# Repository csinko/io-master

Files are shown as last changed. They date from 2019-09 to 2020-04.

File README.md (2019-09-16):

# io-master
Dominate the I/O!

## Subsystems Overviews

### [GUI](https://github.com/csinko/io-master/wiki/GUI-Subsystem)
The purpose of the GUI interface is to create a user friendly yet customizable program to help users tell the micro-controller to use whatever protocols that the user wishes to use from the provided list. The interface will include drop down menus to adjust the protocol that the board will use.  This interface will also allow the user to select what information they want to send through the device as well as start and stop the flow of information through the device. The GUI will also define the hardware pins and clock speeds needed to run whichever protocol is selected. This includes setting the voltage levels that the board will expect to see. This will define what is seen as a 1 or a 0. The gui will most likely be done using python. Possible challenges include figuring out which GUI base to use in python. Possible options are appJar, TkInter, PyQT, or Kivy. More research will be done on each to figure out which one is best suited for this project. 

### [MCU Firmware](https://github.com/csinko/io-master/wiki/MCU-Firmware-Subsystem)
The MCU is responsible for reading and writing the logic. Firmware will need to be designed to load in data from the computer, connect it to the corresponding DMA register that routes to the correct output, and stream data as it comes in. Likewise, the firmware will also need to read in data over the DMA, and transfer it to send to the computer when appropriate. Strict scheduling and context switching will need to be designed in order to ensure smooth operation at high frequencies. Other contexts will need to be considered, such as reading from one set of I/O and writing to another set, or recording logic data read in to an SD card.

### [MCU Power and Interface](https://github.com/csinko/io-master/wiki/MCU-Power-and-Interface-Subsystem)
MCU Power and Interface is responsible for receiving configuration and executing commands. These commands will come through the serial bus and need to be parsed/decoded. Execution will include adjusting the clock speed, target voltage levels, and re-configuring pins as specified by the commands received.

These capabilities will be crucial for switching between protocols on the multi-use pins. The challenges will be primarily with creating a good control scheme for managing all the necessary multiplexers to route signals to all the proper pins, at the correct speed and voltages.

### [I/O Level Shifting and Logic](https://github.com/csinko/io-master/wiki/IO-Level-Shifting-and-Logic-Subsystem)
The Level Shifting and Logic Subsystem is responsible for providing electrical conversion between the microcontroller interface and the device under test. This includes acting as an output and input to the microcontroller, providing logic-high, logic-low, and floating output states, bidirectional logic-level conversion, and capability to drive/receive differential or single-ended lines. This block should be fully configurable via control signals from the microcontroller. This includes setting the high and low voltages, optional pull-up/pull-down resistors, and multiplexing the line between single-ended and differential hardware. Design challenges include implementing a bidirectional differential transceiver and ensuring that multiplexing does not affect high speed operation.

### [Circuit Protection](https://github.com/csinko/io-master/wiki/Circuit-Protection-Subsystem)
Circuit protection is a crucial part of any device to help safeguard against unexpected and unplanned power issues. This is important to prevent injury to users, damage to the device and potentially fire. This will include having fuses, diodes, conformal coating, reverse polarity protection, over voltage protection and will protect against accidental grounding.
Some challenges that may occur is due to the learning curve of designing the circuit protection circuit. Designing a circuit that can account for over voltage protection, short circuit protection, reverse polarity protection, etc and maintain a small footprint on a circuit board could prove to be difficult. Accounting for different/higher voltage levels used by the different protocols may become a challenge.

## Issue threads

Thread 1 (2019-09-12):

Preliminary Circuit Protection Design

codeThatThinks, 2019-09-12:
- Research what kinds of things I/O pins need to be protected against
- Research possible protection circuits
- Begin preliminary schematic of protection subsystem

nuntch, 2019-09-16:
This is what I have so far:
Over voltage protection
Over current protection
Accidental grounding
Reverse polarity protection

nuntch, 2019-09-30:
Weekly update:
I have a circuit sketched to protect against reverse polarity and over current issues.
I won't be back in town until about noon today.

This week i will be taking my schematic and begin creating the design in kiCad.

Closed 2020-01-16.

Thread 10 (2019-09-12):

Make a short writeup about the GUI

csinko, 2019-09-12:
This will be put into the readme and be used for preliminary design presentations and discussions.

Cover what this component is responsible for, what it adds to the design of the project, and some challenges that will arise.  Also cover any preliminary design ideas that exist.

Metalison, 2019-09-15:
The purpose of the GUI interface is to create a user friendly yet customizable program to help users tell the micro-controller to use whatever protocols that the user wishes to use from the provided list. The interface will include drop down menus to adjust the protocol that the board will use.  This interface will also allow the user to select what information they want to send through the device as well as start and stop the flow of information through the device. The GUI will also define the hardware pins and clock speeds needed to run whichever protocol is selected. This includes setting the voltage levels that the board will expect to see. This will define what is seen as a 1 or a 0. The gui will most likely be done using python. Possible challenges include figuring out which GUI base to use in python. Possible options are appJar, TkInter, PyQT, or Kivy. More research will be done on each to figure out which one is best suited for this project.

csinko, 2019-09-16:
Looks good

Closed 2019-09-16.

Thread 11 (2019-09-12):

Make a short writeup about the Circuit Protection

csinko, 2019-09-12:
This will be put into the readme and be used for preliminary design presentations and discussions.

Cover what this component is responsible for, what it adds to the design of the project, and some challenges that will arise.  Also cover any preliminary design ideas that exist.

nuntch, 2019-09-16:
Short write up about circuit board protection
Circuit protection is a crucial part of any device to help safeguard against unexpected and unplanned power issues. This is important to prevent injury to users, damage to the device and potentially fire. This will include having fuses, diodes, conformal coating, reverse polarity protection, over voltage protection and will protect against accidental grounding.
Some challenges that may occur is due to the learning curve of designing the circuit protection circuit. Designing a circuit that can account for over voltage protection, short circuit protection, reverse polarity protection, etc and maintain a small footprint on a circuit board could prove to be difficult. Accounting for different/higher voltage levels used by the different protocols may become a challenge.

Closed 2019-09-16.

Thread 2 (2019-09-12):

Preliminary Level-Shifter Design

codeThatThinks, 2019-09-12:
Subsystem preliminary functions/requirements:
* Bi-directional level shifting from mcu logic levels (3.3v) to output logic levels (anywhere from 3.3-24v)
* Implement high, low, and tri-state (floating)
* Implement pull-up and pull-down resistors
* Selectable single-ended or differential signalling mode

codeThatThinks, 2019-09-26:
I'm going to focus first on the differential signalling portion of the design since I believe it is the part that requires the most research. I need to determine the requirements for configurable differential logic levels as well as a way to integrate it as a selectable option with the single-ended level shifter.

Here is a comparison of various common differential interfaces:

__RS-422/RS-485__
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
* Binary 1: -6V < A - B < -200mV
* Binary 0: +200mV < A - B < +6V
* Common Mode: -10 to +10V (RS-422), -7 to +12V (RS-485)
* Termination, pull-up, pull-down resistors required
* Up to 10 Mbit/s

__CAN (ISO 11898)__
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
* Binary 1 (Recessive): -1V < CANH - CANL < +0.5V
* Binary 0 (Dominant): +0.9V < CANH - CANL < +5V
* Common Mode: -2 to +7V
* Termination, pull-up, pull-down resistors required
* Up to 2Mbit/s

__LVDS (TIA-644)__
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
* 350mV voltage swing, 1.2V common mode offset typical
* Current direction determines logic state
* Terminator resistor required
* 655 Mbit/s (up to 3Gbit/s possible)

_References_
* [RS-422 and RS-485 Standards Overview and System Configurations](https://www.ti.com/lit/an/slla070d/slla070d.pdf)
* [A CAN Physical Layer Discussion](http://ww1.microchip.com/downloads/en/AppNotes/00228a.pdf)
* [Basic Principles of LVDS](https://www.thine.co.jp/en/contents/articles_detail/serdes-lvds.html)

codeThatThinks, 2019-09-26:
Clearly a differential driver/receiver must be able to handle interfaces where pairs are simply inverted (e.g. RS-485) and interfaces where pairs are mirrored (e.g. CAN) and hover around a common voltage. The specific logic levels vary significantly between interfaces, so differential hardware likely needs to include level shifting of its own and not rely on the single-ended level shifting hardware.

A revised block diagram might look like the following:

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

I will have to determine if an off the shelf transceiver chip can be used. The challenge here will be finding something where differential logic levels can be selected. Maybe a circuit could be placed on the front end of the transceiver to shift voltages? Depending on the differential spec, up to 4 separate voltage rails might be needed, each programmable, and 4 for each I/O channel/pair.

If it came down to implementing a custom transceiver, there are multiple approaches. A naive solution might be to provide 4 configurable voltage rails: 1 for each voltage state of each differential line. This would allow for maximum configurability for any differential scheme, at the expense of requiring many voltage rails when scaling up the number of I/O channels. A better solution might be to take advantage of the symmetry of the differential pair. Use 2 voltage rails to define the two voltage states for one differential line, then invert the signal to use as the opposite line.

Closed 2020-01-16.

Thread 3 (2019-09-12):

Preliminary Microcontroller Schematic

codeThatThinks, 2019-09-12:
Draw up a schematic for the STM32F7 chip including power supply for mcu.

- Find/create KiCAD symbol for mcu
- Voltage regulator for mcu
- Decouping

Closed 2020-01-16.

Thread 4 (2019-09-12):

Research GUI options for Python

csinko, 2019-09-12:
We will want a UI for users to define, edit, and select protocols for our tool.  Users will need to be able to

- Define clock signal speeds
- Set expected voltage levels
- Define ranges for a logic 0 and a logic 1
- Give names and descriptions for protocols
- Select protocols being used, assign pins
- Select data to send
- Start and stop the device, along with other operations

There are a few options I am aware of that can be used for GUIs in Python
PyQT
Tkinter
Kivy

Do research and testing on these frameworks, and get a feel for making GUI elements with Python.  Decide the pros and cons of all the frameworks you test, and we will decide which one to use officially for the project.

codeThatThinks, 2019-09-26:
Check out ```guizero```, it's a Python library that makes it much easier to use TkInter. https://lawsie.github.io/guizero/

Metalison, 2019-09-30:
Weekly Update:
Started practicing using tkinter. A window appears and it has words and buttons that work.

nuntch, 2019-10-10:
See google drive for the requirements needed for GUI sketch.
Due by our next meeting with French. 10/17/19

Closed 2020-01-16.

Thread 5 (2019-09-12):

Research and Test Clock Inputs with MCU

csinko, 2019-09-12:
We will need to be able to patch in and switch between different frequencies for the project.   The MCU has the ability to use an external clock, but we need the flexibility to set these clocks and assign them to various I/O lines (potentially multiple lines simultaneously.

Learn how to read in and use external clock signals, make a test application to utilize external clock signals, and determine how we can control where a clock signal connects to, whether its through software routing or hardware routing (mux, demux, etc.)

WhoDaWhatNow, 2019-09-26:
STM32H743 Datasheet link: https://www.st.com/resource/en/datasheet/stm32h743bi.pdf
page 126 talks about clock inputs

STM Timers: https://www.st.com/content/ccc/resource/technical/document/application_note/group0/91/01/84/3f/7c/67/41/3f/DM00236305/files/DM00236305.pdf/jcr:content/translations/e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

Closed 2020-01-16.

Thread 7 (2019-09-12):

Make a short writeup about the I/O Level Shifting And Logic

csinko, 2019-09-12:
This will be put into the readme and be used for preliminary design presentations and discussions.

Cover what this component is responsible for, what it adds to the design of the project, and some challenges that will arise.  Also cover any preliminary design ideas that exist.

codeThatThinks, 2019-09-16:
The Level Shifting and Logic Subsystem is responsible for providing electrical conversion between the microcontroller interface and the device under test. This includes acting as an output and input to the microcontroller, providing logic-high, logic-low, and floating output states, bidirectional logic-level conversion, and capability to drive/receive differential or single-ended lines. This block should be fully configurable via control signals from the microcontroller. This includes setting the high and low voltages, optional pull-up/pull-down resistors, and multiplexing the line between single-ended and differential hardware. Design challenges include implementing a bidirectional differential transceiver and ensuring that multiplexing does not affect high speed operation.

Closed 2019-09-16.

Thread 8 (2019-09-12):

Make a short writeup about the MCU power and interface

csinko, 2019-09-12:
This will be put into the readme and be used for preliminary design presentations and discussions.

Cover what this component is responsible for, what it adds to the design of the project, and some challenges that will arise.  Also cover any preliminary design ideas that exist.

WhoDaWhatNow, 2019-09-16:
MCU Power and Interface is responsible for receiving configuration and executing commands. These commands will come through the serial bus and need to be parsed/decoded. Execution will include adjusting the clock speed, target voltage levels, and re-configuring pins as specified by the commands received.

These capabilities will be crucial for switching between protocols on the multi-use pins. The challenges will be primarily with creating a good control scheme for managing all the necessary multiplexers to route signals to all the proper pins, at the correct speed and voltages.

WhoDaWhatNow, 2019-09-16:
@csinko Is this good?

csinko, 2019-09-16:
looks good

Closed 2019-09-16.

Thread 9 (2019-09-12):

Make a short writeup about the MCU Firmware

csinko, 2019-09-12:
This will be put into the readme and be used for preliminary design presentations and discussions.

Cover what this component is responsible for, what it adds to the design of the project, and some challenges that will arise.  Also cover any preliminary design ideas that exist.

csinko, 2019-09-16:
The MCU is responsible for reading and writing the logic.  Firmware will need to be designed to load in data from the computer, connect it to the corresponding DMA register that routes to the correct output, and stream data as it comes in.  Likewise, the firmware will also need to read in data over the DMA, and transfer it to send to the computer when appropriate.  Strict scheduling and context switching will need to be designed in order to ensure smooth operation at high frequencies.  Other contexts will need to be considered, such as reading from one set of I/O and writing to another set, or recording logic data read in to an SD card.

Closed 2019-09-16.

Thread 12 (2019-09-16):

Create DMA Routing program

csinko, 2019-09-16:
To better learn how to operate DMA and to get an idea of the flexibility possible, create a program that reads data from one interface into DMA, then outputs the data out another interface.

Attempt any forms of optimizations that seem possible to limit the amount of interrupts.  Also do tests to limit the amount of memory used in the buffer when streaming data, as this will open up opportunities to increase the throughput of the device

Closed 2020-01-16.

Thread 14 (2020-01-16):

Determine USB Protocol Implementation for High Speed I/O

csinko, 2020-01-16:

csinko, 2020-01-26:
Currently investigating using this: https://github.com/IntergatedCircuits/IPoverUSB

This library will let us use an NCM based USB device to transmit data like an IP-based device.

It supports the STM32F4 but not the H7.  I am in the process of porting over the code to run on the H7, but it is bare metal so there are a lot of things to change

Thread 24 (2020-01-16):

Design Command Structure for Board Configuration

csinko, 2020-01-16:
Come up with a list of commands that we need to implement, and figure out how many bits are needed for them.

Then create a document that lists what each command is, how to use it, etc.

Also determine any sort of machine states are necessary for the device to accept the command.  i.e. It wouldn't make sense to change the frequency while sending data!

WhoDaWhatNow, 2020-01-30:
https://docs.google.com/spreadsheets/d/1bnIgJ0D3f-U6nXkwTM4AM9xzIl1RVUJrsCMVExMmpjs/edit#gid=0

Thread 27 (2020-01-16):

Determine what pins we need for I/O

csinko, 2020-01-16:
Finalize what pins we are going to use

codeThatThinks, 2020-01-31:
The pin allocation spreadsheet lists all the pins we are going to use.

TLDR:
- ULPI interface used to communicate with USB PHY, these pins cannot be reassigned
- PORTD is used only for high speed digital outputs to the level shifter (low byte is IO_x_OUT, high byte is IO_x_TRIS)
- PORTE is used only for high speed digital inputs from the level shifter (low byte is NC, high byte is IO_x_IN)
- There is a dedicated hardware timer that is tied to each high speed digital output used for clock generation. Simply enable tristate for the PORTD pin and disable tristate for the timer output pin.
- I2C1 is used for communication to all level shifter DACs.
- USART1 will be broken out with test points in case it needs to be used for debugging/DFU mode
- DAC_OUT1 is used to control the adjustable regualtor for powering the target device

codeThatThinks, 2020-02-13:
@WhoDaWhatNow I've changed some of the pin assignments in order to make the board layout easier. Please review the spreadsheet on drive.

Closed 2020-01-31.

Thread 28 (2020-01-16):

Microcontroller subsystem schematic

codeThatThinks, 2020-01-16:
Draw up a schematic of the STM32H7 with:

- Power supply and decoupling
    --Pick a 3.3v linear regulator (maybe a 250mA)
- Crystal oscillator and clock source
    --Do we need two, one for the CPU, one for the USB
    --Capacitors needed as well
- Reset circuit
    --Hardware reset button
    --How did the development board do it?
- Programming/debug header
- USB interface
    --See USB issue

Closed 2020-01-28.

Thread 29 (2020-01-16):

USB PHY circuit design

codeThatThinks, 2020-01-16:
Choose a USB PHY from Digikey so that we can used USB 2.0 High Speed on the microcontroller. Draw up a schematic with USB connector, USB protection, PHY chip, and microcontroller interface.

csinko, 2020-01-26:
I would like to review which design is selected before we order it.  There's many options for the USB interface that I am using and I want to make sure what we both use are compatible with eachother.

I would expect it to be regular USB HS, but I am seeing a lot of stuff relating to OTG, which seems odd.  Its possible that portion of the library is used for other functions, the pins are shared, or something of that sort.

nuntch, 2020-01-28:
Schematic is done. Waiting for review on 1/30.

codeThatThinks, 2020-01-30:
ST refers to the built-in USB peripheral on the MCU as "USB OTG" even though it supports a variety of USB modes, including host, device, and OTG (switchable between host/device).

I/O Master will likely use the HS Device mode with an external PHY. The Microchip USB3300 PHY uses a ULPI interface to communicate with the MCU. This interface uses different pins and does not include the MCU's USB D+ and D-. We will include test points for the MCU D+ and D- pins in case we ever want to use the built-in USB PHY for full speed.

The pin allocation spreadsheet lists the pins used for the ULPI interface.

Closed 2020-01-30.

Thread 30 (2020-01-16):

Redesign level shifter

codeThatThinks, 2020-01-16:
Redesign the level shifter to include a proper gate driver so that 10MHz can be achieved.

- discrete output stage with gate driver
- discrete input stage with proper voltage range
- draw up pull-up/pull-down/termination resistors

codeThatThinks, 2020-01-21:
The output driver has been completely redesigned for switching speed. Given the original engineering specs regarding voltage levels, 20MHz is not possible without a significantly more complex system.

The voltage rails have been reduced to +/-15V and the bidirectional FETs have been replaced with a simpler PMOS/NMOS pair to make the driver requirements easier. The transistors were selected based on threshold voltage, gate charge, and input capacitance with the lowest allowable voltage rating so fast switching speeds can be achieved. Package size was reduced and both transistors are combined into a single package to minimize parasitic capacitances and inductances. A discrete isolated gate driver is likely too complex to realistically implement, so the Si8275 dual gate driver was selected. Since at 20Mbps the pulse width is 50ns, the Si8275 with a 12ns rise/fall time will be pushed to its limit on switching speed. The practical output frequency is likely just under 20MHz.

Since the gate drive voltages are fixed at +/-15V to ensure that the transistors are fully on/off at all possible logic levels, this driver will likely have a lot of EMI due to a high dv/dt. The control software should limit output voltage/switching speed, e.g. no more than 5V @ 20MHz (1e9 V/s), to limit the EMI on the transistor drains. Resistors have been included on the transistor gates so that the rise and fall times can be fine tuned on the bench.

For rev 2, the level shifter system design should be reconsidered. A direct digital synthesis approach might be better suited to achieve less EMI and better rise times. A high speed DAC could be used to generate a 0-3.3V waveform and then scale it up to +/-15V with a high speed amplifier. The lack of discrete transistors would allow for a much greater switching speed and the highest switching voltage anywhere in the level shifter would never exceed the maximum waveform voltage, allowing dv/dt to be tightly controlled by software.

codeThatThinks, 2020-01-28:
The output driver has been changed again to a high-speed op-amp and high-speed analog switch. The power rails of the op-amp are set to the desired logic level voltages and the analog switch can be used to disconnect the op-amp from the output for tri-state mode.

This configuration is simpler than the gate driver setup, with the benefit of less EMI since we're no longer switching +/-15V for the gate drive. Testing needs to be done to determine if the performance is good enough considering the op-amp's recommended voltage range, bandwidth, and slew rate, as well as whether the analog switch can be enabled quickly to achieve 400KHz I2C operation.

codeThatThinks, 2020-01-28:
The receiver has been redesigned so that the comparator is actually operating within its recommended input voltage range. My research suggests that op-amps operating in an open-loop configuration as comparators should be avoided. However, high voltage comparators are not readily available with the speed requirements we need.

The new receiver design uses the LM7171 high-speed op-amp to scale down the input voltage from +/-15V to 0~3.3V in a way very similar to the scaling of the DAC outputs. This resulting 3.3V signal can then be used with a lower voltage high-speed comparator. The receiver threshold voltages must also be scaled down, but since they are generated by scaling the DAC outputs, the comparator can use the DAC output directly to avoid scaling up followed by scaling down. A third LM7171 is used to take the difference between the I/O pins when in differential mode. An additional single channel DAC has been added to generate the differential receiver threshold voltage. This simplifies the hardware design for generating this voltage, as it depends on whether either I/O pin is inverted in software. Two SPDT analog switches are used to multiplex the input signal and threshold voltage for one of the comparators. In single-ended mode, the comparator uses the I/O pin input signal directly and the average of the logic level voltages, (VH + VL) / 2, as a threshold. In differential mode, the comparator uses the difference signal as input and the DAC-generated threshold voltage.

Closed 2020-01-28.

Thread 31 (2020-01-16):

Design adjustable regulator

codeThatThinks, 2020-01-16:
Design an adjustable regulator for powering the target device. Must be 3-24V output, 100mA.

Closed 2020-02-02.

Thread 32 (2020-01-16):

Review level shifter DAC design

codeThatThinks, 2020-01-16:
- Check DAC reference voltage
- Check op-amp gain and resistor tolerances
- Maybe add calibration using mcu adc pins?

codeThatThinks, 2020-01-27:
It seems that all Microchip DACs default to the interval reference on power up. This is not an issue, just another step that software needs to take when initializing everything.

codeThatThinks, 2020-01-27:
The op-amp gain equation for the demo board is:

```Vout = 1000/68 * (1.65 - Vdac)```

With +/-24V rails, the target gain was 48/3.3 = 14.545, so using standard resistor values the gain is a little off, 1000/68 = 14.705.

The resistors are 1% tolerance. If the resistors are at the opposite ends of their tolerance, and the DAC output is at its maximum, then the output is actually:

```(1000 * 1.01)/(68 * 0.99) * (1.65 - 3.3) = -24.755```

That is an error of 0.755V, which is significant. Note, this is an approximation since the actual gain equation is more complicated when the resistance is not the same for each pair of resistors, so in reality the output would be off by even more.

For rev 1, the power rails are now +/-15V, so the new gain equation is:

```Vout = 1000/110 * (1.65 - Vdac)```

This ratio of nominal resistor values actually matches the target gain, where 1000/110 = 30/3.3 = 9.09. If 1% resistors are used, then the maximum error is approximately 0.303V. This is still probably too much, as it should really be somewhere around +/-0.1V. Therefore, 0.1% resistors should be used.

codeThatThinks, 2020-01-27:
The differential receiver threshold voltage will be replaced with a 1 channel DAC for rev 1. This simplifies the board layout a lot and cuts down on the BOM cost. This way, the software will have to calculate the required receiver threshold voltage and set it when switching to differential mode. If this were to be done in hardware, a 4 channel 4:1 demux (a 24 pin chip) + dual opamp circuit would be required to handle all of the threshold voltage combinations depending on whether or not the microcontroller output is inverted. That is for each I/O channel pair. (We need to be able to invert an I/O channel output in software in order to handle some differential protocols).

I've chosen the 1 channel version of the MCP4728, which is the MCP4725. An op-amp circuit similar to the 4 ch DAC will be used to scale the output to +/-15V.

codeThatThinks, 2020-01-27:
I think we will have enough pins free on the MCU to run each DAC output to an ADC channel. For 4 I/O channels, that will be (4 + 1) * 2 = 10 DAC outputs. We can choose whether or not we want to use this for calibration, and whether or not we need it, but for rev 1 I will include it on the board.

We might run into issues noise coupling onto the ADC lines, which might make calibration difficult/impossible, but we need to build it to find out.

Closed 2020-01-27.

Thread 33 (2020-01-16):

Investigate VCO

codeThatThinks, 2020-01-16:
- See if a VCO with digital interface can be used to prevent clock jitter
- Look at generating required clocks internally

codeThatThinks, 2020-01-30:
After some research, it doesn't seem feasible to use a VCO. Most VCOs are analog input, which might not be able to generate a stable clock due to noise on the analog input.

Closed 2020-01-30.

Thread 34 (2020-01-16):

Circuit Protection Schematic

codeThatThinks, 2020-01-16:
Draw up the circuit protection circuit in Kicad that was used during the end of semester demo.

nuntch, 2020-01-30:
Design created in KiCad, ready for PCB design

Closed 2020-01-30.

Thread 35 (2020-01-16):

Rev 1 Schematic and BOM

codeThatThinks, 2020-01-16:
Combine all subsystem schematics into one complete KiCAD project. Generate a BOM.

codeThatThinks, 2020-01-30:
TODO before design review:
- [ ] Microcontroller pin assignments
- [ ] Finish adjustable regulator design
- [ ] LEDs on microcontroller I/O to level shifter
- [ ] Choose a connector for I/O pin connection to target device
- [ ] Choose indicator LEDs for power rails, calculate resistor values
- [ ] Add fuse or current shunt on main power input?
- [ ] Add fuse on target device power output
- [ ] Add test points for UART and built-in USB on microcontroller

codeThatThinks, 2020-02-02:
For rev 1, we can just go with a 0.1" female header. We can explore other connector possibilities for rev 2.

codeThatThinks, 2020-02-05:
Minor schematic issues have been fixed. A FET was added on the power input circuit so that the DC jack is always used instead of USB whenever it is plugged in (before it was whichever was higher voltage).

The SPDT switch on the level shifter input circuit was replaced with a part that actually has a +/-15V operating voltage range.

Component values were updated and schematic text was revised.

codeThatThinks, 2020-02-05:
The BOM is complete and the schematic is ready for a design review.

Closed 2020-02-05.

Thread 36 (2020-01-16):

Rev 1 PCB Layout

codeThatThinks, 2020-01-16:
Draw up a complete PCB design with all subsystems.

codeThatThinks, 2020-02-05:
All custom footprints that we need have been created.

codeThatThinks, 2020-02-13:
PCB layout is complete and it has been ordered from OSH Park.

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

Closed 2020-02-13.

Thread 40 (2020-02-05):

Rev 1 Design Review

codeThatThinks, 2020-02-05:
A thorough design review is needed of the Rev 1 schematic, BOM, and PCB layout.

This is a placeholder for any issues that come up.

- [ ] lorem ipsum

Closed 2020-02-13.

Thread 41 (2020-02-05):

Optimize Pull-up/Pull-down Circuit

codeThatThinks, 2020-02-05:
Redesign the pull-up/pull-down circuit so that the control pins are multiplexed. Idea: use a tri-state output to control them (LOW: pull-down enabled, HIGH: pull-up enabled, High-Z: both disabled)

This would save 8 MCU pins, allowing us to use the LQFP100 package: 8 PU, 8 PD pins -> 8 PU/PD pins

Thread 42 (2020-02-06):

Optimize +/-15V Regulator

codeThatThinks, 2020-02-06:
- Calculate actual required current rating and adjust circuit design
- Recalculate inductor sizing
- Investigate cheaper alternatives to ADP5070 chip

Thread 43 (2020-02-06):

Optimize Level Shifter

codeThatThinks, 2020-02-06:
- Investigate more cost effective designs

- Output Driver ideas
  - MCU -> DAC -> Linear Amplifier
  - MCU -> Shift Register -> High Speed Mux -> Parallel DAC -> Linear Amplifier

- Receiver ideas
  - ???

codeThatThinks, 2020-02-20:
The high speed op-amps have a much higher quiescent current than expected. For 10 op-amps, the quiescent current is ~43mA per power rail, for a total of 1.27W.

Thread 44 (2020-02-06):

Determine Mid-Term Demo

codeThatThinks, 2020-02-06:
Choose a specific SPI device for the mid-term demo. Make a write up with the following:

- Specific device and communication specs
- Info from datasheet that the end user would need to know
- What capabilities of the I/O Master are actually being demonstrated

codeThatThinks, 2020-02-06:
We will use a Sparkfun SerLCD module. This is an OLED module with UART, I2C, and SPI interfaces. It's a character display, so we will only need to send it ASCII text and it will display it. This module supports 4-wire SPI communication, so we can demonstrate sending and receiving data.

In Stock @ Digikey
https://www.digikey.com/short/z3mmwr
P/N: 1568-1904-ND

codeThatThinks, 2020-02-06:
Demo will consist of:
- Send text string to module, display on screen
- Send read version command to module, read version number

codeThatThinks, 2020-02-20:
SPI Data for Demo:

* __Clear the display, move cursor to home position__
  * Begin communication (CS low)
  * 0x7C "|" (enter settings mode)
  * 0x2D "-" (clear display, move cursor to home)
  * End communication (CS high)
* __Send "I/O MASTER" to display__
  * Begin communication (CS low)
  * 0x49 "I"
  * 0x2F "/"
  * 0x4F "O"
  * 0x20 " "
  * 0x4D "M"
  * 0x41 "A"
  * 0x53 "S"
  * 0x54 "T"
  * 0x45 "E"
  * 0x52 "R"
  * End communication (CS high)

The SerLCD doesn't actually send any data back for any commands. We will need to modify the Arduino firmware to reply to the firmware version command. An FTDI adapter can be used to update the firmware.

codeThatThinks, 2020-02-20:
SPI communication is Mode 0:
- CPOL = 0
- CPHA = 0

codeThatThinks, 2020-02-20:
SerLCD firmware has been modified to send firmware version over SPI: https://github.com/codeThatThinks/OpenLCD.

* __Read firmware version from display__
  * Begin communication (CS low)
  * 0x49 "|"
  * 0x2C "," (read firmware version)
  * 0x00 (read byte on MISO)
  * 0x00 (read byte on MISO)
  * 0x00 (read byte on MISO)
  * 0x00 (read byte on MISO)
  * End communication (CS high)

Closed 2020-02-20.

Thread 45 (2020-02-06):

Determine Final Demo

codeThatThinks, 2020-02-06:
Choose specific devices that demonstrate SPI, I2C, RS-232, RS-485, and SWD communication, as well as all of the key features of the I/O Master.

codeThatThinks, 2020-02-06:
SPI
- Sparkfun SerLCD, up to 4Mbps
- 1568-1904-ND

I2C
- MPL115A2 Temperature/Barometric Pressure Sensor, up to 400KHz
- 1528-1172-ND

RS-232
- FTDI RS-232 to USB adapter, send to computer, up to 2Mbps

RS-485
- AMT213A-V Rotary Encoder, 2Mbps
- 102-4526-ND

SWD
- Verify the program on an STM32 Blue Pill

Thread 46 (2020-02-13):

Optimize Overcurrent Protection Circuit

codeThatThinks, 2020-02-13:
See if we can redesign this circuit to use discrete transistors instead of op-amps. We need to reduce the part count and BOM cost.

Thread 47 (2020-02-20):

Setup Boot Sequence and initialization steps for MCU

csinko, 2020-02-20:
The following must be initialized for the MCU upon startup:

- All pins should be configured as inputs on first boot

When a configuration is set, the following must be changed to outputs for each IO Pin:
- Output pin -> Output, Timer Pin -> Input, Input Pin -> Input
- Output pin -> Input, Timer Pin -> Output, Input Pin -> Input
- Output pin -> Input, Timer Pin -> Input, Input Pin -> Input

^^ These are the only states that should be allowed

When switching between output pin and timer pin, MUST switch BOTH output pin and timer pins to inputs before setting the other pin as an output.  This ensures we do not short anything on the board.

**All Unused pins should be set to output and driven low.**

The Termination and Pulldown resistor control pins along with the tristate pins are active low, so they should be set high when made into outputs

The differential pins are active high, set to low when made an output (default to single ended)

The DAC needs to be set to whatever value correlates to ~1.4 volts (needs calculated)

@codeThatThinks, we also need to measure the amount of time it takes for the DAC to be set from first turning on with a scope.

csinko, 2020-02-22:
All of the initial pin configuration has been done with 5f4e88aaa68fd4bc49f22c1297d72b6442a4038c

The gpio.c file contains all of the initialization code for the pins: https://github.com/csinko/io-master/blob/5f4e88aaa68fd4bc49f22c1297d72b6442a4038c/mcu/io_master/mcu/stm32h743/src/gpio.c

Still need to add code to handle controlling the I/O Pin states for the above modes, handle the DAC, and need to test that all of the added code is working

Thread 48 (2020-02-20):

Rev 2 Schematic and BOM

codeThatThinks, 2020-02-20:
Revise the schematic and BOM for the I/O Master v2 hardware.

codeThatThinks, 2020-02-20:
TODO before design review:

- [ ] Adjustable regulator enable pin should be wired to the mcu with a pull down

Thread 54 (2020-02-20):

Optimize 3.3V Regulator

codeThatThinks, 2020-02-20:
The current linear regulator dissipates 1.555W of heat when using the 12V DC input. Total 3.3V rail load is estimated at about 178mA, so the regulator should be replaced with one spec'd for 200mA. We might want to change it to a switching regulator in order to improve efficiency.

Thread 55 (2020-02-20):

Optimize Power Input Circuit

codeThatThinks, 2020-02-20:
The power input OR'ing diodes dissipate a significant amount of power when operating near maximum power input. The USB FET switch dissipates a lot less power (0.018W vs. 0.160W).

We might want to investigate using ideal diodes or somehow eliminating the OR'ing diodes.

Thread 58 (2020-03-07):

MCU Voltage Levels Not Close to 0V/3.3V

codeThatThinks, 2020-03-07:
The MCU logic levels on the IO_OUT, IO_TRIS, IO_CLK pins do not appear to be close to the expected HIGH/LOW voltages: 3.3V and 0V. The issue is mainly with the LOW voltage.

codeThatThinks, 2020-03-07:
All MCU pins have 100K pull-up/pull-down resistors to set a defined state when the MCU pin is not being driven (i.e. MCU is starting up, pin configured as an input, etc.).

Upon inspection of the circuit connected to the MCU pin, it appears that the pin voltage can rise above 0V in a specific situation.

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

When the IO_TRIS pin is set HIGH (3.3V), the combination of the LED current limiting resistor and pull down resistor form a voltage divider, causing the voltage on the MCU pin to go to ~0.7V. When IO_TRIS is LOW (0V), this issue does not exist. This issue also does not exist when the MCU is actively driving the pin HIGH and LOW.

For Rev 2, the output LED should be changed so that it is no longer between two MCU pins. The IO_TRIS pin should get its own indicator LED.

codeThatThinks, 2020-03-07:
More bench testing with the LM7171 on a breakout board:

The LM7171 inputs appear to float to ~5V when not connected to anything. With the inverting input tied to 1.65V and the non-inverting input pulled down to ground through a 100K resistor, the voltage on the non-inverting input is around 0.228V. This indicates an input current of around 2uA. It might be a good idea to make the pull down resistors smaller, possibly 10K.

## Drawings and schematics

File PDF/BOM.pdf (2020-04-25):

I/O Master v1.0 - Populated Parts | Qty 1 | Qty 100

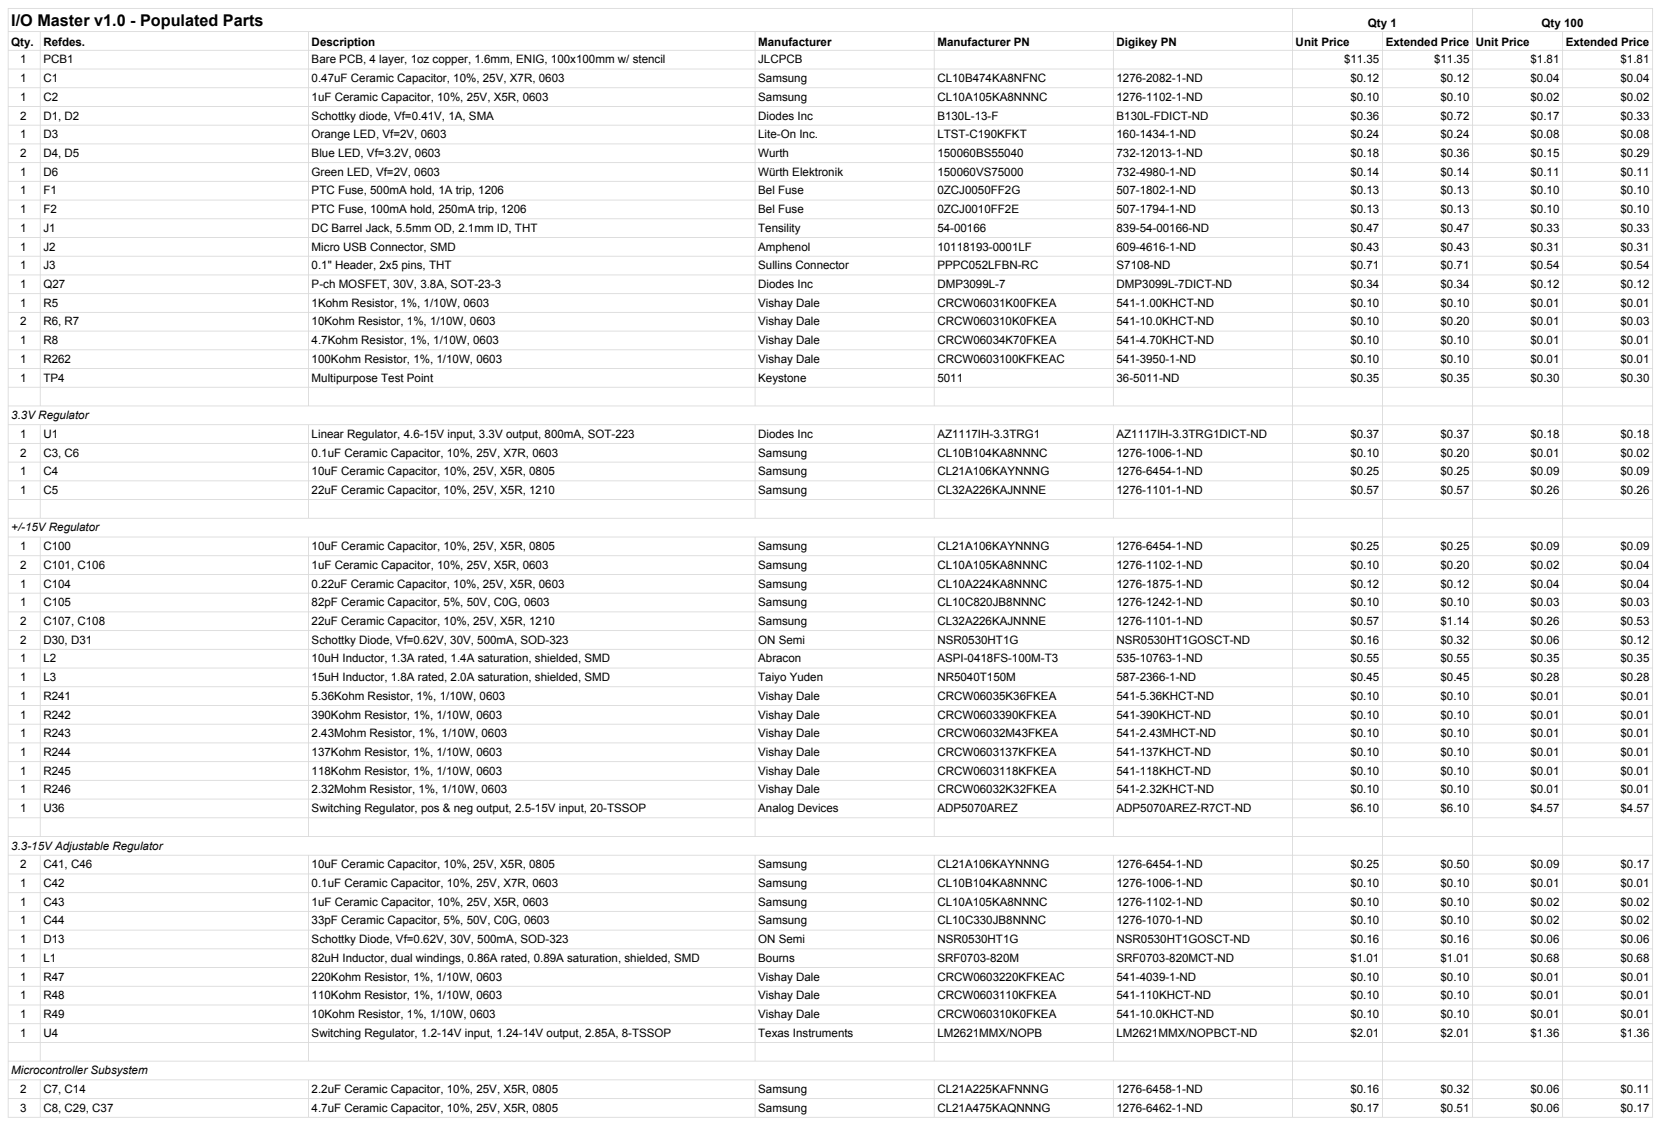
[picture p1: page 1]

I/O Master v1.0 - Populated Parts | Qty 1 | Qty 100

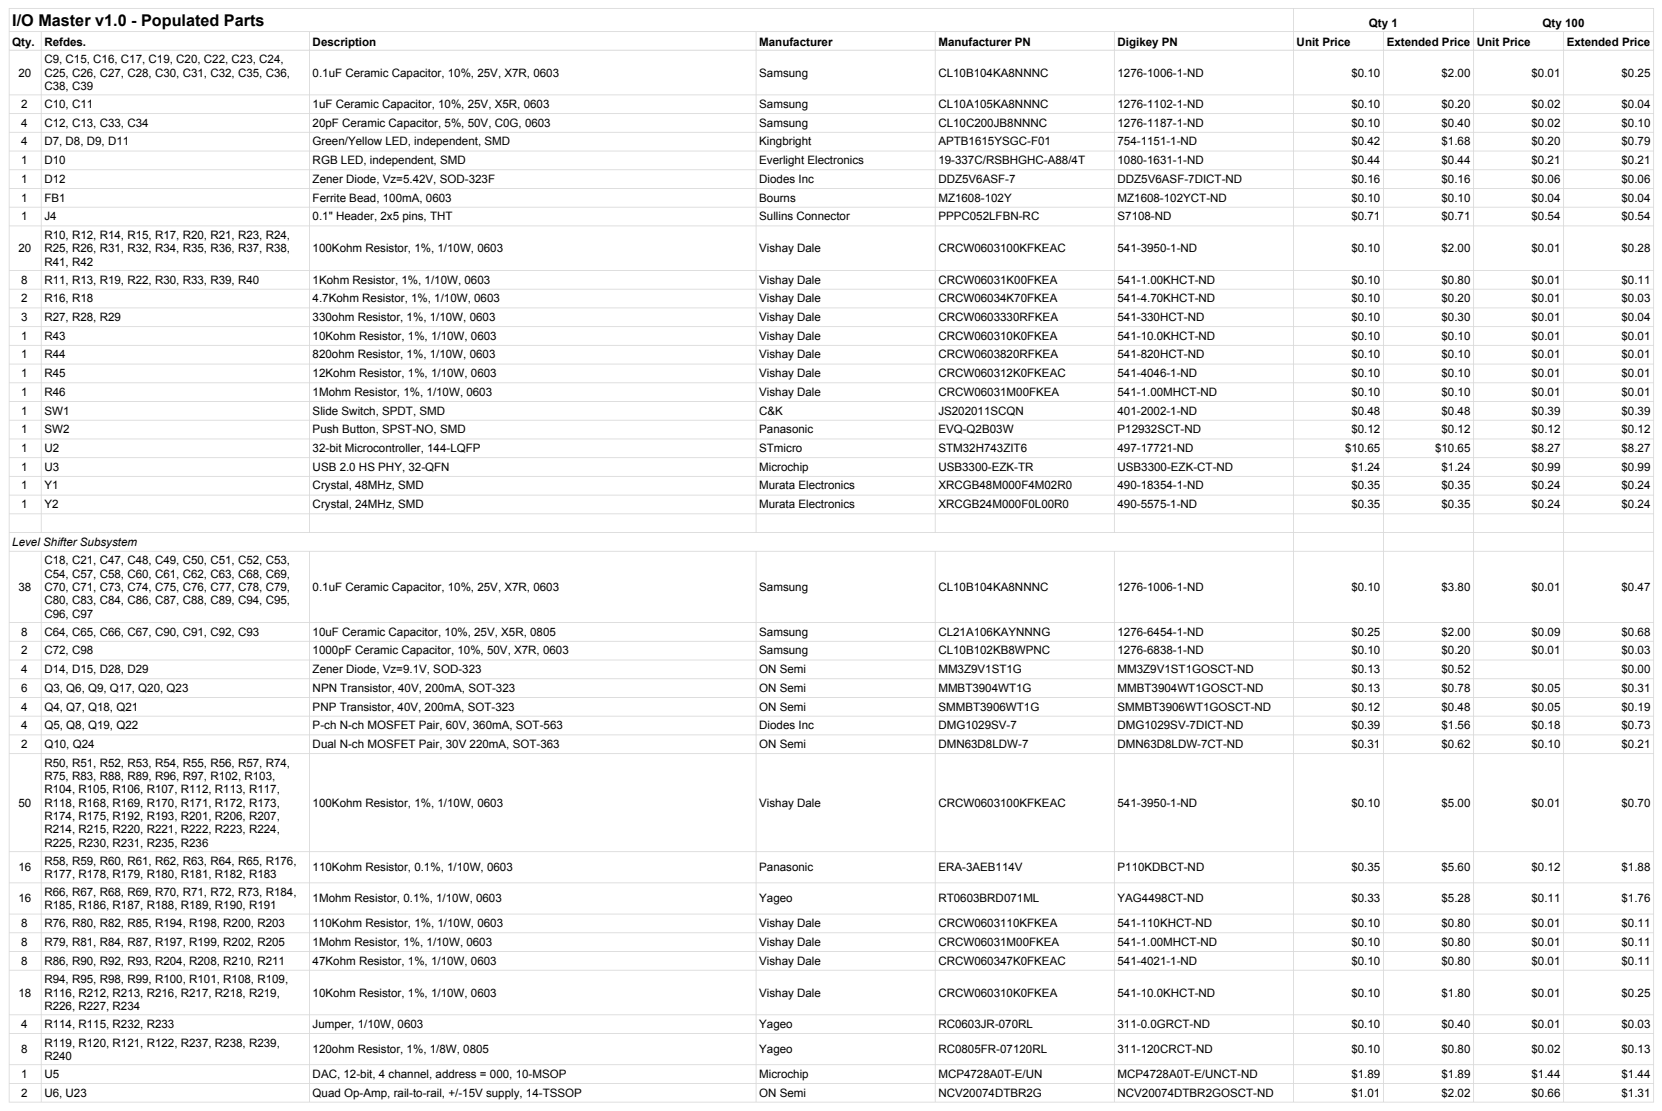
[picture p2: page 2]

Qty. | Refdes. | Description | Manufacturer | Manufacturer PN | Digikey PN | Unit Price | Extended Price | Unit Price | Extended Price

I/O Master v1.0 - Populated Parts | Qty 1 | Qty 100

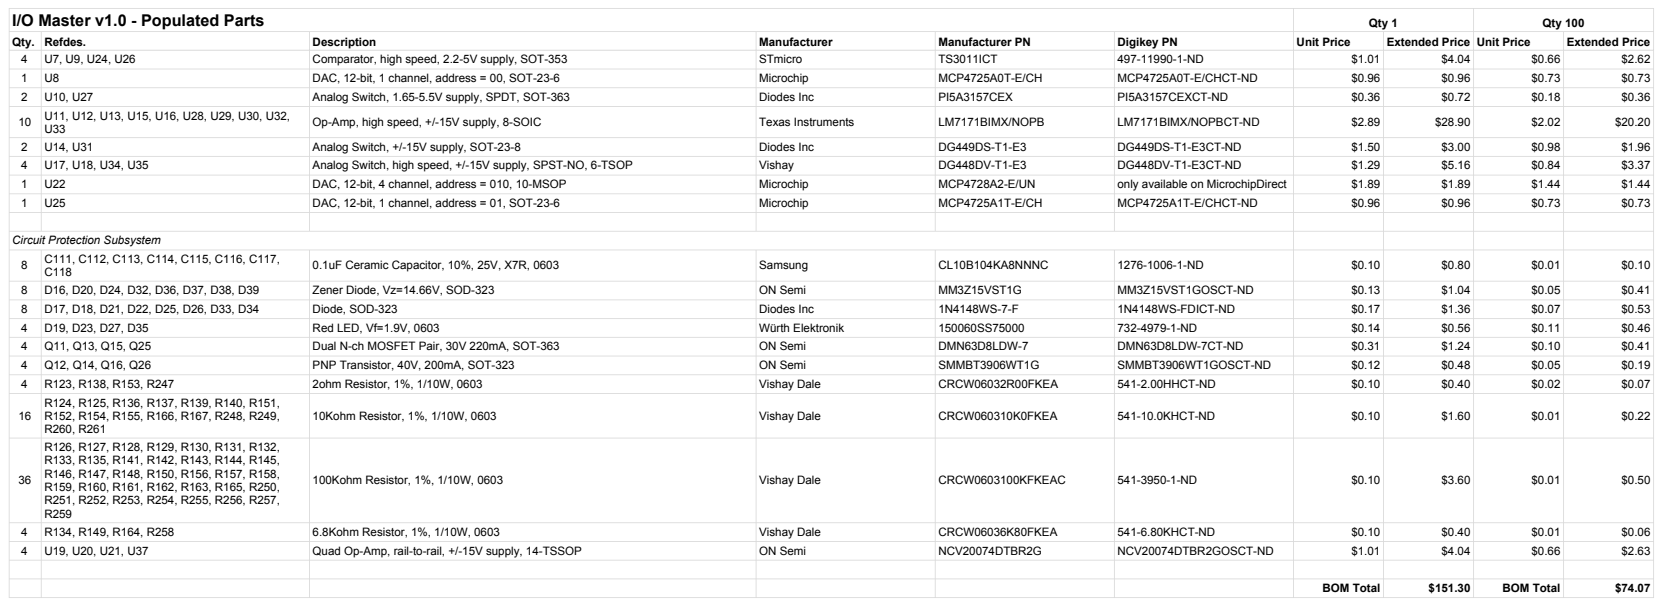
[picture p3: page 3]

Qty. | Refdes. | Description | Manufacturer | Manufacturer PN | Digikey PN | Unit Price | Extended Price | Unit Price | Extended Price

## I/O Master v1.0 - Depopulated Parts

Qty. | Refdes. | Description
2 | | Transistor, SOT-323
4 | R1, R2, R3, R4 | Resistor, 0603

+/-15V Regulator
3 | C99, C109, C110 | Ceramic Capacitor, 1210
2 | C102, C103 | Ceramic Capacitor, 0603

3.3-15V Adjustable Regulator
2 | C40, C45 | Ceramic Capacitor, 1210

Microcontroller Subsystem
1 | R9 | Resistor, 0603

Level Shifter Subsystem
6 | C55, C56, C59, C81, C82, C85 | Ceramic Capacitor, 0603
6 | R77, R78, R91, R195, R196, R209 | Resistor, 0603
4 | R110, R111, R228, R229 | Jumper, 0603

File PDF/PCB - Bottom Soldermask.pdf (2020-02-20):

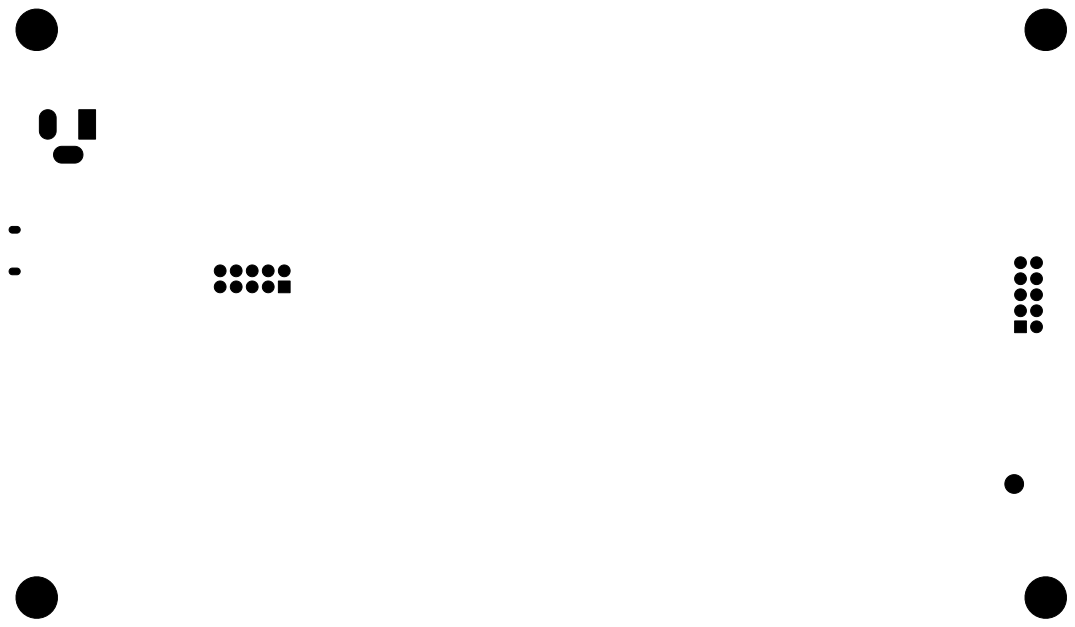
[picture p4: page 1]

DT18 - I/O MASTER
File: io-master.kicad_pcb Sheet: THE UNIVERSITY OF AKRON

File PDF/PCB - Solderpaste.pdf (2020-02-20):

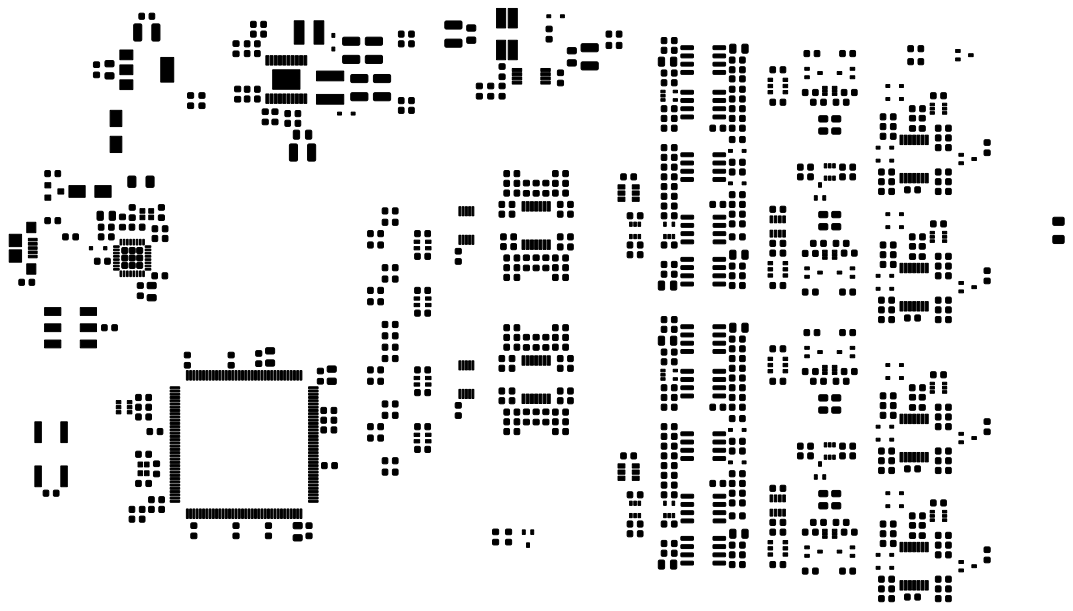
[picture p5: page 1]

DT18 - I/O MASTER
File: io-master.kicad_pcb Sheet: THE UNIVERSITY OF AKRON

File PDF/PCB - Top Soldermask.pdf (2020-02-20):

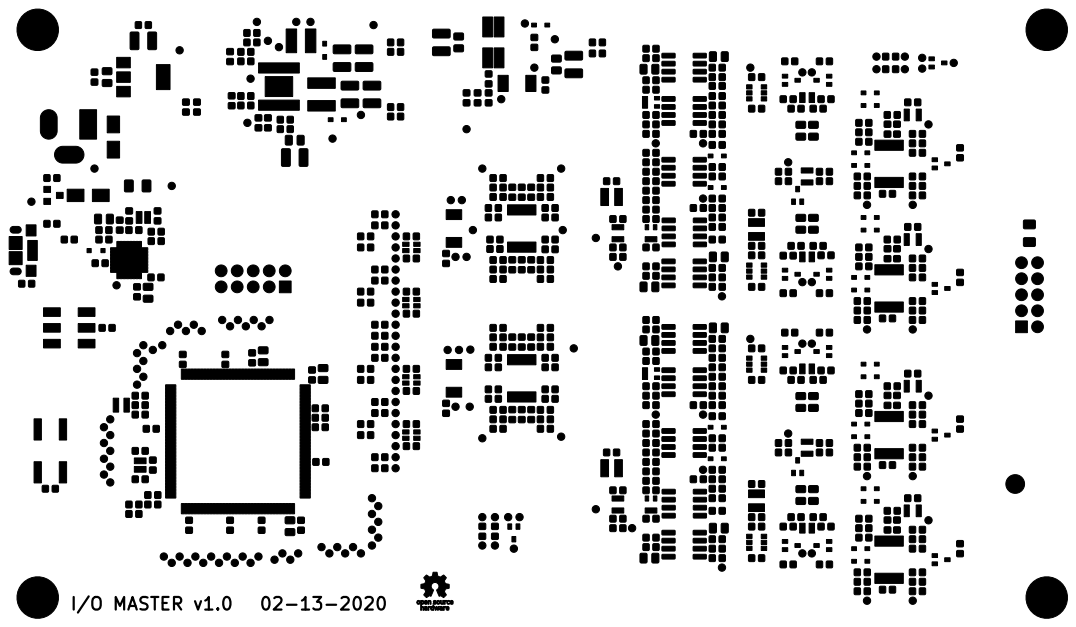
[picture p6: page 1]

DT18 - I/O MASTER
File: io-master.kicad_pcb Sheet: THE UNIVERSITY OF AKRON

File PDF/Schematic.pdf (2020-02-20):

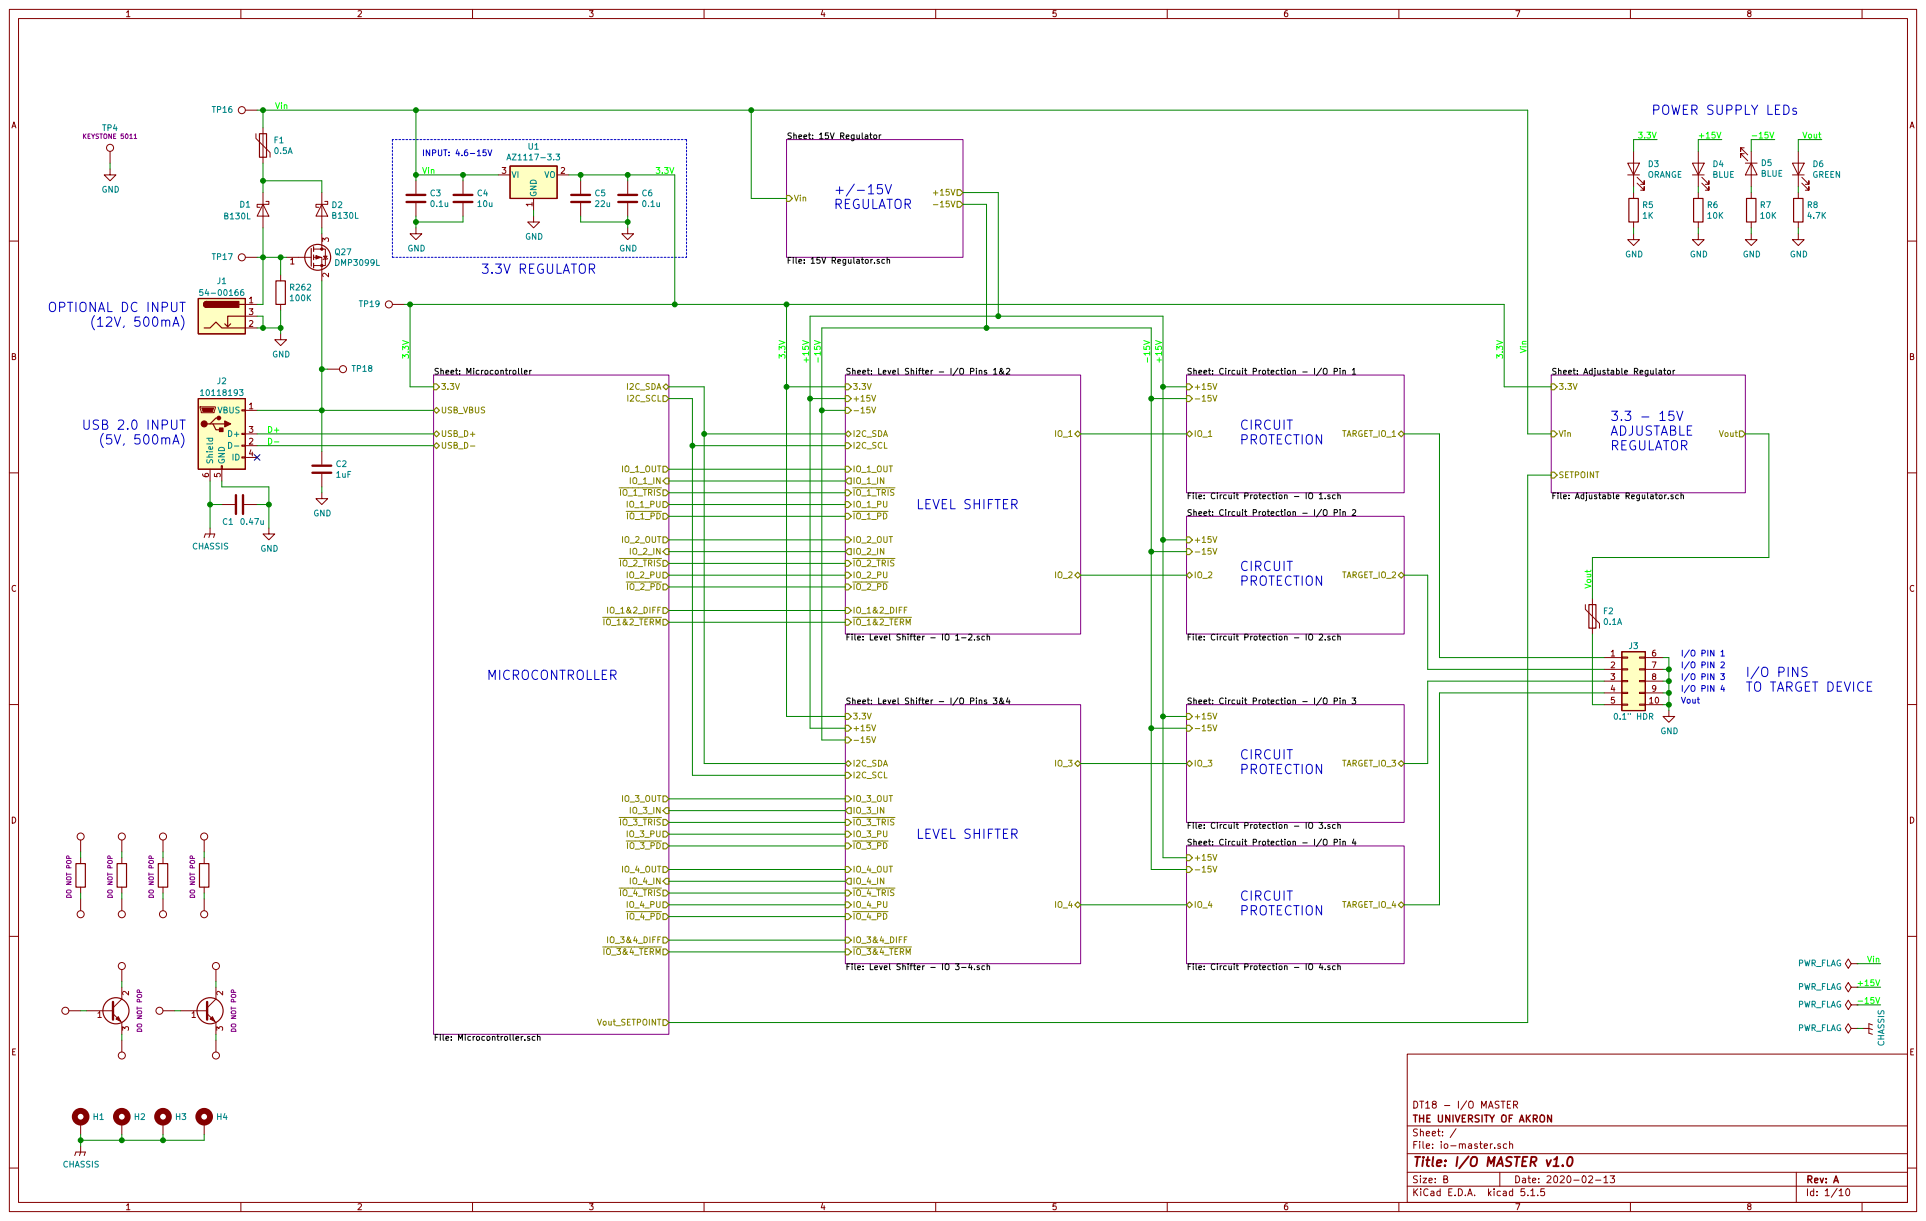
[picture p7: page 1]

Sheet: Level Shifter - I/O Pins 1&2 File: Level Shifter - IO 1-2.sch

2 3DO NOT POP DO NOT POP R262

Sheet: Circuit Protection - I/O Pin 2 File: Circuit Protection - IO 2.sch +15V

5 | | 10

Sheet: Circuit Protection - I/O Pin 4 File: Circuit Protection - IO 4.sch +15V

DT18 - I/O MASTER
File: io-master.sch Sheet: / THE UNIVERSITY OF AKRON

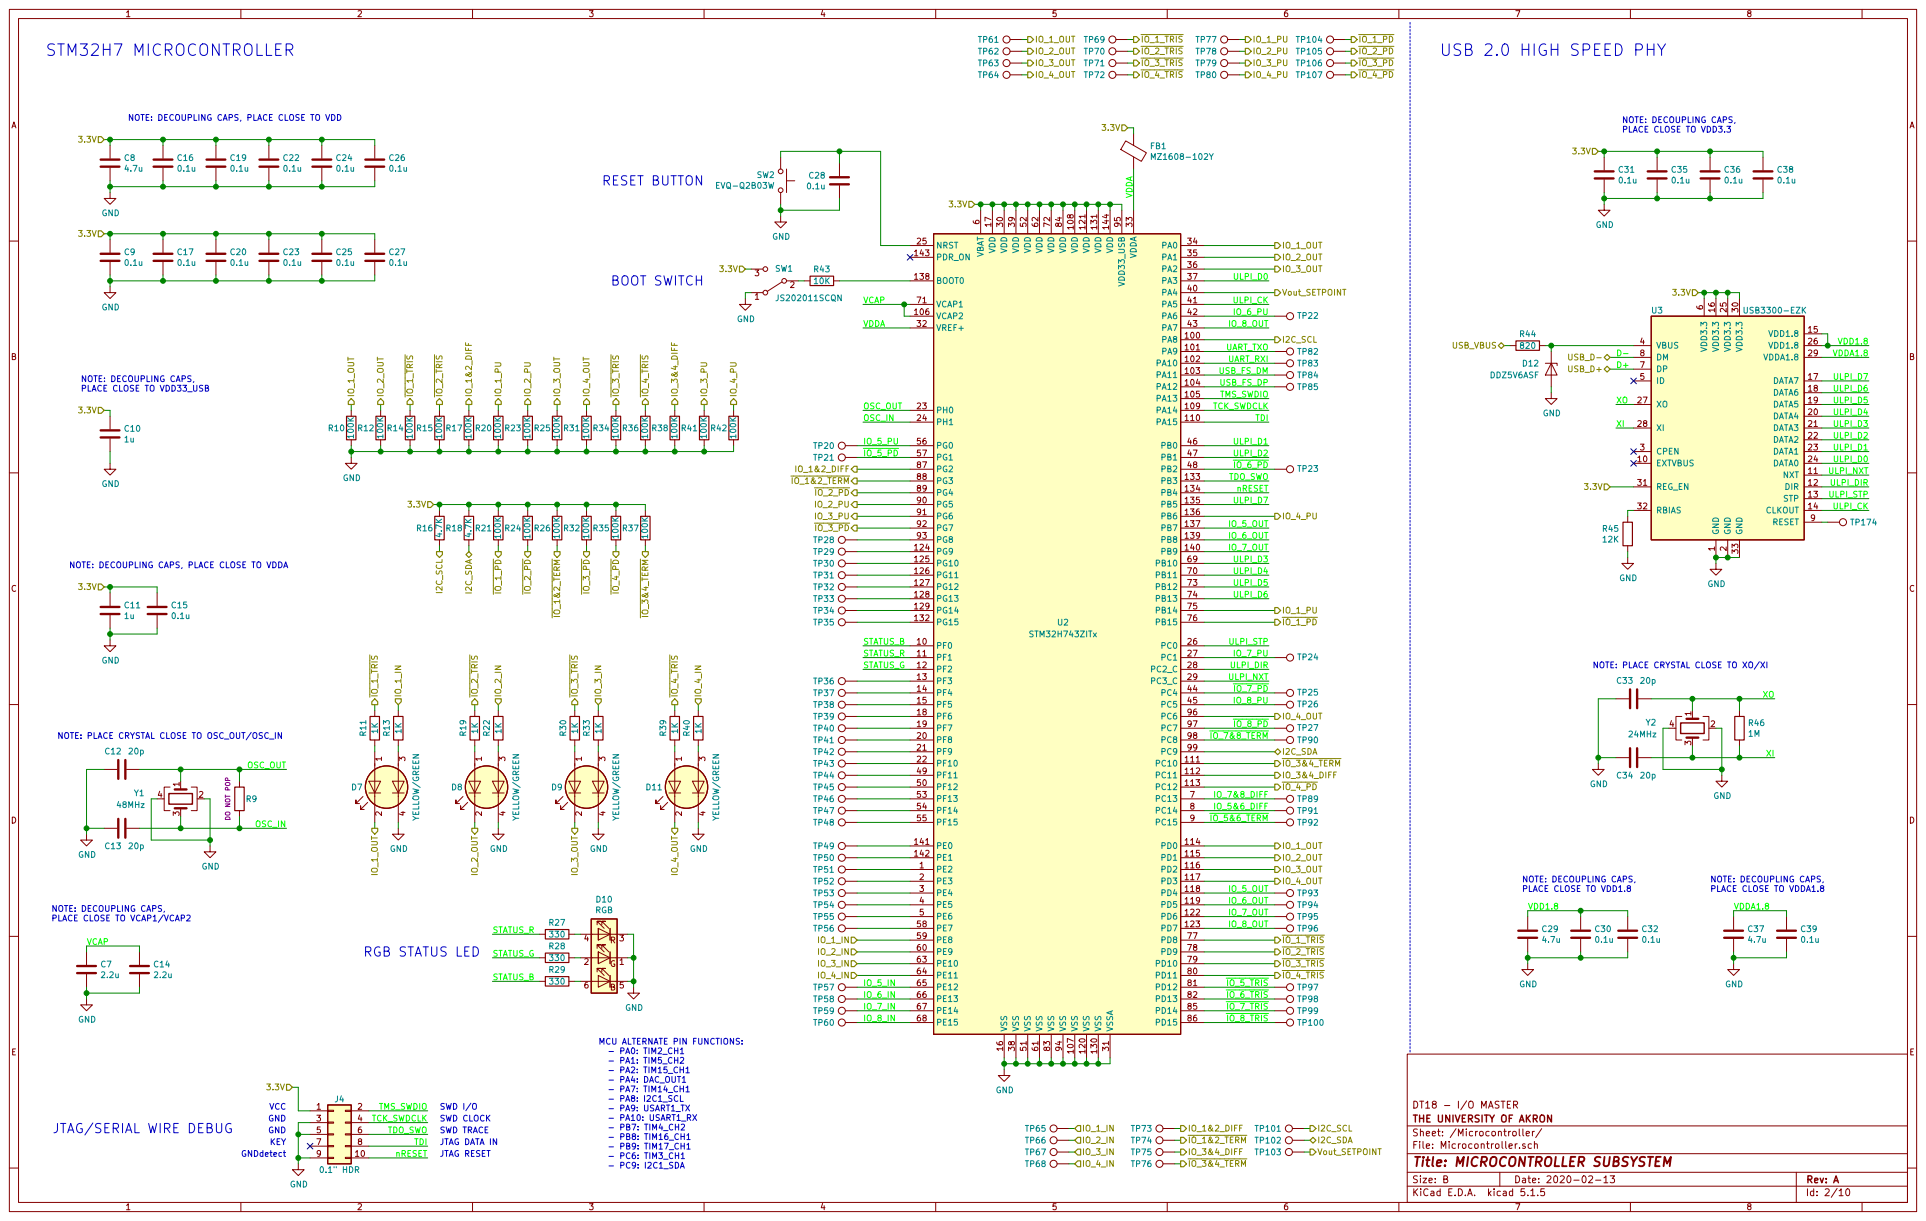
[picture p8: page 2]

USB 2.0 HIGH SPEED PHY

NOTE: DECOUPLING CAPS, PLACE CLOSE TO VDD

NOTE: DECOUPLING CAPS, PLACE CLOSE TO VDD3.3

6 VCAP1 71 VCAP2 106 VDD 108 VDD 121 VDD 131 VDD 144 VDD 17 VDD 30 VDD 39 VDD 52 VDD 62 VDD 72 VDD 84 VDD33_USB 95 VDDA 33 VREF+ 32 VSS 107 VSS 120 VSS 130 VSS 16 VSS 38 VSS 51 VSS 61 VSS 83 VSS 94 VSSA 31 U2 STM32H743ZITx GND

NOTE: DECOUPLING CAPS, PLACE CLOSE TO VDDA NOTE: DECOUPLING CAPS, PLACE CLOSE TO VCAP1/VCAP2

NOTE: PLACE CRYSTAL CLOSE TO XO/XI NOTE: DECOUPLING CAPS, PLACE CLOSE TO VDDA1.8
C33 20p GND

NOTE: DECOUPLING CAPS, PLACE CLOSE TO VDD1.8

SWD I/O JTAG/SERIAL WIRE DEBUG

JTAG RESET VCC GNDdetect GND GND

DT18 - I/O MASTER
File: Microcontroller.sch Sheet: /Microcontroller/ THE UNIVERSITY OF AKRON

Id: 2/10 Title: MICROCONTROLLER SUBSYSTEM

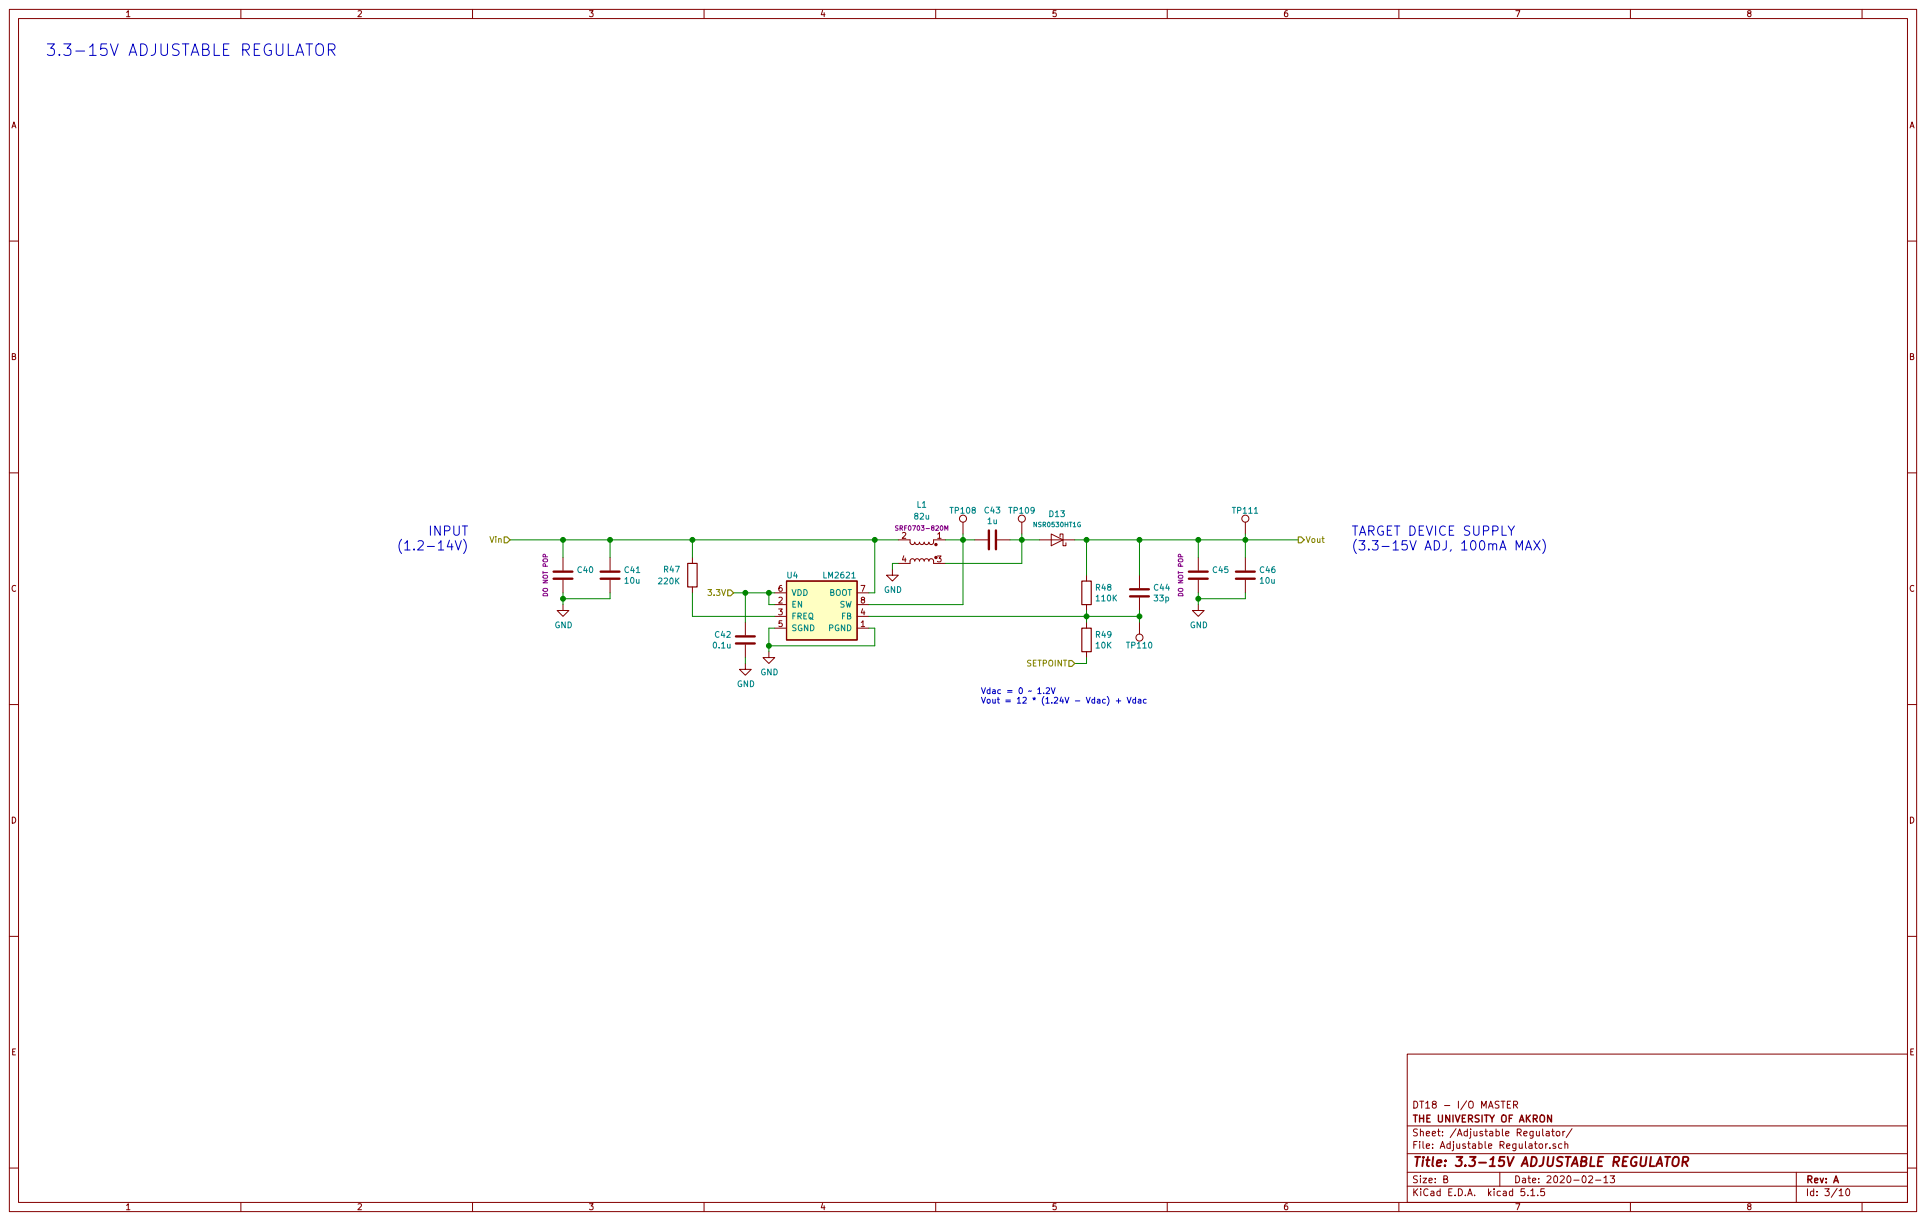
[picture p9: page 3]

DT18 - I/O MASTER
Sheet: /Adjustable Regulator/ THE UNIVERSITY OF AKRON

File: Adjustable Regulator.sch
Id: 3/10 Title: 3.3-15V ADJUSTABLE REGULATOR

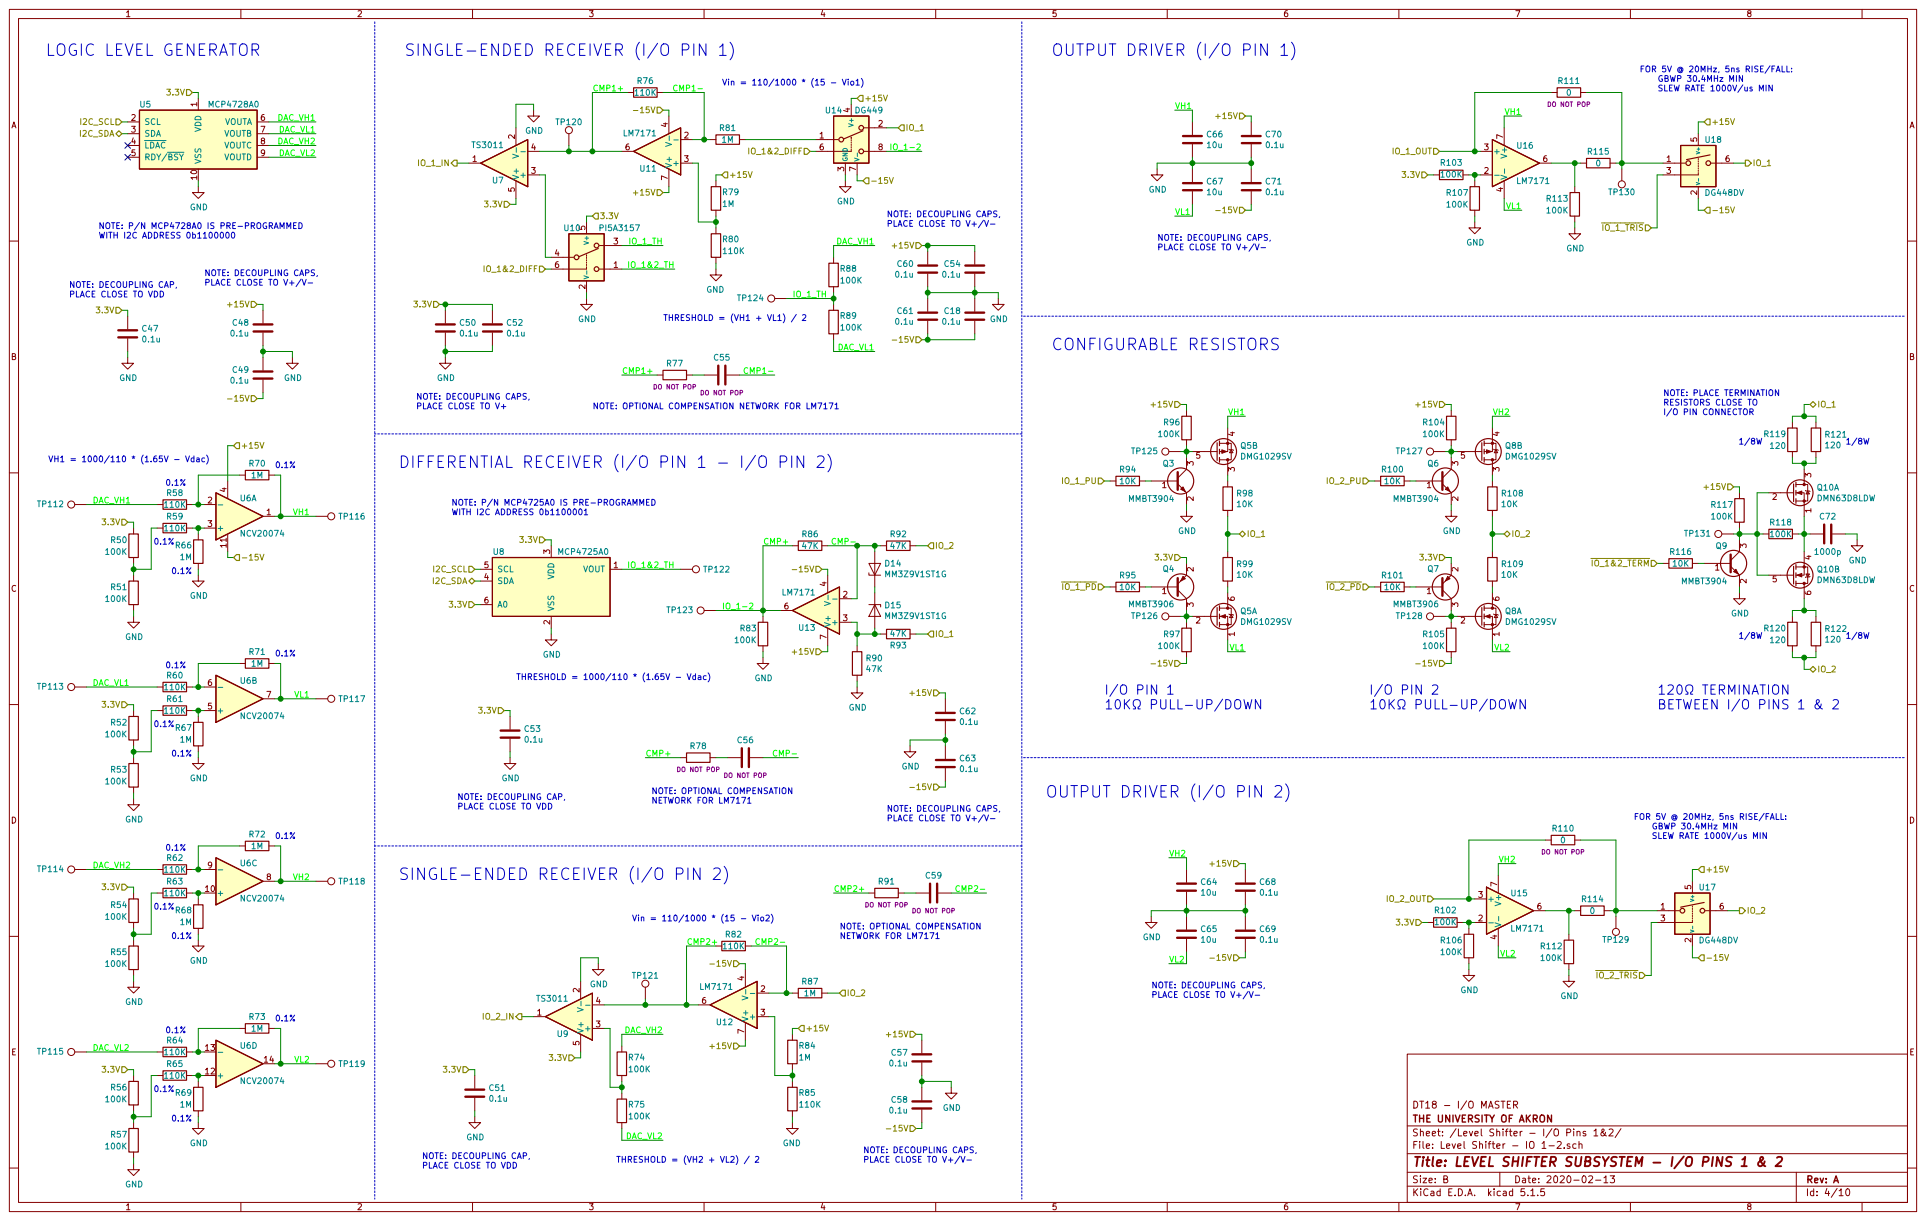
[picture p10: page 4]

SINGLE-ENDED RECEIVER (I/O PIN 1)

FOR 5V @ 20MHz, 5ns RISE/FALL:
GBWP 30.4MHz MIN
SLEW RATE 1000V/us MIN

NOTE: DECOUPLING CAPS, PLACE CLOSE TO V+/V- NOTE: DECOUPLING CAPS, PLACE CLOSE TO V+

NOTE: DECOUPLING CAPS, PLACE CLOSE TO V+/V- DIFFERENTIAL RECEIVER (I/O PIN 1 - I/O PIN 2)

NOTE: OPTIONAL COMPENSATION NETWORK FOR LM7171 NOTE: OPTIONAL COMPENSATION

NOTE: P/N MCP4725A0 IS PRE-PROGRAMMED WITH I2C ADDRESS 0b1100001 NOTE: DECOUPLING CAP, PLACE CLOSE TO VDD

NOTE: DECOUPLING CAPS, PLACE CLOSE TO V+/V-

SINGLE-ENDED RECEIVER (I/O PIN 2)

DT18 - I/O MASTER
File: Level Shifter - IO 1-2.sch Sheet: /Level Shifter - I/O Pins 1&2/ THE UNIVERSITY OF AKRON

NOTE: DECOUPLING CAP, PLACE CLOSE TO VDD

Id: 4/10 Title: LEVEL SHIFTER SUBSYSTEM - I/O PINS 1 & 2

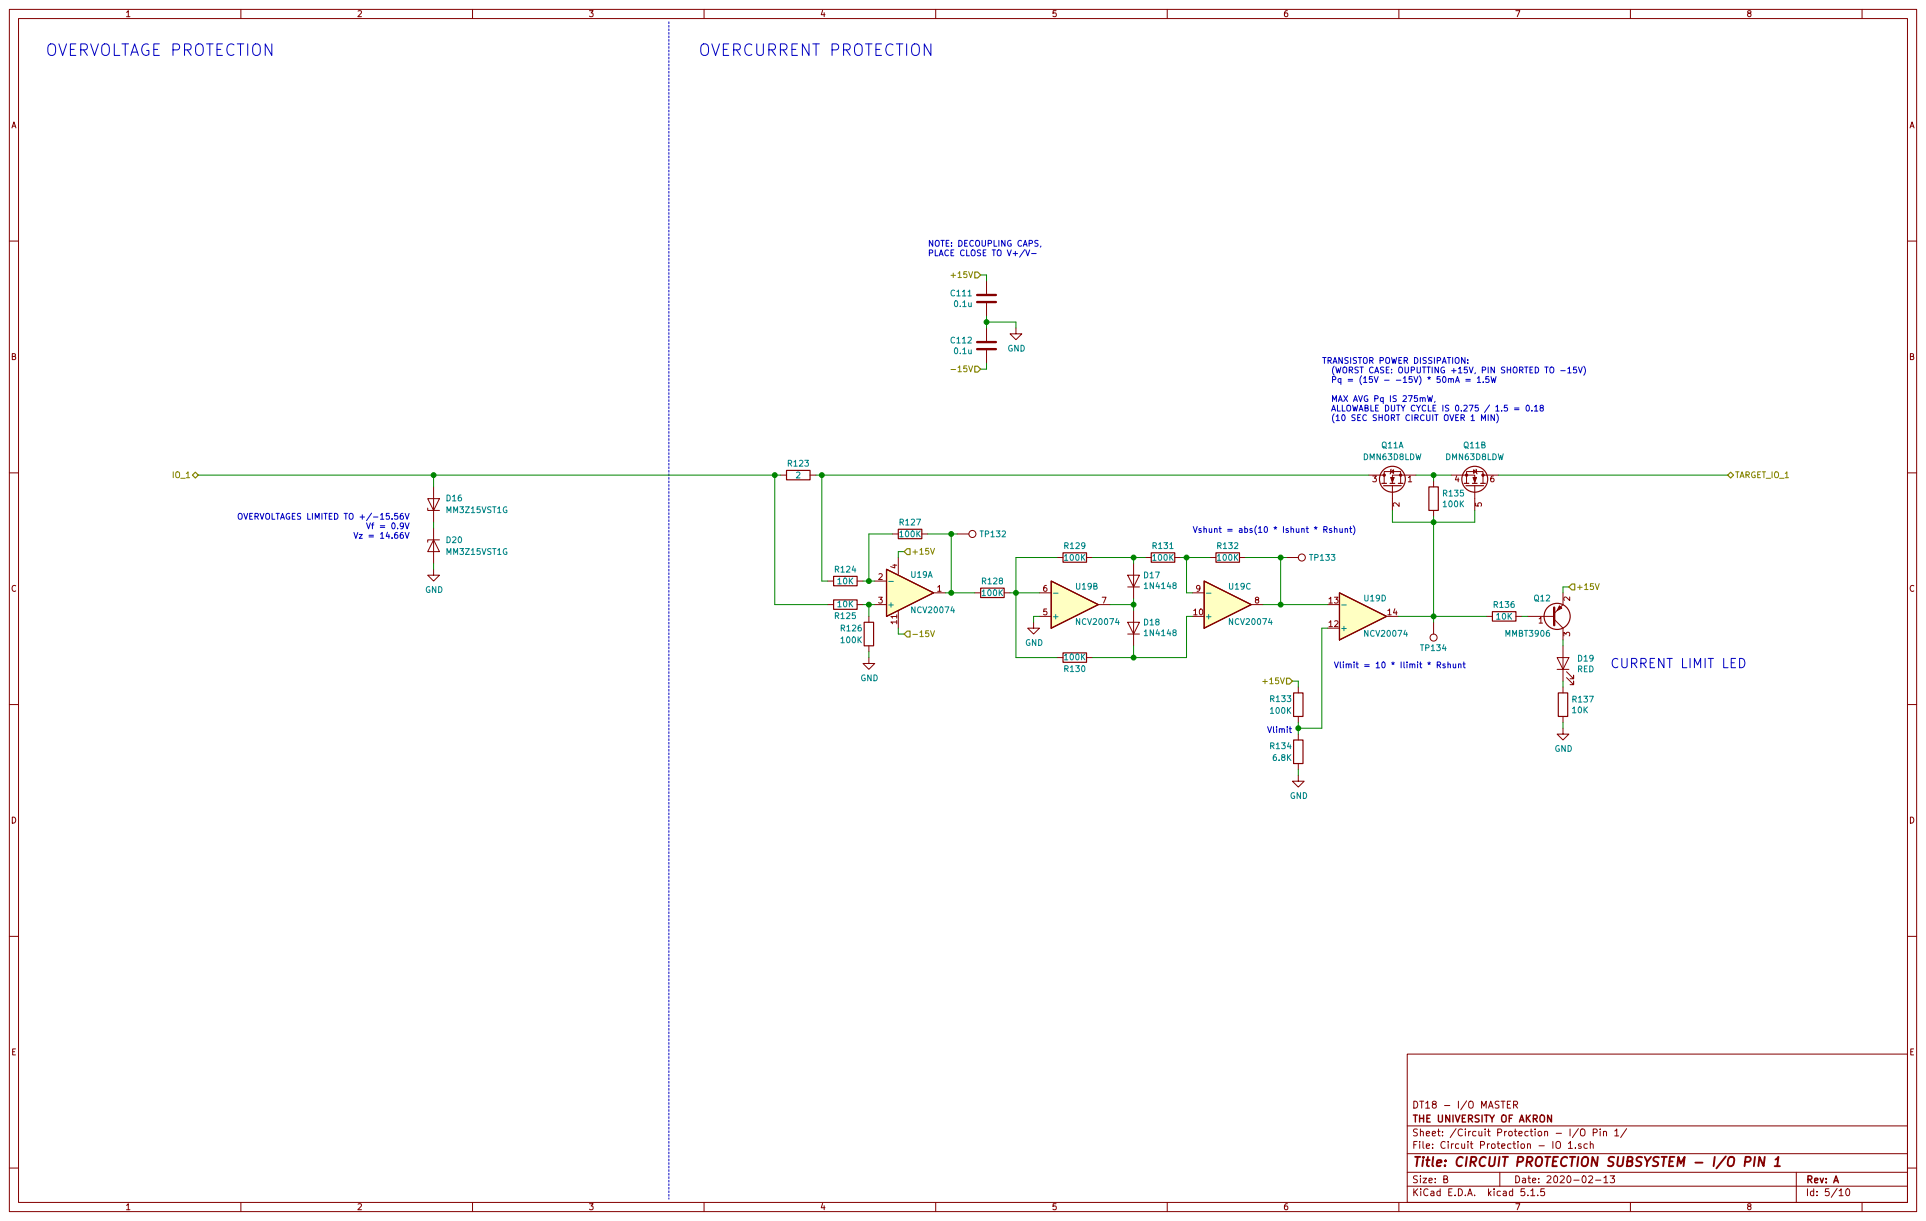
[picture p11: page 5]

NOTE: DECOUPLING CAPS, PLACE CLOSE TO V+/V- OVERVOLTAGE PROTECTION

TRANSISTOR POWER DISSIPATION:
(WORST CASE: OUPUTTING +15V, PIN SHORTED TO -15V)

MAX AVG Pq IS 275mW,
ALLOWABLE DUTY CYCLE IS 0.275 / 1.5 = 0.18

DT18 - I/O MASTER
File: Circuit Protection - IO 1.sch Sheet: /Circuit Protection - I/O Pin 1/ THE UNIVERSITY OF AKRON

Id: 5/10 Title: CIRCUIT PROTECTION SUBSYSTEM - I/O PIN 1

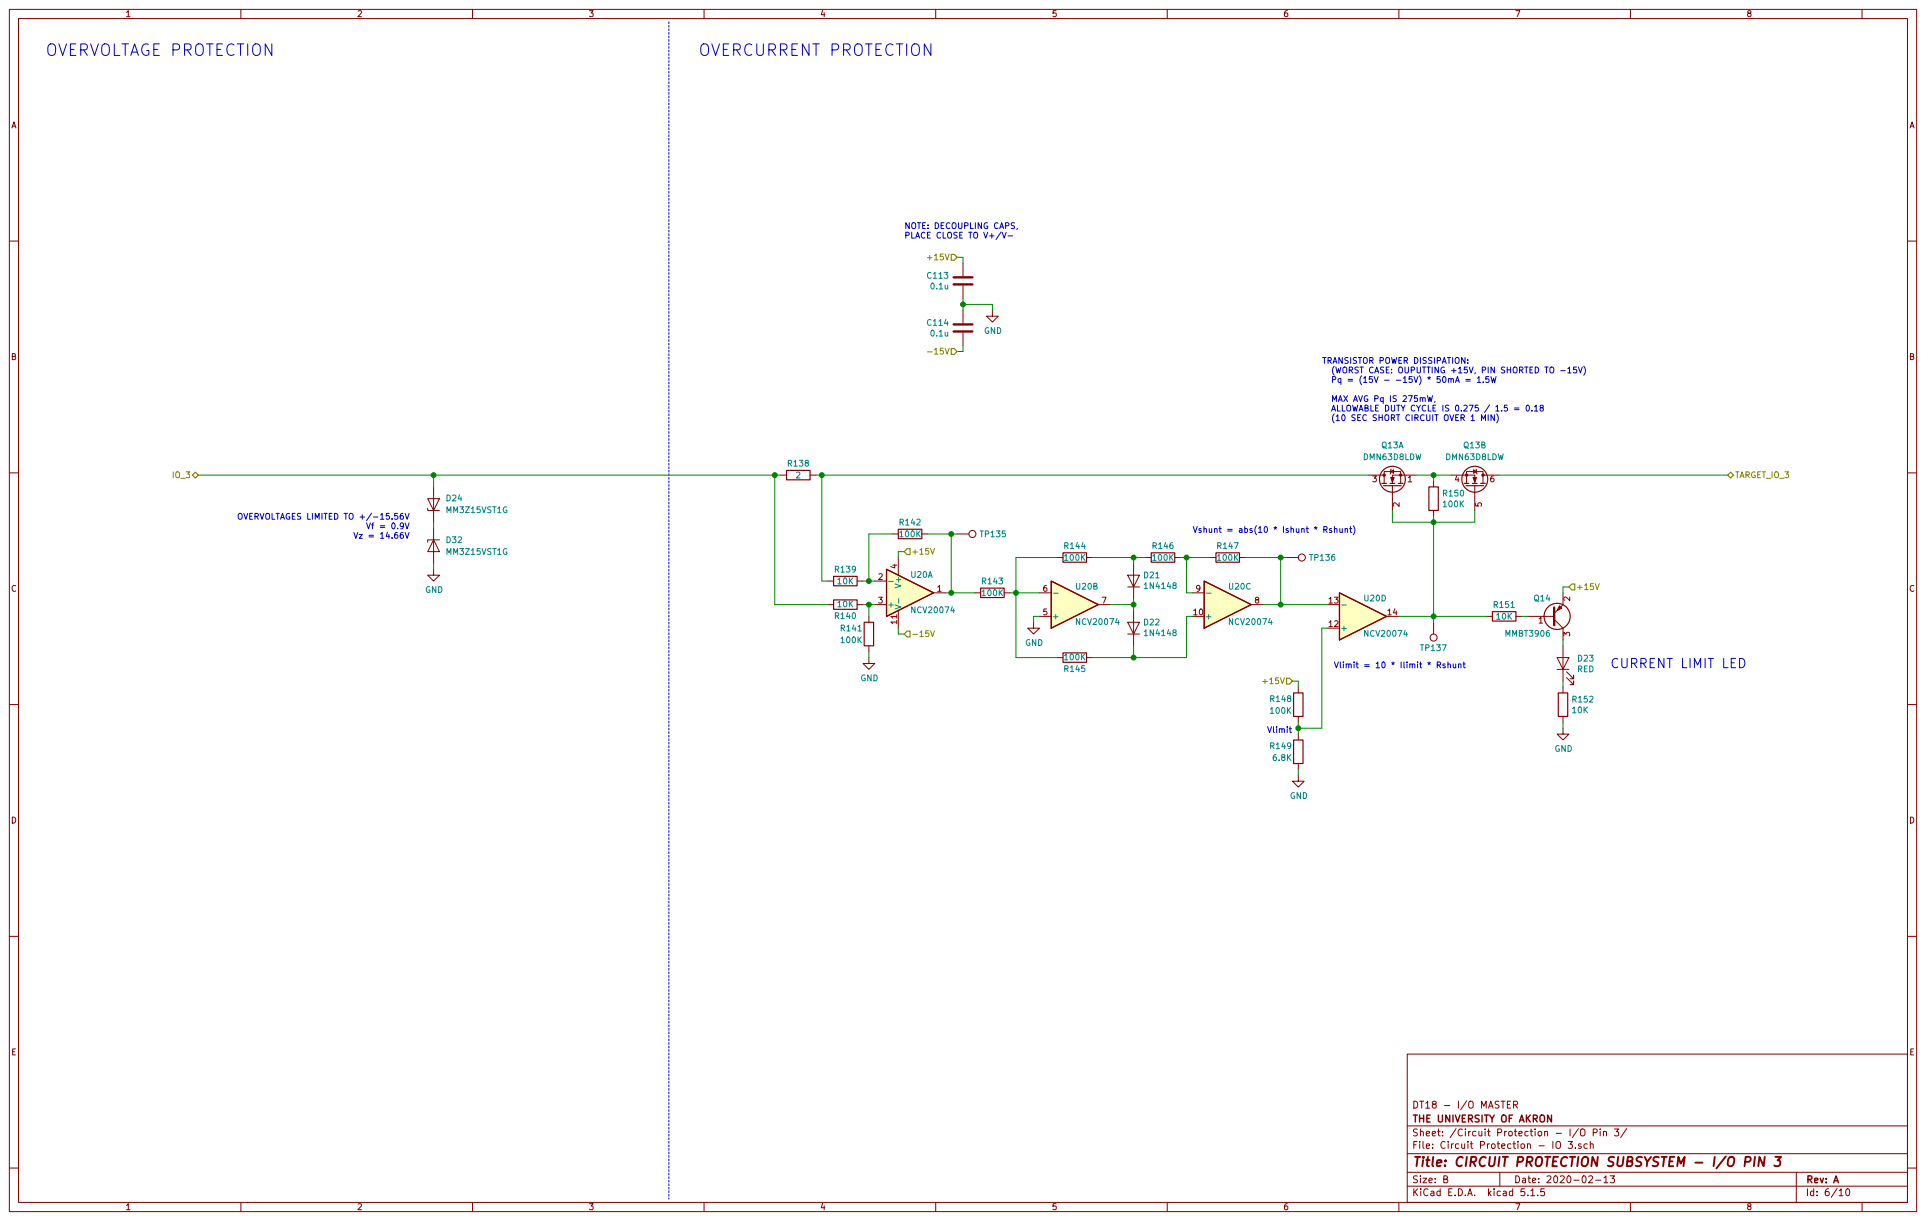
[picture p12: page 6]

TRANSISTOR POWER DISSIPATION:
(WORST CASE: OUPUTTING +15V, PIN SHORTED TO -15V)

MAX AVG Pq IS 275mW,
ALLOWABLE DUTY CYCLE IS 0.275 / 1.5 = 0.18
(10 SEC SHORT CIRCUIT OVER 1 MIN)

DT18 - I/O MASTER
File: Circuit Protection - IO 3.sch Sheet: /Circuit Protection - I/O Pin 3/ THE UNIVERSITY OF AKRON

Id: 6/10 Title: CIRCUIT PROTECTION SUBSYSTEM - I/O PIN 3


TRANSISTOR POWER DISSIPATION:
(WORST CASE: OUPUTTING +15V, PIN SHORTED TO -15V)

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

DT18 - I/O MASTER
File: Circuit Protection - IO 4.sch Sheet: /Circuit Protection - I/O Pin 4/ THE UNIVERSITY OF AKRON

Id: 7/10 Title: CIRCUIT PROTECTION SUBSYSTEM - I/O PIN 4


NOTE: OPTIONAL COMPENSATION NETWORK FOR LM7171 LOGIC LEVEL GENERATOR

SINGLE-ENDED RECEIVER (I/O PIN 3)

OUTPUT DRIVER (I/O PIN 3) NOTE: DECOUPLING CAPS, PLACE CLOSE TO V+/V-

Vin = 110/1000 * (15 - Vio3) NOTE: DECOUPLING CAP, PLACE CLOSE TO VDD

SLEW RATE 1000V/us MIN OUTPUT DRIVER (I/O PIN 4)

DIFFERENTIAL RECEIVER (I/O PIN 3 - I/O PIN 4)

C82 DO NOT POP R196 DO NOT POP GND

FOR 5V @ 20MHz, 5ns RISE/FALL:
GBWP 30.4MHz MIN
SLEW RATE 1000V/us MIN

NOTE: DECOUPLING CAPS, PLACE CLOSE TO V+/V-

DT18 - I/O MASTER
File: Level Shifter - IO 3-4.sch Sheet: /Level Shifter - I/O Pins 3&4/ THE UNIVERSITY OF AKRON

NOTE: DECOUPLING CAP, PLACE CLOSE TO VDD

Id: 8/10 Title: LEVEL SHIFTER SUBSYSTEM - I/O PINS 3 & 4


1 SS 10 EN2 11 COMP2 12 FB2 13 VREF 14 AGND 15 VREG 16 PVIN1 17 PVINSYS 18 PVIN2 19 SW1 2 SW2 20 AGND 21

DT18 - I/O MASTER
Sheet: /15V Regulator/ THE UNIVERSITY OF AKRON


TRANSISTOR POWER DISSIPATION:
(WORST CASE: OUPUTTING +15V, PIN SHORTED TO -15V)

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

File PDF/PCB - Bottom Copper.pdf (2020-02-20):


DT18 - I/O MASTER
File: io-master.kicad_pcb Sheet: THE UNIVERSITY OF AKRON

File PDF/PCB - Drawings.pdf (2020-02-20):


DT18 - I/O MASTER
File: io-master.kicad_pcb Sheet: THE UNIVERSITY OF AKRON

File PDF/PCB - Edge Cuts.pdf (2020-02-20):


DT18 - I/O MASTER
File: io-master.kicad_pcb Sheet: THE UNIVERSITY OF AKRON

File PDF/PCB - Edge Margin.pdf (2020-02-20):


DT18 - I/O MASTER
File: io-master.kicad_pcb Sheet: THE UNIVERSITY OF AKRON

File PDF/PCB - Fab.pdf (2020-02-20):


DT18 - I/O MASTER
File: io-master.kicad_pcb Sheet: THE UNIVERSITY OF AKRON

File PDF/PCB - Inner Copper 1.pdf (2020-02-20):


DT18 - I/O MASTER
File: io-master.kicad_pcb Sheet: THE UNIVERSITY OF AKRON

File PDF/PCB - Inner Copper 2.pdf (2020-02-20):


DT18 - I/O MASTER
File: io-master.kicad_pcb Sheet: THE UNIVERSITY OF AKRON

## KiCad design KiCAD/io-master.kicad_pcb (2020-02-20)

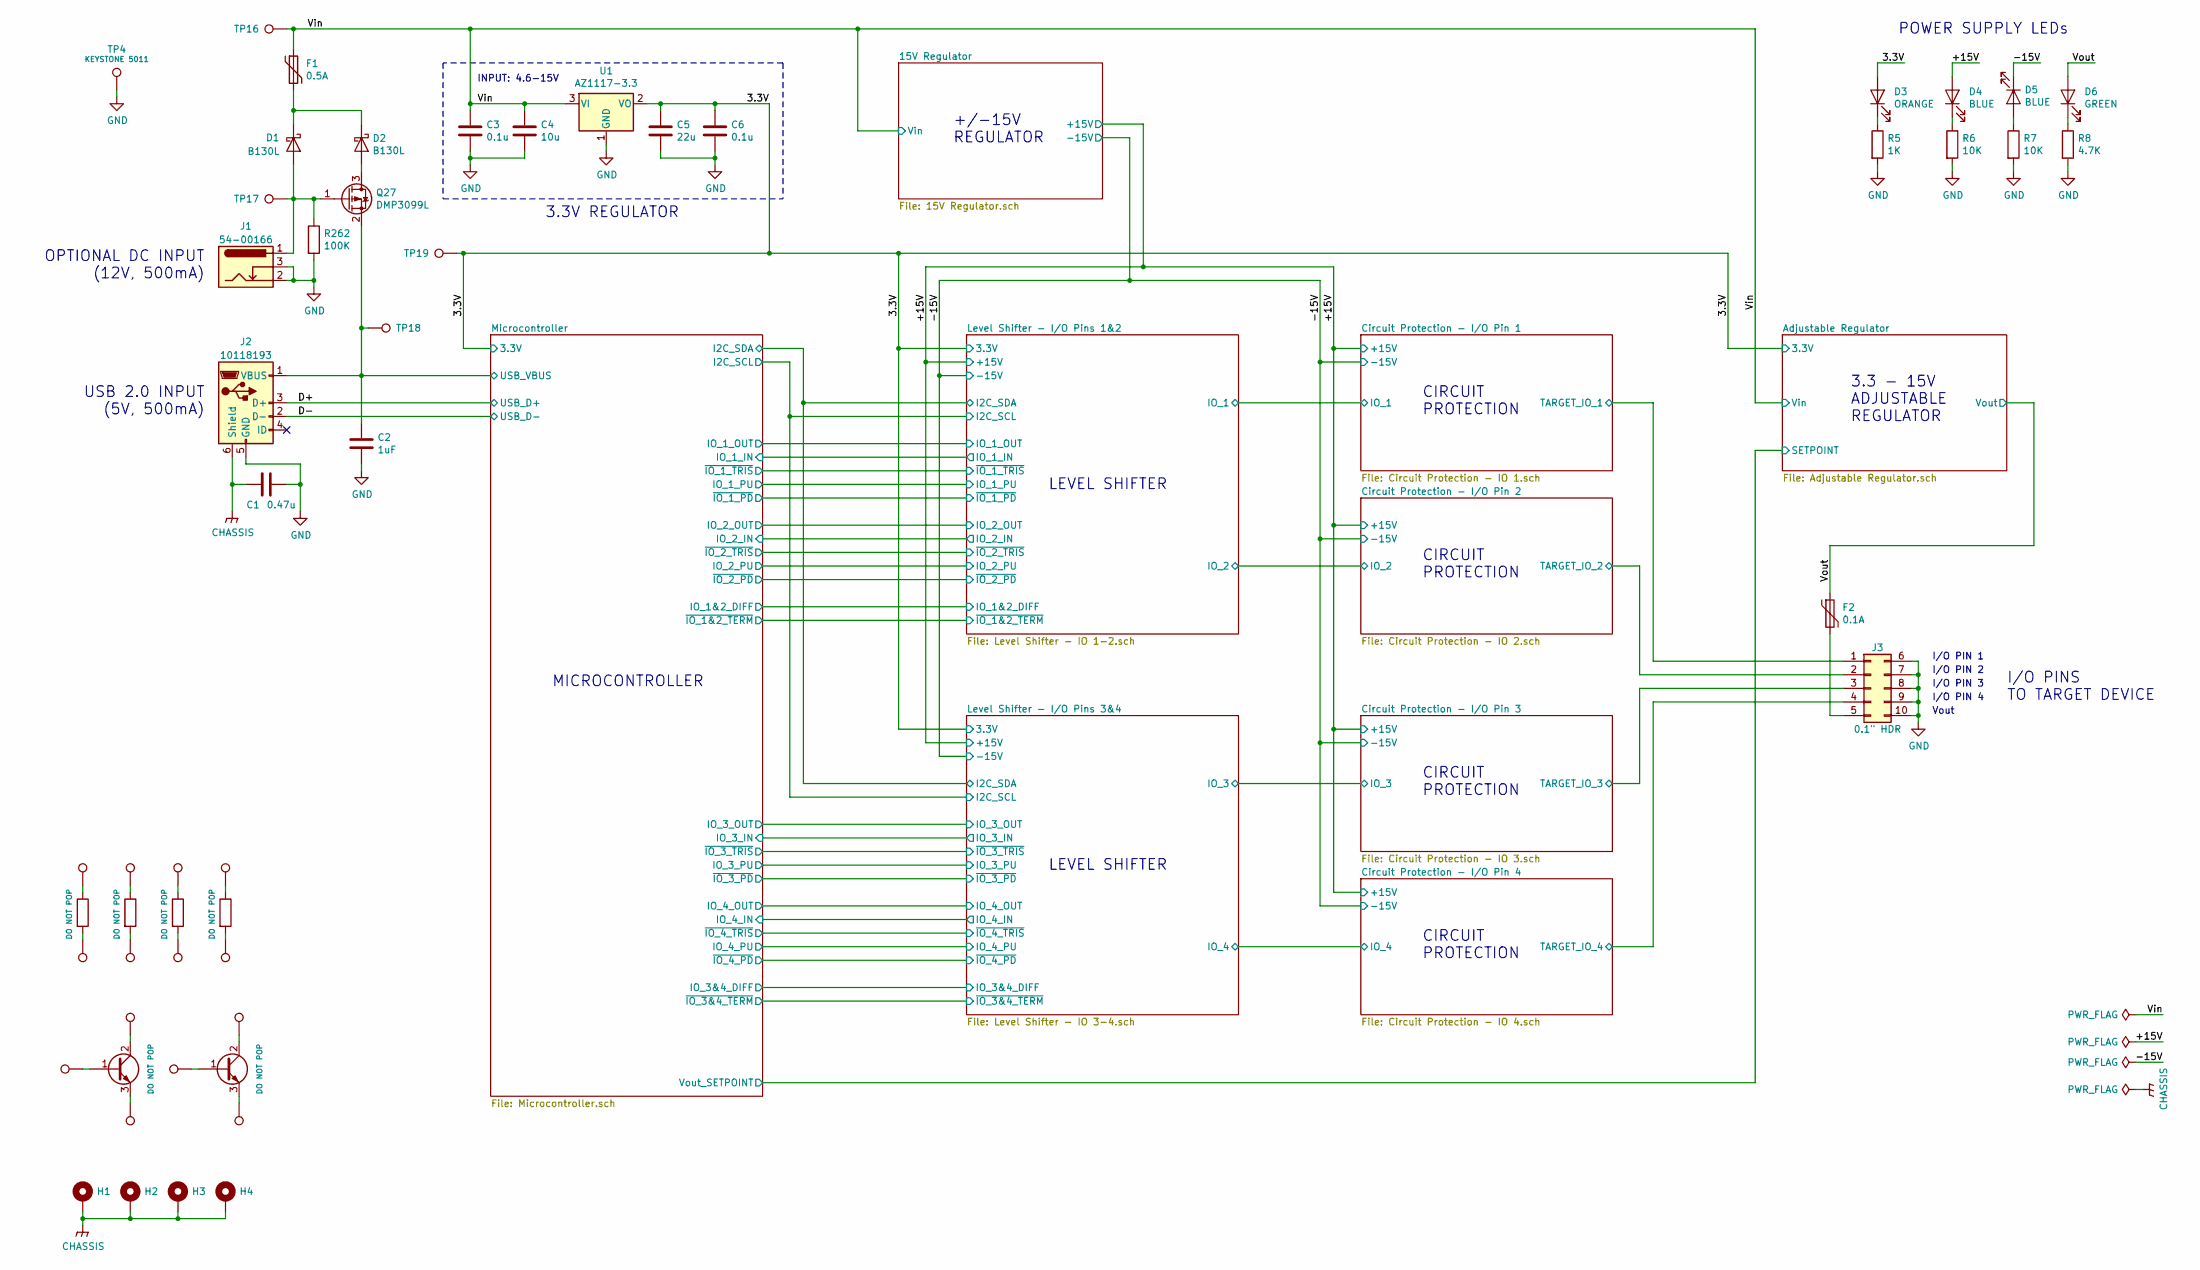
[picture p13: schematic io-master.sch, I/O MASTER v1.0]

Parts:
C1: 0.47u; C_0603_1608Metric
C2: 1uF; C_0603_1608Metric
C3, C6: 0.1u; C_0603_1608Metric
C4: 10u; C_0805_2012Metric
C5: 22u; C_1210_3225Metric
D1, D2: B130L; D_SMA
D3: ORANGE; LED_0603_1608Metric
D4, D5: BLUE; LED_0603_1608Metric
D6: GREEN; LED_0603_1608Metric
F1: 0.5A; Fuse_1206_3216Metric
F2: 0.1A; Fuse_1206_3216Metric
H1, H2, H3, H4: M3; MountingHole_3.2mm_M3_Pad
J1: 54-00166; BarrelJack_Tensility_54-00166_Horizontal
J2: 10118193; USB_Micro-B_Amphenol_10118193-0001LF_Horizontal
J3: 0.1\" HDR; PinSocket_2x05_P2.54mm_Vertical_AltNumbering
Q1, Q2: Q_NPN_BCE; SOT-323_SC-70
Q27: DMP3099L; SOT-23
R1, R2, R3, R4: R; R_0603_1608Metric
R5: 1K; R_0603_1608Metric
R6, R7: 10K; R_0603_1608Metric
R8: 4.7K; R_0603_1608Metric
R262: 100K; R_0603_1608Metric
TP1, TP2, TP3, TP5, TP6, TP7, TP8, TP9, TP10, TP11, TP12, TP13, TP14, TP15: TestPoint; TestPoint_Pad_D1.0mm
TP4: GND; TestPoint_Keystone_5010-5014_Multipurpose
TP16: VIN; TestPoint_Pad_D1.0mm
TP17: DCIN; TestPoint_Pad_D1.0mm
TP18: VBUS; TestPoint_Pad_D1.0mm
TP19: 3.3V; TestPoint_Pad_D1.0mm
U1: AZ1117-3.3; SOT-223-3_TabPin2

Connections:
/3.3V: C5.1, C6.1, D3.2 (A), TP19.1, U1.2 (VO); also elsewhere on the board
/+15V: D4.2 (A); also elsewhere on the board
/-15V: D5.1 (K); also elsewhere on the board
/Circuit Protection - I/O Pin 1/TARGET_IO_1: J3.1; also elsewhere on the board
/Circuit Protection - I/O Pin 2/TARGET_IO_2: J3.2; also elsewhere on the board
/Circuit Protection - I/O Pin 3/TARGET_IO_3: J3.3; also elsewhere on the board
/Circuit Protection - I/O Pin 4/TARGET_IO_4: J3.4; also elsewhere on the board
/D+: J2.3 (D+); also elsewhere on the board
/D-: J2.2 (D-); also elsewhere on the board
/Microcontroller/USB_VBUS: C2.1, J2.1 (VBUS), Q27.2 (S), TP18.1; also elsewhere on the board
/Vin: C3.1, C4.1, F1.1, TP16.1, U1.3 (VI); also elsewhere on the board
/Vout: D6.2 (A), F2.1; also elsewhere on the board
CHASSIS: C1.2, H1.1, H2.1, H3.1, H4.1, J2.6 (Shield)
GND: C1.1, C2.2, C3.2, C4.2, C5.2, C6.2, J1.2, J1.3, J2.5 (GND), J3.6, J3.7, J3.8, J3.9, J3.10, R5.2, R6.2, R7.2, R8.2, R262.2, TP4.1, U1.1 (GND); also elsewhere on the board
unnamed: D1.1 (K), D2.1 (K), F1.2
unnamed: D1.2 (A), J1.1, Q27.1 (G), R262.1, TP17.1
unnamed: D2.2 (A), Q27.3 (D)
unnamed: D3.1 (K), R5.1
unnamed: D4.1 (K), R6.1
unnamed: D5.2 (A), R7.1
unnamed: D6.1 (K), R8.1
unnamed: F2.2, J3.5
unnamed: Q1.1 (B), TP3.1
unnamed: Q1.2 (C), TP7.1
unnamed: Q1.3 (E), TP8.1
unnamed: Q2.1 (B), TP11.1
unnamed: Q2.2 (C), TP14.1
unnamed: Q2.3 (E), TP15.1
unnamed: R1.1, TP1.1
unnamed: R1.2, TP2.1
unnamed: R2.1, TP5.1
unnamed: R2.2, TP6.1
unnamed: R3.1, TP9.1
unnamed: R3.2, TP10.1
unnamed: R4.1, TP12.1
unnamed: R4.2, TP13.1

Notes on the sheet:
MICROCONTROLLER
CIRCUIT PROTECTION
+/-15V REGULATOR
3.3V REGULATOR
3.3 - 15V ADJUSTABLE REGULATOR
USB 2.0 INPUT (5V, 500mA)
OPTIONAL DC INPUT (12V, 500mA)
Vout
I/O PIN 1
I/O PIN 2
I/O PIN 3
I/O PIN 4
I/O PINS TO TARGET DEVICE
LEVEL SHIFTER
POWER SUPPLY LEDs
INPUT: 4.6-15V

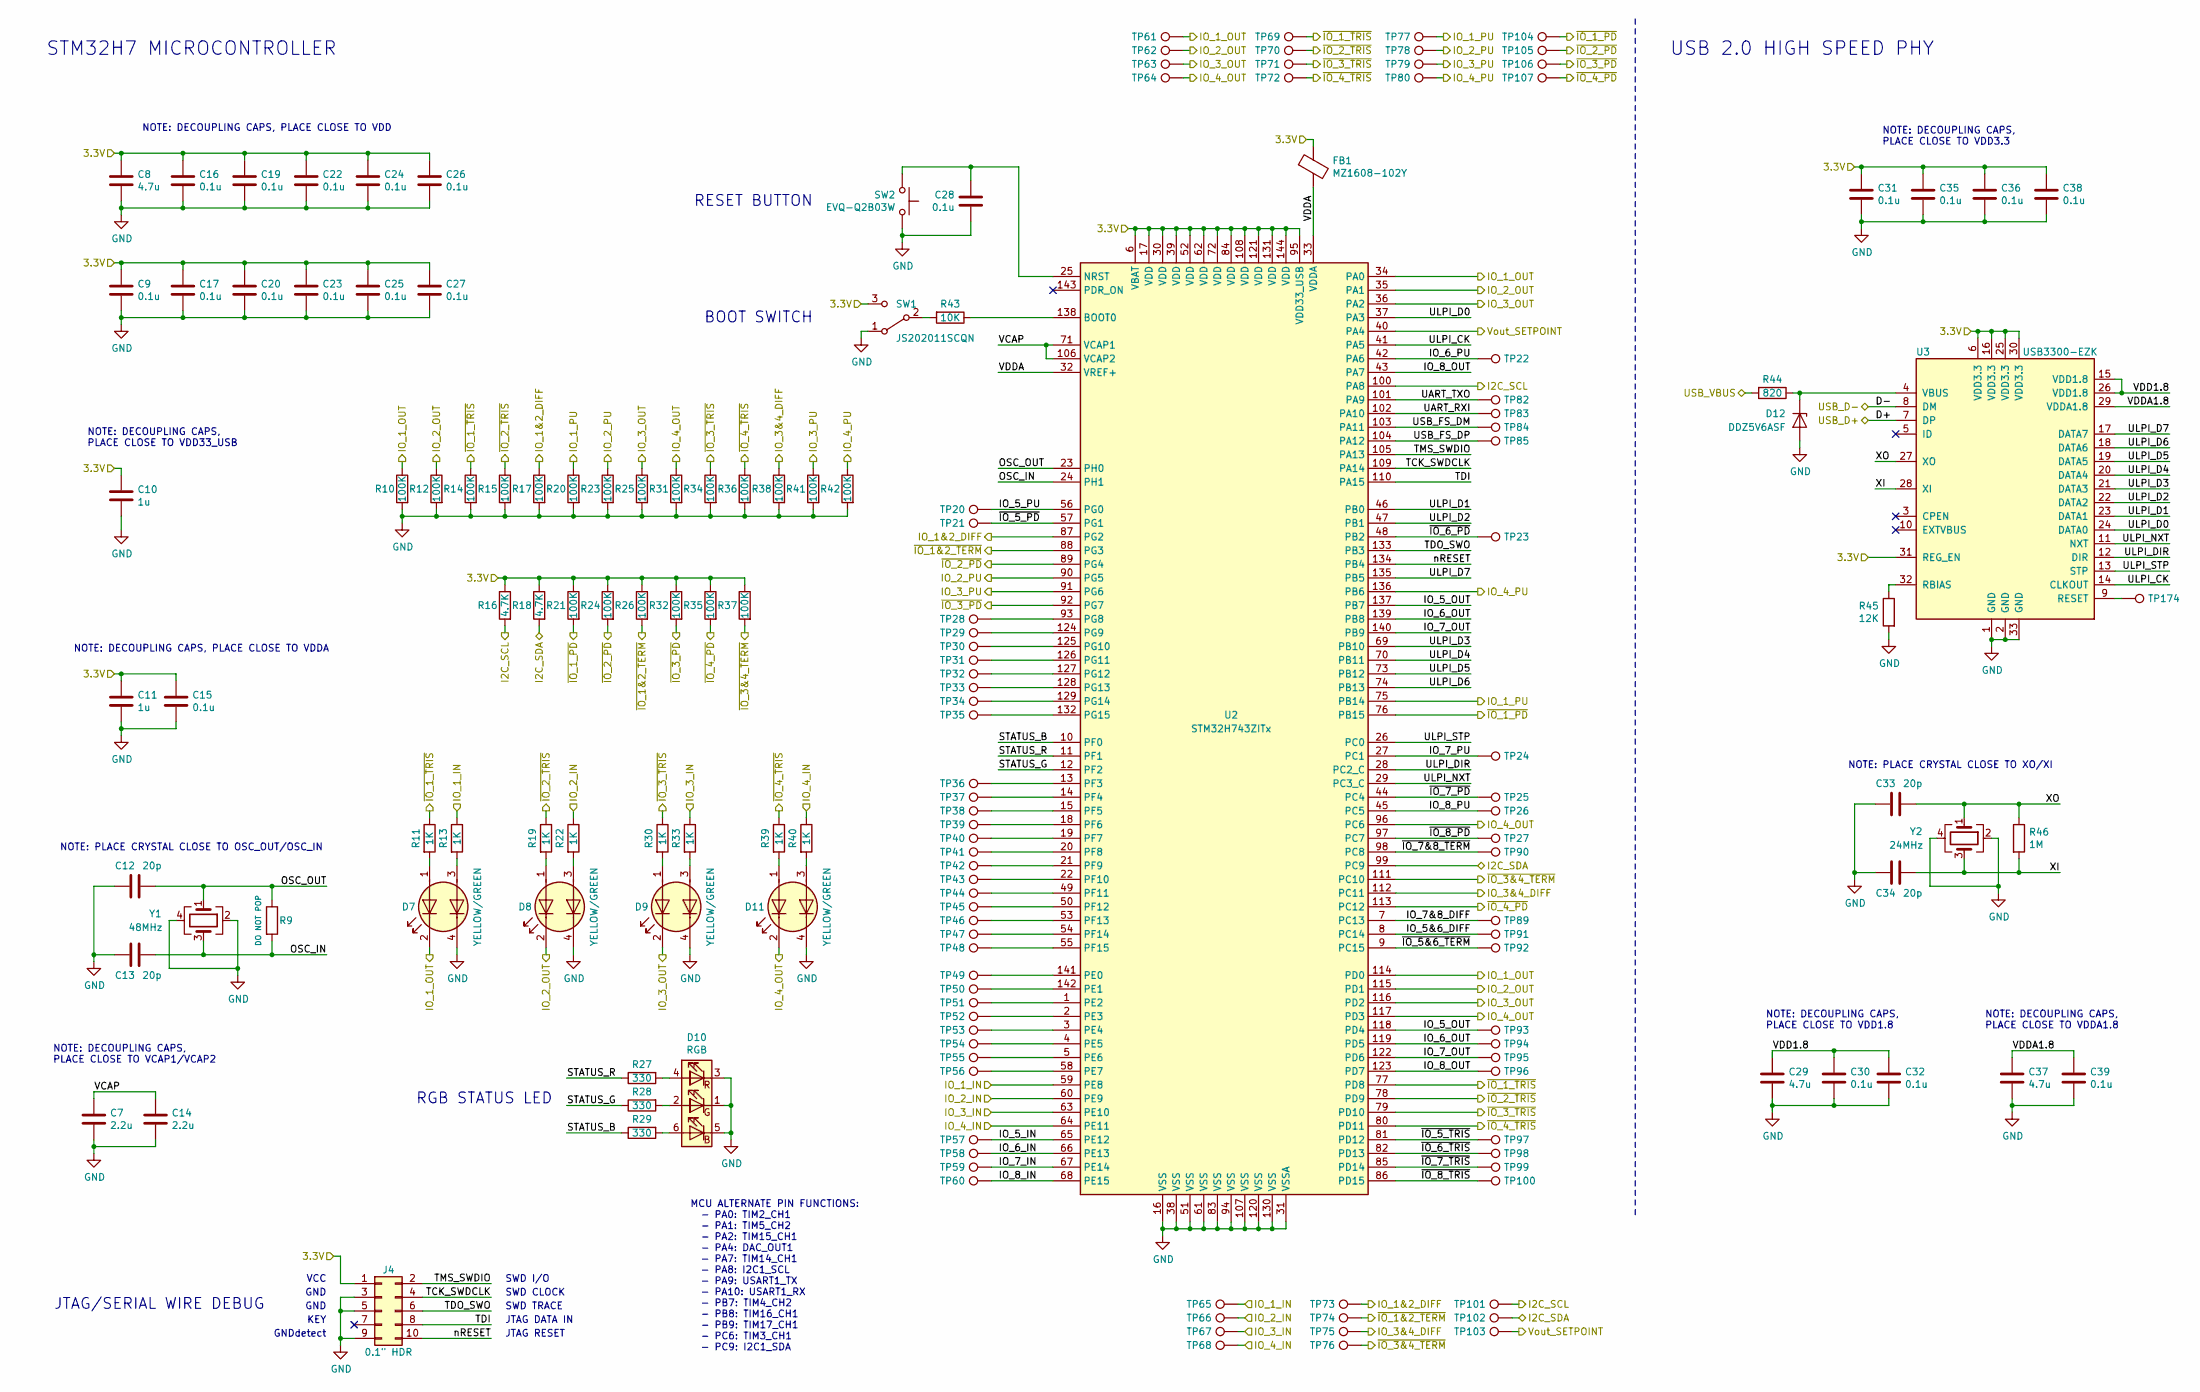
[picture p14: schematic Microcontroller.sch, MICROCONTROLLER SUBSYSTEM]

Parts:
C7, C14: 2.2u; C_0805_2012Metric
C8, C29, C37: 4.7u; C_0805_2012Metric
C9, C15, C16, C17, C19, C20, C22, C23, C24, C25, C26, C27, C28, C30, C31, C32, C35, C36, C38, C39: 0.1u; C_0603_1608Metric
C10, C11: 1u; C_0603_1608Metric
C12, C13, C33, C34: 20p; C_0603_1608Metric
D7, D8, D9, D11: YELLOW/GREEN; LED_Kingbright_APTB1615YSGC
D10: RGB; LED_Everlight_19-337C
D12: DDZ5V6ASF; D_SOD-323F
FB1: MZ1608-102Y; R_0603_1608Metric
J4: 0.1\" HDR; PinSocket_2x05_P2.54mm_Vertical
R9: R; R_0603_1608Metric
R10, R12, R14, R15, R17, R20, R21, R23, R24, R25, R26, R31, R32, R34, R35, R36, R37, R38, R41, R42: 100K; R_0603_1608Metric
R11, R13, R19, R22, R30, R33, R39, R40: 1K; R_0603_1608Metric
R16, R18: 4.7K; R_0603_1608Metric
R27, R28, R29: 330; R_0603_1608Metric
R43: 10K; R_0603_1608Metric
R44: 820; R_0603_1608Metric
R45: 12K; R_0603_1608Metric
R46: 1M; R_0603_1608Metric
SW1: JS202011SCQN; SW_DPDT_CK_JS202011SCQN
SW2: EVQ-Q2B03W; SW_SPST_EVQQ2
TP20: PU5; TestPoint_Pad_D1.0mm
TP21: PD5; TestPoint_Pad_D1.0mm
TP22: PU6; TestPoint_Pad_D1.0mm
TP23: PD6; TestPoint_Pad_D1.0mm
TP24: PU7; TestPoint_Pad_D1.0mm
TP25: PD7; TestPoint_Pad_D1.0mm
TP26: PU8; TestPoint_Pad_D1.0mm
TP27: PD8; TestPoint_Pad_D1.0mm
TP28: PG8; TestPoint_Pad_D1.0mm
TP29: PG9; TestPoint_Pad_D1.0mm
TP30: PG10; TestPoint_Pad_D1.0mm
TP31: PG11; TestPoint_Pad_D1.0mm
TP32: PG12; TestPoint_Pad_D1.0mm
TP33: PG13; TestPoint_Pad_D1.0mm
TP34: PG14; TestPoint_Pad_D1.0mm
TP35: PG15; TestPoint_Pad_D1.0mm
TP36: PF3; TestPoint_Pad_D1.0mm
TP37: PF4; TestPoint_Pad_D1.0mm
TP38: PF5; TestPoint_Pad_D1.0mm
TP39: PF6; TestPoint_Pad_D1.0mm
TP40: PF7; TestPoint_Pad_D1.0mm
TP41: PF8; TestPoint_Pad_D1.0mm
TP42: PF9; TestPoint_Pad_D1.0mm
TP43: PF10; TestPoint_Pad_D1.0mm
TP44: PF11; TestPoint_Pad_D1.0mm
TP45: PF12; TestPoint_Pad_D1.0mm
TP46: PF13; TestPoint_Pad_D1.0mm
TP47: PF14; TestPoint_Pad_D1.0mm
TP48: PF15; TestPoint_Pad_D1.0mm
TP49: PE0; TestPoint_Pad_D1.0mm
TP50: PE1; TestPoint_Pad_D1.0mm
TP51: PE2; TestPoint_Pad_D1.0mm
TP52: PE3; TestPoint_Pad_D1.0mm
TP53: PE4; TestPoint_Pad_D1.0mm
TP54: PE5; TestPoint_Pad_D1.0mm
TP55: PE6; TestPoint_Pad_D1.0mm
TP56: PE7; TestPoint_Pad_D1.0mm
TP57: PE12; TestPoint_Pad_D1.0mm
TP58: PE13; TestPoint_Pad_D1.0mm
TP59: PE14; TestPoint_Pad_D1.0mm
TP60: PE15; TestPoint_Pad_D1.0mm
TP61: OUT1; TestPoint_Pad_D1.0mm
TP62: OUT2; TestPoint_Pad_D1.0mm
TP63: OUT3; TestPoint_Pad_D1.0mm
TP64: OUT4; TestPoint_Pad_D1.0mm
TP65: IN1; TestPoint_Pad_D1.0mm
TP66: IN2; TestPoint_Pad_D1.0mm
TP67: IN3; TestPoint_Pad_D1.0mm
TP68: IN4; TestPoint_Pad_D1.0mm
TP69: TRIS1; TestPoint_Pad_D1.0mm
TP70: TRIS2; TestPoint_Pad_D1.0mm
TP71: TRIS3; TestPoint_Pad_D1.0mm
TP72: TRIS4; TestPoint_Pad_D1.0mm
TP73: DIFF12; TestPoint_Pad_D1.0mm
TP74: TERM12; TestPoint_Pad_D1.0mm
TP75: DIFF34; TestPoint_Pad_D1.0mm
TP76: TERM34; TestPoint_Pad_D1.0mm
TP77: PU1; TestPoint_Pad_D1.0mm
TP78: PU2; TestPoint_Pad_D1.0mm
TP79: PU3; TestPoint_Pad_D1.0mm
TP80: PU4; TestPoint_Pad_D1.0mm
TP82: TXO; TestPoint_Pad_D1.0mm
TP83: RXI; TestPoint_Pad_D1.0mm
TP84: DM; TestPoint_Pad_D1.0mm
TP85: DP; TestPoint_Pad_D1.0mm
TP89: DIFF78; TestPoint_Pad_D1.0mm
TP90: TERM78; TestPoint_Pad_D1.0mm
TP91: DIFF56; TestPoint_Pad_D1.0mm
TP92: TERM56; TestPoint_Pad_D1.0mm
TP93: OUT5; TestPoint_Pad_D1.0mm
TP94: OUT6; TestPoint_Pad_D1.0mm
TP95: OUT7; TestPoint_Pad_D1.0mm
TP96: OUT8; TestPoint_Pad_D1.0mm
TP97: TRIS5; TestPoint_Pad_D1.0mm
TP98: TRIS6; TestPoint_Pad_D1.0mm
TP99: TRIS7; TestPoint_Pad_D1.0mm
TP100: TRIS8; TestPoint_Pad_D1.0mm
TP101: SCL; TestPoint_Pad_D1.0mm
TP102: SDA; TestPoint_Pad_D1.0mm
TP103: VSET; TestPoint_Pad_D1.0mm
TP104: PD1; TestPoint_Pad_D1.0mm
TP105: PD2; TestPoint_Pad_D1.0mm
TP106: PD3; TestPoint_Pad_D1.0mm
TP107: PD4; TestPoint_Pad_D1.0mm
TP174: PRST; TestPoint_Pad_D1.0mm
U2: STM32H743ZITx; LQFP-144_20x20mm_P0.5mm
U3: USB3300-EZK; QFN-32-1EP_5x5mm_P0.5mm_EP3.45x3.45mm
Y1: 48MHz; Crystal_SMD_Murata_XRCGB
Y2: 24MHz; Crystal_SMD_Murata_XRCGB

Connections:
/3.3V: C8.1, C9.1, C10.1, C11.1, C15.1, C16.1, C17.1, C19.1, C20.1, C22.1, C23.1, C24.1, C25.1, C26.1, C27.1, C31.1, C35.1, C36.1, C38.1, FB1.1, J4.1, R16.1, R18.1, R21.1, R24.1, R26.1, R32.1, R35.1, R37.1, SW1.3 (C), U2.6 (VBAT), U2.17 (VDD), U2.30 (VDD), U2.39 (VDD), U2.52 (VDD), U2.62 (VDD), U2.72 (VDD), U2.84 (VDD), U2.95 (VDD33_USB), U2.108 (VDD), U2.121 (VDD), U2.131 (VDD), U2.144 (VDD), U3.6 (VDD3.3), U3.16 (VDD3.3), U3.25 (VDD3.3), U3.30 (VDD3.3), U3.31 (REG_EN); also elsewhere on the board
/Adjustable Regulator/SETPOINT: TP103.1, U2.40 (PA4); also elsewhere on the board
/D+: U3.7 (DP); also elsewhere on the board
/D-: U3.8 (DM); also elsewhere on the board
/Level Shifter - I/O Pins 1&2/I2C_SCL: R16.2, TP101.1, U2.100 (PA8); also elsewhere on the board
/Level Shifter - I/O Pins 1&2/I2C_SDA: R18.2, TP102.1, U2.99 (PC9); also elsewhere on the board
/Level Shifter - I/O Pins 1&2/IO_1&2_DIFF: R17.1, TP73.1, U2.87 (PG2); also elsewhere on the board
/Level Shifter - I/O Pins 1&2/IO_1_IN: R13.1, TP65.1, U2.59 (PE8); also elsewhere on the board
/Level Shifter - I/O Pins 1&2/IO_1_OUT: D7.2 (K1), R10.1, TP61.1, U2.34 (PA0), U2.114 (PD0); also elsewhere on the board
/Level Shifter - I/O Pins 1&2/IO_1_PU: R20.1, TP77.1, U2.75 (PB14); also elsewhere on the board
/Level Shifter - I/O Pins 1&2/IO_2_IN: R22.1, TP66.1, U2.60 (PE9); also elsewhere on the board
/Level Shifter - I/O Pins 1&2/IO_2_OUT: D8.2 (K1), R12.1, TP62.1, U2.35 (PA1), U2.115 (PD1); also elsewhere on the board
/Level Shifter - I/O Pins 1&2/IO_2_PU: R23.1, TP78.1, U2.90 (PG5); also elsewhere on the board
/Level Shifter - I/O Pins 1&2/~IO_1&2_TERM: R26.2, TP74.1, U2.88 (PG3); also elsewhere on the board
/Level Shifter - I/O Pins 1&2/~IO_1_PD: R21.2, TP104.1, U2.76 (PB15); also elsewhere on the board
/Level Shifter - I/O Pins 1&2/~IO_1_TRIS: R11.1, R14.1, TP69.1, U2.77 (PD8); also elsewhere on the board
/Level Shifter - I/O Pins 1&2/~IO_2_PD: R24.2, TP105.1, U2.89 (PG4); also elsewhere on the board
/Level Shifter - I/O Pins 1&2/~IO_2_TRIS: R15.1, R19.1, TP70.1, U2.78 (PD9); also elsewhere on the board
/Level Shifter - I/O Pins 3&4/IO_3&4_DIFF: R38.1, TP75.1, U2.112 (PC11); also elsewhere on the board
/Level Shifter - I/O Pins 3&4/IO_3_IN: R33.1, TP67.1, U2.63 (PE10); also elsewhere on the board
/Level Shifter - I/O Pins 3&4/IO_3_OUT: D9.2 (K1), R25.1, TP63.1, U2.36 (PA2), U2.116 (PD2); also elsewhere on the board
/Level Shifter - I/O Pins 3&4/IO_3_PU: R41.1, TP79.1, U2.91 (PG6); also elsewhere on the board
/Level Shifter - I/O Pins 3&4/IO_4_IN: R40.1, TP68.1, U2.64 (PE11); also elsewhere on the board
/Level Shifter - I/O Pins 3&4/IO_4_OUT: D11.2 (K1), R31.1, TP64.1, U2.96 (PC6), U2.117 (PD3); also elsewhere on the board
/Level Shifter - I/O Pins 3&4/IO_4_PU: R42.1, TP80.1, U2.136 (PB6); also elsewhere on the board
/Level Shifter - I/O Pins 3&4/~IO_3&4_TERM: R37.2, TP76.1, U2.111 (PC10); also elsewhere on the board
/Level Shifter - I/O Pins 3&4/~IO_3_PD: R32.2, TP106.1, U2.92 (PG7); also elsewhere on the board
/Level Shifter - I/O Pins 3&4/~IO_3_TRIS: R30.1, R34.1, TP71.1, U2.79 (PD10); also elsewhere on the board
/Level Shifter - I/O Pins 3&4/~IO_4_PD: R35.2, TP107.1, U2.113 (PC12); also elsewhere on the board
/Level Shifter - I/O Pins 3&4/~IO_4_TRIS: R36.1, R39.1, TP72.1, U2.80 (PD11); also elsewhere on the board
/Microcontroller/IO_5&6_DIFF: TP91.1, U2.8 (PC14)
/Microcontroller/IO_5_IN: TP57.1, U2.65 (PE12)
/Microcontroller/IO_5_OUT: TP93.1, U2.118 (PD4), U2.137 (PB7)
/Microcontroller/IO_5_PU: TP20.1, U2.56 (PG0)
/Microcontroller/IO_6_IN: TP58.1, U2.66 (PE13)
/Microcontroller/IO_6_OUT: TP94.1, U2.119 (PD5), U2.139 (PB8)
/Microcontroller/IO_6_PU: TP22.1, U2.42 (PA6)
/Microcontroller/IO_7&8_DIFF: TP89.1, U2.7 (PC13)
/Microcontroller/IO_7_IN: TP59.1, U2.67 (PE14)
/Microcontroller/IO_7_OUT: TP95.1, U2.122 (PD6), U2.140 (PB9)
/Microcontroller/IO_7_PU: TP24.1, U2.27 (PC1)
/Microcontroller/IO_8_IN: TP60.1, U2.68 (PE15)
/Microcontroller/IO_8_OUT: TP96.1, U2.43 (PA7), U2.123 (PD7)
/Microcontroller/IO_8_PU: TP26.1, U2.45 (PC5)
/Microcontroller/OSC_IN: C13.1, R9.2, U2.24 (PH1), Y1.3
/Microcontroller/OSC_OUT: C12.1, R9.1, U2.23 (PH0), Y1.1
/Microcontroller/STATUS_B: R29.1, U2.10 (PF0)
/Microcontroller/STATUS_G: R28.1, U2.12 (PF2)
/Microcontroller/STATUS_R: R27.1, U2.11 (PF1)
/Microcontroller/TCK_SWDCLK: J4.4, U2.109 (PA14)
/Microcontroller/TDI: J4.8, U2.110 (PA15)
/Microcontroller/TDO_SWO: J4.6, U2.133 (PB3)
/Microcontroller/TMS_SWDIO: J4.2, U2.105 (PA13)
/Microcontroller/UART_RXI: TP83.1, U2.102 (PA10)
/Microcontroller/UART_TXO: TP82.1, U2.101 (PA9)
/Microcontroller/ULPI_CK: U2.41 (PA5), U3.14 (CLKOUT)
/Microcontroller/ULPI_D0: U2.37 (PA3), U3.24 (DATA0)
/Microcontroller/ULPI_D1: U2.46 (PB0), U3.23 (DATA1)
/Microcontroller/ULPI_D2: U2.47 (PB1), U3.22 (DATA2)
/Microcontroller/ULPI_D3: U2.69 (PB10), U3.21 (DATA3)
/Microcontroller/ULPI_D4: U2.70 (PB11), U3.20 (DATA4)
/Microcontroller/ULPI_D5: U2.73 (PB12), U3.19 (DATA5)
/Microcontroller/ULPI_D6: U2.74 (PB13), U3.18 (DATA6)
/Microcontroller/ULPI_D7: U2.135 (PB5), U3.17 (DATA7)
/Microcontroller/ULPI_DIR: U2.28 (PC2_C), U3.12 (DIR)
/Microcontroller/ULPI_NXT: U2.29 (PC3_C), U3.11 (NXT)
/Microcontroller/ULPI_STP: U2.26 (PC0), U3.13 (STP)
/Microcontroller/USB_FS_DM: TP84.1, U2.103 (PA11)
/Microcontroller/USB_FS_DP: TP85.1, U2.104 (PA12)
/Microcontroller/USB_VBUS: R44.2; also elsewhere on the board
/Microcontroller/VCAP: C7.1, C14.1, U2.71 (VCAP1), U2.106 (VCAP2)
/Microcontroller/VDD1.8: C29.1, C30.1, C32.1, U3.15 (VDD1.8), U3.26 (VDD1.8)
/Microcontroller/VDDA: FB1.2, U2.32 (VREF+), U2.33 (VDDA)
/Microcontroller/VDDA1.8: C37.1, C39.1, U3.29 (VDDA1.8)
/Microcontroller/XI: C34.1, R46.2, U3.28 (XI), Y2.3
/Microcontroller/XO: C33.1, R46.1, U3.27 (XO), Y2.1
/Microcontroller/nRESET: J4.10, U2.134 (PB4)
/Microcontroller/~IO_5&6_TERM: TP92.1, U2.9 (PC15)
/Microcontroller/~IO_5_PD: TP21.1, U2.57 (PG1)
/Microcontroller/~IO_5_TRIS: TP97.1, U2.81 (PD12)
/Microcontroller/~IO_6_PD: TP23.1, U2.48 (PB2)
/Microcontroller/~IO_6_TRIS: TP98.1, U2.82 (PD13)
/Microcontroller/~IO_7&8_TERM: TP90.1, U2.98 (PC8)
/Microcontroller/~IO_7_PD: TP25.1, U2.44 (PC4)
/Microcontroller/~IO_7_TRIS: TP99.1, U2.85 (PD14)
/Microcontroller/~IO_8_PD: TP27.1, U2.97 (PC7)
/Microcontroller/~IO_8_TRIS: TP100.1, U2.86 (PD15)
GND: C7.2, C8.2, C9.2, C10.2, C11.2, C12.2, C13.2, C14.2, C15.2, C16.2, C17.2, C19.2, C20.2, C22.2, C23.2, C24.2, C25.2, C26.2, C27.2, C28.2, C29.2, C30.2, C31.2, C32.2, C33.2, C34.2, C35.2, C36.2, C37.2, C38.2, C39.2, D7.4 (K2), D8.4 (K2), D9.4 (K2), D10.1 (GK), D10.3 (RK), D10.5 (BK), D11.4 (K2), D12.2 (A), J4.3, J4.5, J4.9, R10.2, R12.2, R14.2, R15.2, R17.2, R20.2, R23.2, R25.2, R31.2, R34.2, R36.2, R38.2, R41.2, R42.2, R45.2, SW1.1 (A), SW2.1, U2.16 (VSS), U2.31 (VSSA), U2.38 (VSS), U2.51 (VSS), U2.61 (VSS), U2.83 (VSS), U2.94 (VSS), U2.107 (VSS), U2.120 (VSS), U2.130 (VSS), U3.1 (GND), U3.2 (GND), U3.33 (GND), Y1.2, Y1.4, Y2.2, Y2.4; also elsewhere on the board
unnamed: C28.1, SW2.2, U2.25 (NRST)
unnamed: D7.1 (A1), R11.2
unnamed: D7.3 (A2), R13.2
unnamed: D8.1 (A1), R19.2
unnamed: D8.3 (A2), R22.2
unnamed: D9.1 (A1), R30.2
unnamed: D9.3 (A2), R33.2
unnamed: D10.2 (GA), R28.2
unnamed: D10.4 (RA), R27.2
unnamed: D10.6 (BA), R29.2
unnamed: D11.1 (A1), R39.2
unnamed: D11.3 (A2), R40.2
unnamed: D12.1 (K), R44.1, U3.4 (VBUS)
unnamed: R43.1, U2.138 (BOOT0)
unnamed: R43.2, SW1.2 (B)
unnamed: R45.1, U3.32 (RBIAS)
unnamed: TP28.1, U2.93 (PG8)
unnamed: TP29.1, U2.124 (PG9)
unnamed: TP30.1, U2.125 (PG10)
unnamed: TP31.1, U2.126 (PG11)
unnamed: TP32.1, U2.127 (PG12)
unnamed: TP33.1, U2.128 (PG13)
unnamed: TP34.1, U2.129 (PG14)
unnamed: TP35.1, U2.132 (PG15)
unnamed: TP36.1, U2.13 (PF3)
unnamed: TP37.1, U2.14 (PF4)
unnamed: TP38.1, U2.15 (PF5)
unnamed: TP39.1, U2.18 (PF6)
unnamed: TP40.1, U2.19 (PF7)
unnamed: TP41.1, U2.20 (PF8)
unnamed: TP42.1, U2.21 (PF9)
unnamed: TP43.1, U2.22 (PF10)
unnamed: TP44.1, U2.49 (PF11)
unnamed: TP45.1, U2.50 (PF12)
unnamed: TP46.1, U2.53 (PF13)
unnamed: TP47.1, U2.54 (PF14)
unnamed: TP48.1, U2.55 (PF15)
unnamed: TP49.1, U2.141 (PE0)
unnamed: TP50.1, U2.142 (PE1)
unnamed: TP51.1, U2.1 (PE2)
unnamed: TP52.1, U2.2 (PE3)
unnamed: TP53.1, U2.3 (PE4)
unnamed: TP54.1, U2.4 (PE5)
unnamed: TP55.1, U2.5 (PE6)
unnamed: TP56.1, U2.58 (PE7)
unnamed: TP174.1, U3.9 (RESET)

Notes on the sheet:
STM32H7 MICROCONTROLLER
USB 2.0 HIGH SPEED PHY
NOTE: DECOUPLING CAPS, PLACE CLOSE TO VDD1.8
NOTE: DECOUPLING CAPS, PLACE CLOSE TO VDD3.3
NOTE: DECOUPLING CAPS, PLACE CLOSE TO VDDA1.8
NOTE: PLACE CRYSTAL CLOSE TO XO/XI
JTAG/SERIAL WIRE DEBUG
SWD I/O
SWD CLOCK
SWD TRACE
JTAG DATA IN
JTAG RESET
VCC
GND
KEY
GNDdetect
NOTE: DECOUPLING CAPS, PLACE CLOSE TO VDDA
NOTE: DECOUPLING CAPS, PLACE CLOSE TO VDD
NOTE: DECOUPLING CAPS, PLACE CLOSE TO VDD33_USB
BOOT SWITCH
NOTE: PLACE CRYSTAL CLOSE TO OSC_OUT/OSC_IN
RGB STATUS LED
RESET BUTTON
NOTE: DECOUPLING CAPS, PLACE CLOSE TO VCAP1/VCAP2
MCU ALTERNATE PIN FUNCTIONS: - PA0: TIM2_CH1 - PA1: TIM5_CH2 - PA2: TIM15_CH1 - PA4: DAC_OUT1 - PA7: TIM14_CH1 - PA8: I2C1_SCL - PA9: USART1_TX - PA10: USART1_RX - PB7: TIM4_CH2 - PB8: TIM16_CH1 - PB9: TIM17_CH1 - PC6: TIM3_CH1 - PC9: I2C1_SDA

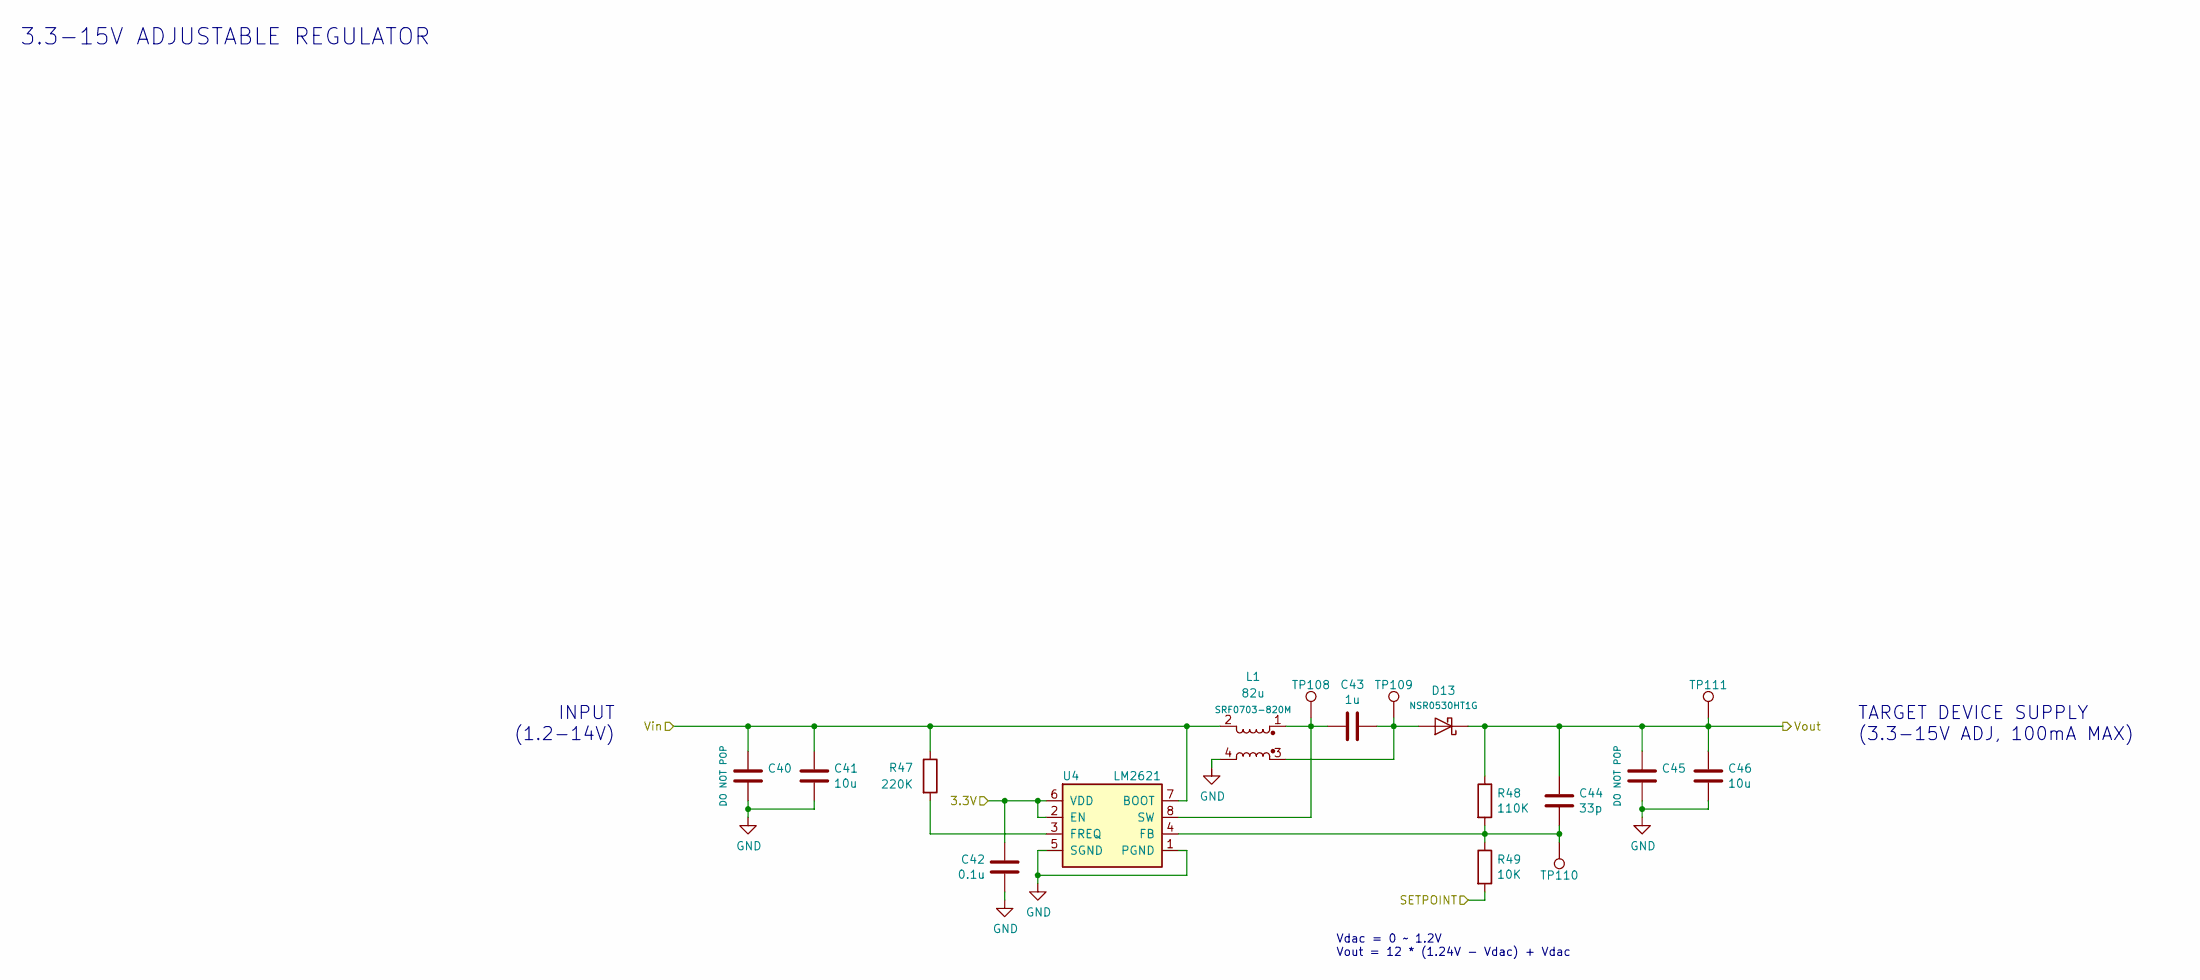
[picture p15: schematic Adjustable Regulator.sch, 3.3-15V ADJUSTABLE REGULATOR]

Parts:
C40, C45: C; C_1210_3225Metric
C41, C46: 10u; C_0805_2012Metric
C42: 0.1u; C_0603_1608Metric
C43: 1u; C_0603_1608Metric
C44: 33p; C_0603_1608Metric
D13: NSR0530HT1G; D_SOD-323
L1: 82u; L_Bourns_SRF0703
R47: 220K; R_0603_1608Metric
R48: 110K; R_0603_1608Metric
R49: 10K; R_0603_1608Metric
TP108: SW; TestPoint_Pad_D1.0mm
TP109: TestPoint; TestPoint_Pad_D1.0mm
TP110: FB; TestPoint_Pad_D1.0mm
TP111: Vout; TestPoint_Pad_D1.0mm
U4: LM2621; VSSOP-8_3.0x3.0mm_P0.65mm

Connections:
/3.3V: C42.1, U4.2 (EN), U4.6 (VDD); also elsewhere on the board
/Adjustable Regulator/SETPOINT: R49.2; also elsewhere on the board
/Vin: C40.1, C41.1, L1.2, R47.1, U4.7 (BOOT); also elsewhere on the board
/Vout: C44.1, C45.1, C46.1, D13.1 (K), R48.1, TP111.1; also elsewhere on the board
GND: C40.2, C41.2, C42.2, C45.2, C46.2, L1.4, U4.1 (PGND), U4.5 (SGND); also elsewhere on the board
unnamed: C43.1, D13.2 (A), L1.3, TP109.1
unnamed: C43.2, L1.1, TP108.1, U4.8 (SW)
unnamed: C44.2, R48.2, R49.1, TP110.1, U4.4 (FB)
unnamed: R47.2, U4.3 (FREQ)

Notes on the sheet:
INPUT (1.2-14V)
TARGET DEVICE SUPPLY (3.3-15V ADJ, 100mA MAX)
Vdac = 0 ~~ 1.2V Vout = 12 * (1.24V - Vdac) + Vdac
3.3-15V ADJUSTABLE REGULATOR

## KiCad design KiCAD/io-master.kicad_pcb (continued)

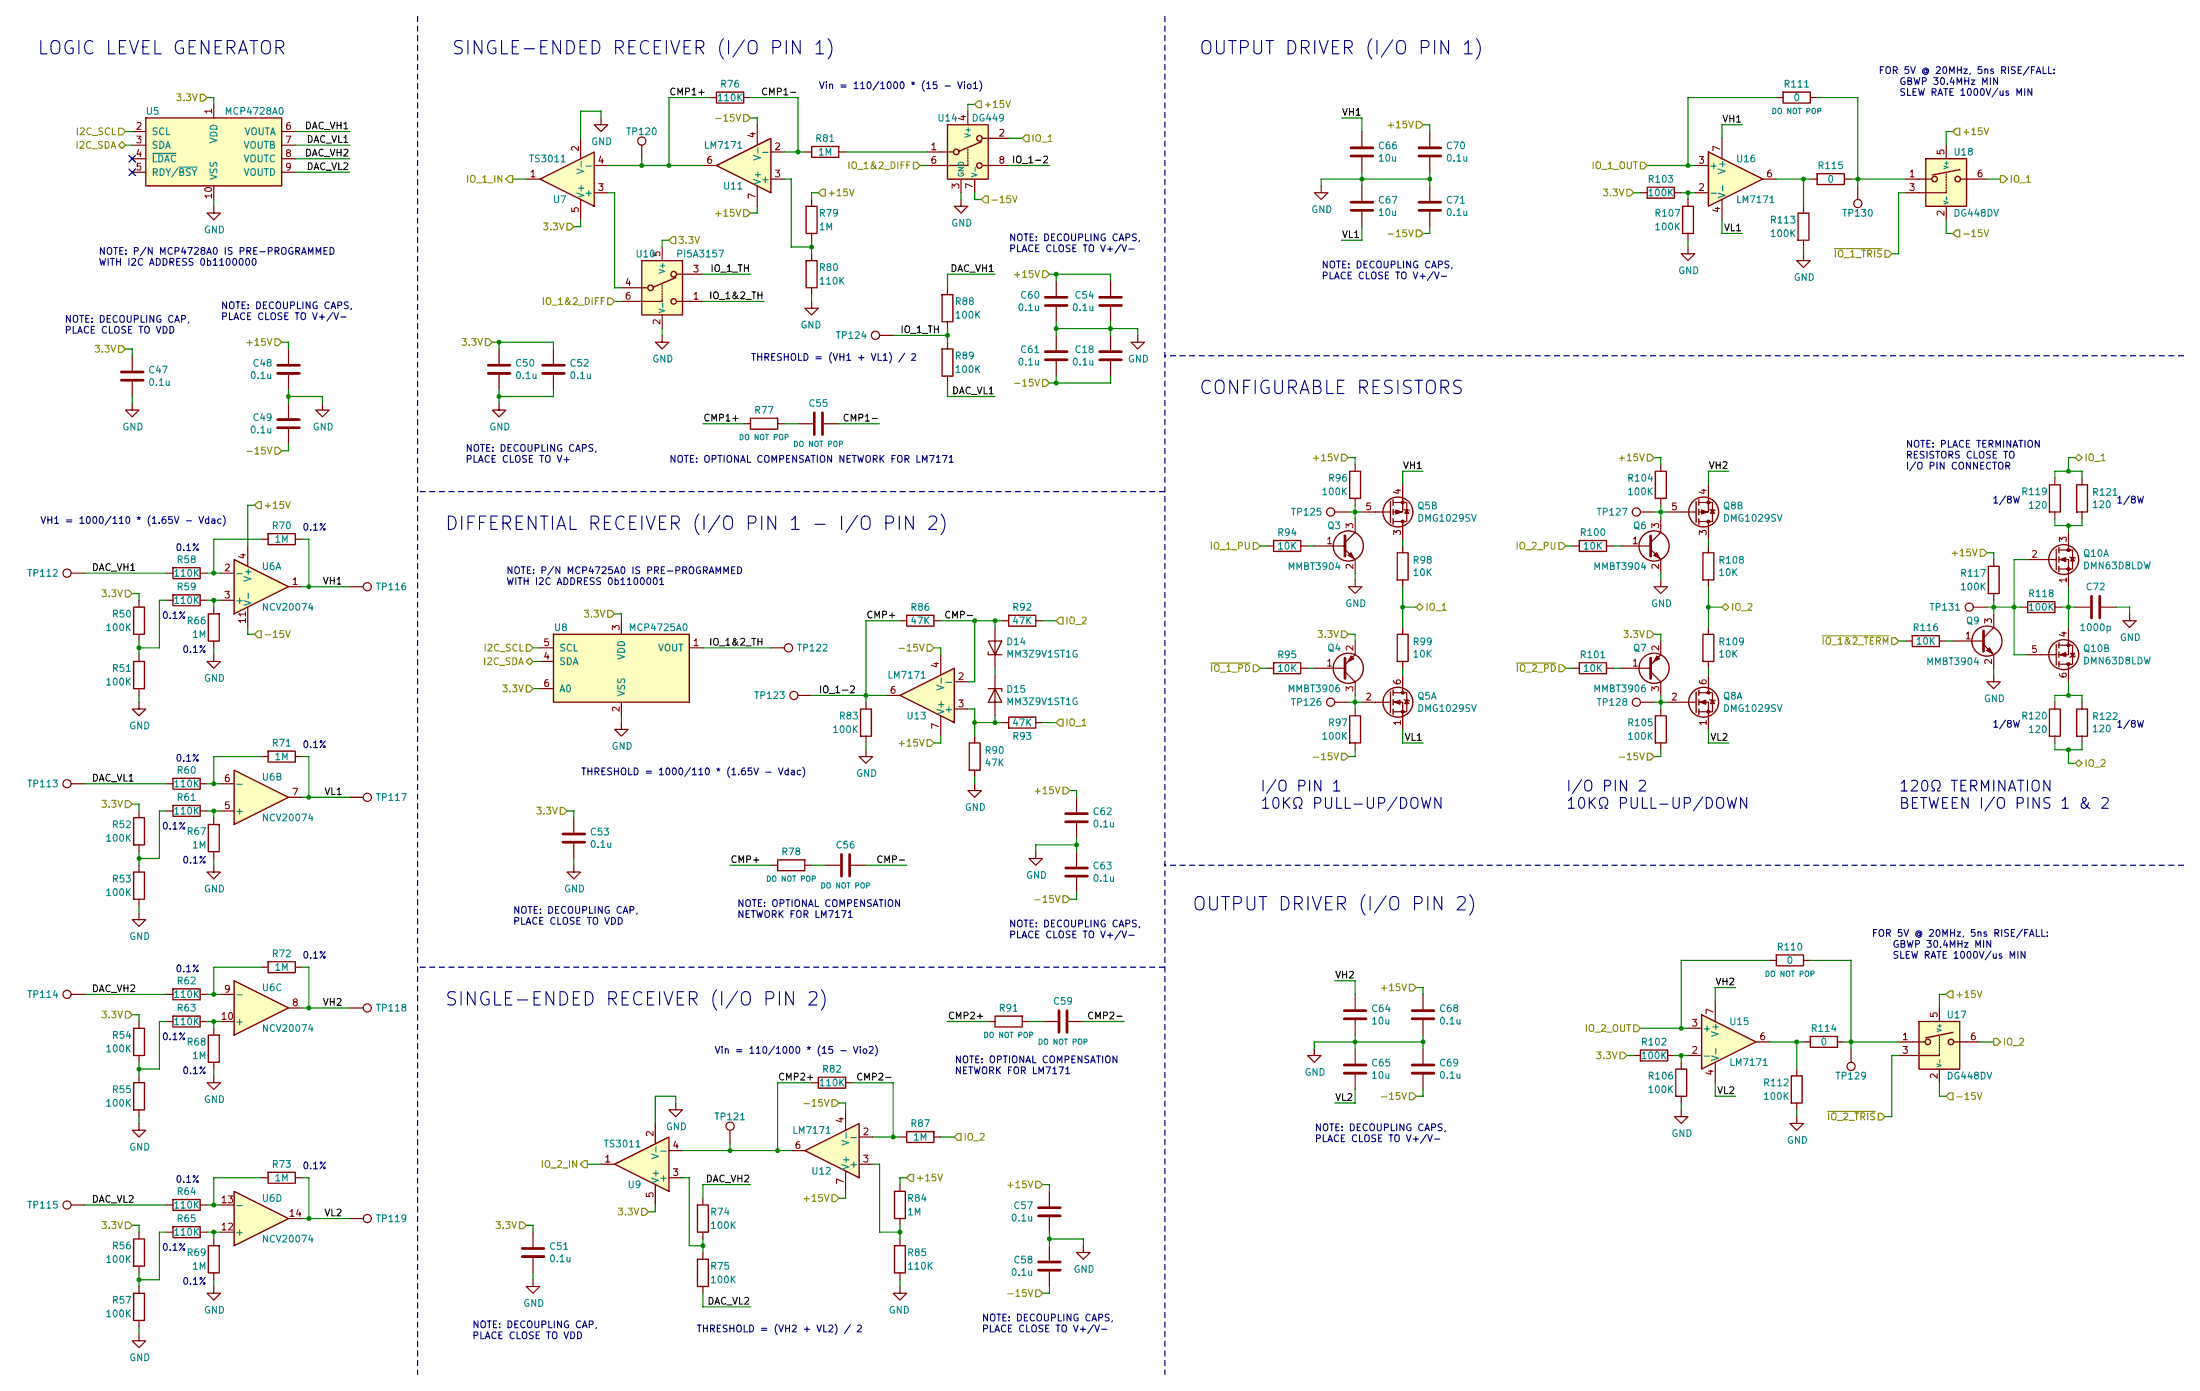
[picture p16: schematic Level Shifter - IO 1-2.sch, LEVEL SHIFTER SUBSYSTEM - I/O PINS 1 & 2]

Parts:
C18, C47, C48, C49, C50, C51, C52, C53, C54, C57, C58, C60, C61, C62, C63, C68, C69, C70, C71: 0.1u; C_0603_1608Metric
C55, C56, C59: C; C_0603_1608Metric
C64, C65, C66, C67: 10u; C_0805_2012Metric
C72: 1000p; C_0603_1608Metric
D14, D15: MM3Z9V1ST1G; D_SOD-323
Q3, Q6, Q9: MMBT3904; SOT-323_SC-70
Q4, Q7: MMBT3906; SOT-323_SC-70
Q5, Q8: DMG1029SV; SOT-563
Q10: DMN63D8LDW; SOT-363_SC-70-6
R50, R51, R52, R53, R54, R55, R56, R57, R74, R75, R83, R88, R89, R96, R97, R102, R103, R104, R105, R106, R107, R112, R113, R117, R118: 100K; R_0603_1608Metric
R58, R59, R60, R61, R62, R63, R64, R65, R76, R80, R82, R85: 110K; R_0603_1608Metric
R66, R67, R68, R69, R70, R71, R72, R73, R79, R81, R84, R87: 1M; R_0603_1608Metric
R77, R78, R91: R; R_0603_1608Metric
R86, R90, R92, R93: 47K; R_0603_1608Metric
R94, R95, R98, R99, R100, R101, R108, R109, R116: 10K; R_0603_1608Metric
R110, R111, R114, R115: 0; R_0603_1608Metric
R119, R120, R121, R122: 120; R_0805_2012Metric
TP112: DVH1; TestPoint_Pad_D1.0mm
TP113: DVL1; TestPoint_Pad_D1.0mm
TP114: DVH2; TestPoint_Pad_D1.0mm
TP115: DVL2; TestPoint_Pad_D1.0mm
TP116: VH1; TestPoint_Pad_D1.0mm
TP117: VL1; TestPoint_Pad_D1.0mm
TP118: VH2; TestPoint_Pad_D1.0mm
TP119: VL2; TestPoint_Pad_D1.0mm
TP120, TP121, TP125, TP126, TP127, TP128, TP129, TP130, TP131: TestPoint; TestPoint_Pad_D1.0mm
TP122: TH12; TestPoint_Pad_D1.0mm
TP123: 1-2; TestPoint_Pad_D1.0mm
TP124: TH1; TestPoint_Pad_D1.0mm
U5: MCP4728A0; MSOP-10_3x3mm_P0.5mm
U6: NCV20074; TSSOP-14_4.4x5mm_P0.65mm
U7, U9: TS3011; SOT-353_SC-70-5
U8: MCP4725A0; SOT-23-6
U10: PI5A3157; SOT-363_SC-70-6
U11, U12, U13, U15, U16: LM7171; SOIC-8_3.9x4.9mm_P1.27mm
U14: DG449; SOT-23-8
U17, U18: DG448DV; TSOP-6_1.65x3.05mm_P0.95mm

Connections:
/3.3V: C47.1, C50.1, C51.1, C52.1, C53.1, Q4.2 (E), Q7.2 (E), R50.1, R52.1, R54.1, R56.1, R102.2, R103.2, U5.1 (VDD), U7.5 (V+), U8.3 (VDD), U8.6 (A0), U9.5 (V+), U10.5 (V+); also elsewhere on the board
/+15V: C48.1, C54.1, C57.1, C60.1, C62.1, C68.1, C70.1, R79.2, R84.2, R96.1, R104.1, R117.1, U6.4 (V+), U11.7 (V+), U12.7 (V+), U13.7 (V+), U14.4 (V+), U17.5 (V+), U18.5 (V+); also elsewhere on the board
/-15V: C18.2, C49.2, C58.2, C61.2, C63.2, C69.2, C71.2, R97.2, R105.2, U6.11 (V-), U11.4 (V-), U12.4 (V-), U13.4 (V-), U14.7 (V-), U17.2 (V-), U18.2 (V-); also elsewhere on the board
/Circuit Protection - I/O Pin 1/IO_1: R93.1, R98.2, R99.1, R119.1, R121.1, U14.2, U18.6; also elsewhere on the board
/Circuit Protection - I/O Pin 2/IO_2: R87.2, R92.1, R108.2, R109.1, R120.2, R122.2, U17.6; also elsewhere on the board
/Level Shifter - I/O Pins 1&2/CMP1+: R76.1, R77.1, TP120.1, U7.4 (-), U11.6
/Level Shifter - I/O Pins 1&2/CMP1-: C55.1, R76.2, R81.1, U11.2 (-)
/Level Shifter - I/O Pins 1&2/CMP2+: R82.1, R91.1, TP121.1, U9.4 (-), U12.6
/Level Shifter - I/O Pins 1&2/CMP2-: C59.1, R82.2, R87.1, U12.2 (-)
/Level Shifter - I/O Pins 1&2/CMP+: R78.1, R83.1, R86.2, TP123.1, U13.6, U14.8
/Level Shifter - I/O Pins 1&2/CMP-: C56.1, D14.2 (A), R86.1, R92.2, U13.2 (-)
/Level Shifter - I/O Pins 1&2/DAC_VH1: R58.2, R88.2, TP112.1, U5.6 (VOUTA)
/Level Shifter - I/O Pins 1&2/DAC_VH2: R62.2, R74.2, TP114.1, U5.8 (VOUTC)
/Level Shifter - I/O Pins 1&2/DAC_VL1: R60.2, R89.1, TP113.1, U5.7 (VOUTB)
/Level Shifter - I/O Pins 1&2/DAC_VL2: R64.2, R75.1, TP115.1, U5.9 (VOUTD)
/Level Shifter - I/O Pins 1&2/I2C_SCL: U5.2 (SCL), U8.5 (SCL); also elsewhere on the board
/Level Shifter - I/O Pins 1&2/I2C_SDA: U5.3 (SDA), U8.4 (SDA); also elsewhere on the board
/Level Shifter - I/O Pins 1&2/IO_1&2_DIFF: U10.6, U14.6; also elsewhere on the board
/Level Shifter - I/O Pins 1&2/IO_1&2_TH: TP122.1, U8.1 (VOUT), U10.1
/Level Shifter - I/O Pins 1&2/IO_1_IN: U7.1; also elsewhere on the board
/Level Shifter - I/O Pins 1&2/IO_1_OUT: R111.2, U16.3 (+); also elsewhere on the board
/Level Shifter - I/O Pins 1&2/IO_1_PU: R94.2; also elsewhere on the board
/Level Shifter - I/O Pins 1&2/IO_1_TH: R88.1, R89.2, TP124.1, U10.3
/Level Shifter - I/O Pins 1&2/IO_2_IN: U9.1; also elsewhere on the board
/Level Shifter - I/O Pins 1&2/IO_2_OUT: R110.2, U15.3 (+); also elsewhere on the board
/Level Shifter - I/O Pins 1&2/IO_2_PU: R100.2; also elsewhere on the board
/Level Shifter - I/O Pins 1&2/VH1: C66.1, Q5.4 (S), R70.1, TP116.1, U6.1, U16.7 (V+)
/Level Shifter - I/O Pins 1&2/VH2: C64.1, Q8.4 (S), R72.1, TP118.1, U6.8, U15.7 (V+)
/Level Shifter - I/O Pins 1&2/VL1: C67.2, Q5.1 (S), R71.1, TP117.1, U6.7, U16.4 (V-)
/Level Shifter - I/O Pins 1&2/VL2: C65.2, Q8.1 (S), R73.1, TP119.1, U6.14, U15.4 (V-)
/Level Shifter - I/O Pins 1&2/~IO_1&2_TERM: R116.2; also elsewhere on the board
/Level Shifter - I/O Pins 1&2/~IO_1_PD: R95.2; also elsewhere on the board
/Level Shifter - I/O Pins 1&2/~IO_1_TRIS: U18.3; also elsewhere on the board
/Level Shifter - I/O Pins 1&2/~IO_2_PD: R101.2; also elsewhere on the board
/Level Shifter - I/O Pins 1&2/~IO_2_TRIS: U17.3; also elsewhere on the board
GND: C18.1, C47.2, C48.2, C49.1, C50.2, C51.2, C52.2, C53.2, C54.2, C57.2, C58.1, C60.2, C61.1, C62.2, C63.1, C64.2, C65.1, C66.2, C67.1, C68.2, C69.1, C70.2, C71.1, C72.1, Q3.2 (E), Q6.2 (E), Q9.2 (E), R51.2, R53.2, R55.2, R57.2, R66.1, R67.1, R68.1, R69.1, R80.1, R83.2, R85.1, R90.2, R106.2, R107.2, R112.2, R113.2, U5.10 (VSS), U7.2 (V-), U8.2 (VSS), U9.2 (V-), U10.2 (V-), U14.3 (GND); also elsewhere on the board
unnamed: C55.2, R77.2
unnamed: C56.2, R78.2
unnamed: C59.2, R91.2
unnamed: C72.2, Q10.1 (S), Q10.4 (S), R118.1
unnamed: D14.1 (K), D15.1 (K)
unnamed: D15.2 (A), R90.1, R93.2, U13.3 (+)
unnamed: Q3.1 (B), R94.1
unnamed: Q3.3 (C), Q5.5 (G), R96.2, TP125.1
unnamed: Q4.1 (B), R95.1
unnamed: Q4.3 (C), Q5.2 (G), R97.1, TP126.1
unnamed: Q5.3 (D), R98.1
unnamed: Q5.6 (D), R99.2
unnamed: Q6.1 (B), R100.1
unnamed: Q6.3 (C), Q8.5 (G), R104.2, TP127.1
unnamed: Q7.1 (B), R101.1
unnamed: Q7.3 (C), Q8.2 (G), R105.1, TP128.1
unnamed: Q8.3 (D), R108.1
unnamed: Q8.6 (D), R109.2
unnamed: Q9.1 (B), R116.1
unnamed: Q9.3 (C), Q10.2 (G), Q10.5 (G), R117.2, R118.2, TP131.1
unnamed: Q10.3 (D), R119.2, R121.2
unnamed: Q10.6 (D), R120.1, R122.1
unnamed: R50.2, R51.1, R59.2
unnamed: R52.2, R53.1, R61.2
unnamed: R54.2, R55.1, R63.2
unnamed: R56.2, R57.1, R65.2
unnamed: R58.1, R70.2, U6.2 (-)
unnamed: R59.1, R66.2, U6.3 (+)
unnamed: R60.1, R71.2, U6.6 (-)
unnamed: R61.1, R67.2, U6.5 (+)
unnamed: R62.1, R72.2, U6.9 (-)
unnamed: R63.1, R68.2, U6.10 (+)
unnamed: R64.1, R73.2, U6.13 (-)
unnamed: R65.1, R69.2, U6.12 (+)
unnamed: R74.1, R75.2, U9.3 (+)
unnamed: R79.1, R80.2, U11.3 (+)
unnamed: R81.2, U14.1
unnamed: R84.1, R85.2, U12.3 (+)
unnamed: R102.1, R106.1, U15.2 (-)
unnamed: R103.1, R107.1, U16.2 (-)
unnamed: R110.1, R114.1, TP129.1, U17.1
unnamed: R111.1, R115.1, TP130.1, U18.1
unnamed: R112.1, R114.2, U15.6
unnamed: R113.1, R115.2, U16.6
unnamed: U7.3 (+), U10.4

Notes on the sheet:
CONFIGURABLE RESISTORS
LOGIC LEVEL GENERATOR
OUTPUT DRIVER (I/O PIN 1)
OUTPUT DRIVER (I/O PIN 2)
DIFFERENTIAL RECEIVER (I/O PIN 1 - I/O PIN 2)
SINGLE-ENDED RECEIVER (I/O PIN 1)
SINGLE-ENDED RECEIVER (I/O PIN 2)
NOTE: DECOUPLING CAP, PLACE CLOSE TO VDD
VH1 = 1000/110 * (1.65V - Vdac)
NOTE: DECOUPLING CAPS, PLACE CLOSE TO V+/V-
NOTE: P/N MCP4728A0 IS PRE-PROGRAMMED WITH I2C ADDRESS 0b1100000
1/8W
NOTE: PLACE TERMINATION RESISTORS CLOSE TO I/O PIN CONNECTOR
FOR 5V @ 20MHz, 5ns RISE/FALL: GBWP 30.4MHz MIN SLEW RATE 1000V/us MIN
0.1%
NOTE: P/N MCP4725A0 IS PRE-PROGRAMMED WITH I2C ADDRESS 0b1100001
Vin = 110/1000 * (15 - Vio1)
THRESHOLD = (VH1 + VL1) / 2
Vin = 110/1000 * (15 - Vio2)
THRESHOLD = (VH2 + VL2) / 2
NOTE: DECOUPLING CAPS, PLACE CLOSE TO V+
THRESHOLD = 1000/110 * (1.65V - Vdac)
I/O PIN 1 10KΩ PULL-UP/DOWN
I/O PIN 2 10KΩ PULL-UP/DOWN
120Ω TERMINATION BETWEEN I/O PINS 1 & 2
NOTE: OPTIONAL COMPENSATION NETWORK FOR LM7171
NOTE: OPTIONAL COMPENSATION NETWORK FOR LM7171

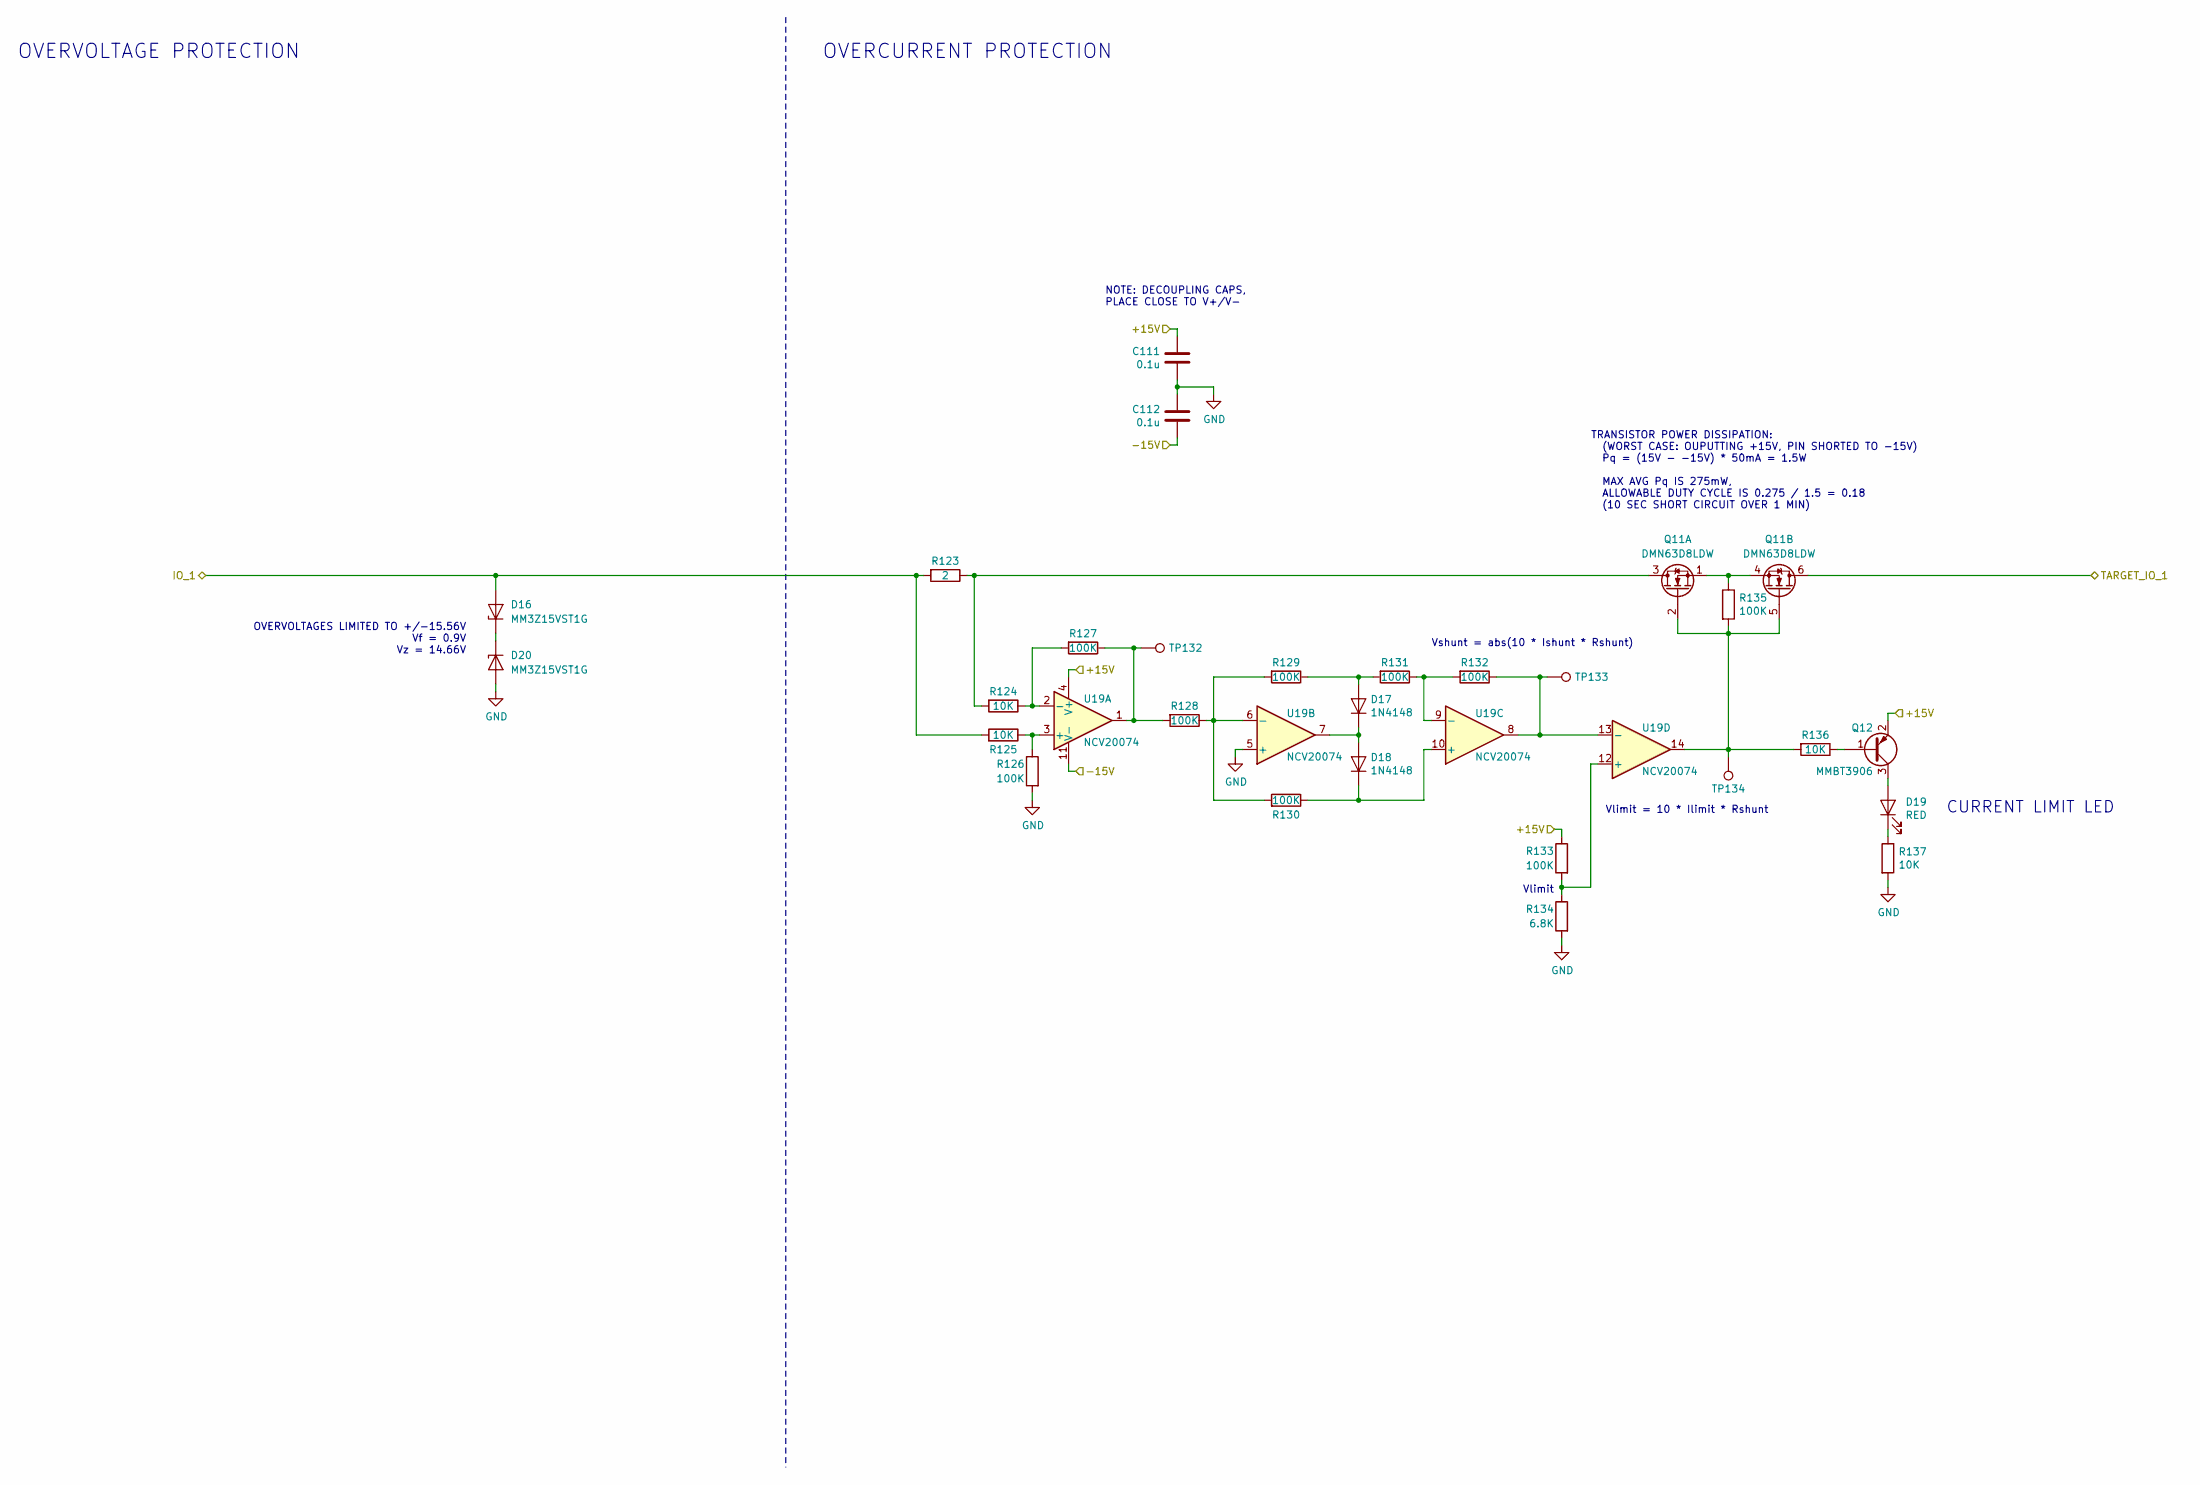
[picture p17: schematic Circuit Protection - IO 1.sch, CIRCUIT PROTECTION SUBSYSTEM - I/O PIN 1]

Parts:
C111, C112: 0.1u; C_0603_1608Metric
D16, D20: MM3Z15VST1G; D_SOD-323
D17, D18: 1N4148; D_SOD-323
D19: RED; LED_0603_1608Metric
Q11: DMN63D8LDW; SOT-363_SC-70-6
Q12: MMBT3906; SOT-323_SC-70
R123: 2; R_0603_1608Metric
R124, R125, R136, R137: 10K; R_0603_1608Metric
R126, R127, R128, R129, R130, R131, R132, R133, R135: 100K; R_0603_1608Metric
R134: 6.8K; R_0603_1608Metric
TP132, TP133, TP134: TestPoint; TestPoint_Pad_D1.0mm
U19: NCV20074; TSSOP-14_4.4x5mm_P0.65mm

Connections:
/+15V: C111.1, Q12.2 (E), R133.1, U19.4 (V+); also elsewhere on the board
/-15V: C112.2, U19.11 (V-); also elsewhere on the board
/Circuit Protection - I/O Pin 1/IO_1: D16.2 (A), R123.2, R125.2; also elsewhere on the board
/Circuit Protection - I/O Pin 1/TARGET_IO_1: Q11.6 (D); also elsewhere on the board
GND: C111.2, C112.1, D20.2 (A), R126.2, R134.2, R137.2, U19.5 (+); also elsewhere on the board
unnamed: D16.1 (K), D20.1 (K)
unnamed: D17.1 (K), D18.2 (A), U19.7
unnamed: D17.2 (A), R129.1, R131.2
unnamed: D18.1 (K), R130.1, U19.10 (+)
unnamed: D19.1 (K), R137.1
unnamed: D19.2 (A), Q12.3 (C)
unnamed: Q11.1 (S), Q11.4 (S), R135.1
unnamed: Q11.2 (G), Q11.5 (G), R135.2, R136.2, TP134.1, U19.14
unnamed: Q11.3 (D), R123.1, R124.2
unnamed: Q12.1 (B), R136.1
unnamed: R124.1, R127.2, U19.2 (-)
unnamed: R125.1, R126.1, U19.3 (+)
unnamed: R127.1, R128.2, TP132.1, U19.1
unnamed: R128.1, R129.2, R130.2, U19.6 (-)
unnamed: R131.1, R132.2, U19.9 (-)
unnamed: R132.1, TP133.1, U19.8, U19.13 (-)
unnamed: R133.2, R134.1, U19.12 (+)

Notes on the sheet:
OVERVOLTAGE PROTECTION
OVERCURRENT PROTECTION
Vshunt = abs(10 * Ishunt * Rshunt)
Vlimit = 10 * Ilimit * Rshunt
Vlimit
TRANSISTOR POWER DISSIPATION: (WORST CASE: OUPUTTING +15V, PIN SHORTED TO -15V) Pq = (15V - -15V) * 50mA = 1.5W MAX AVG Pq IS 275mW, ALLOWABLE DUTY CYCLE IS 0.275 / 1.5 = 0.18 (10 SEC SHORT CIRCUIT OVER 1 MIN)
CURRENT LIMIT LED
OVERVOLTAGES LIMITED TO +/-15.56V Vf = 0.9V Vz = 14.66V
NOTE: DECOUPLING CAPS, PLACE CLOSE TO V+/V-

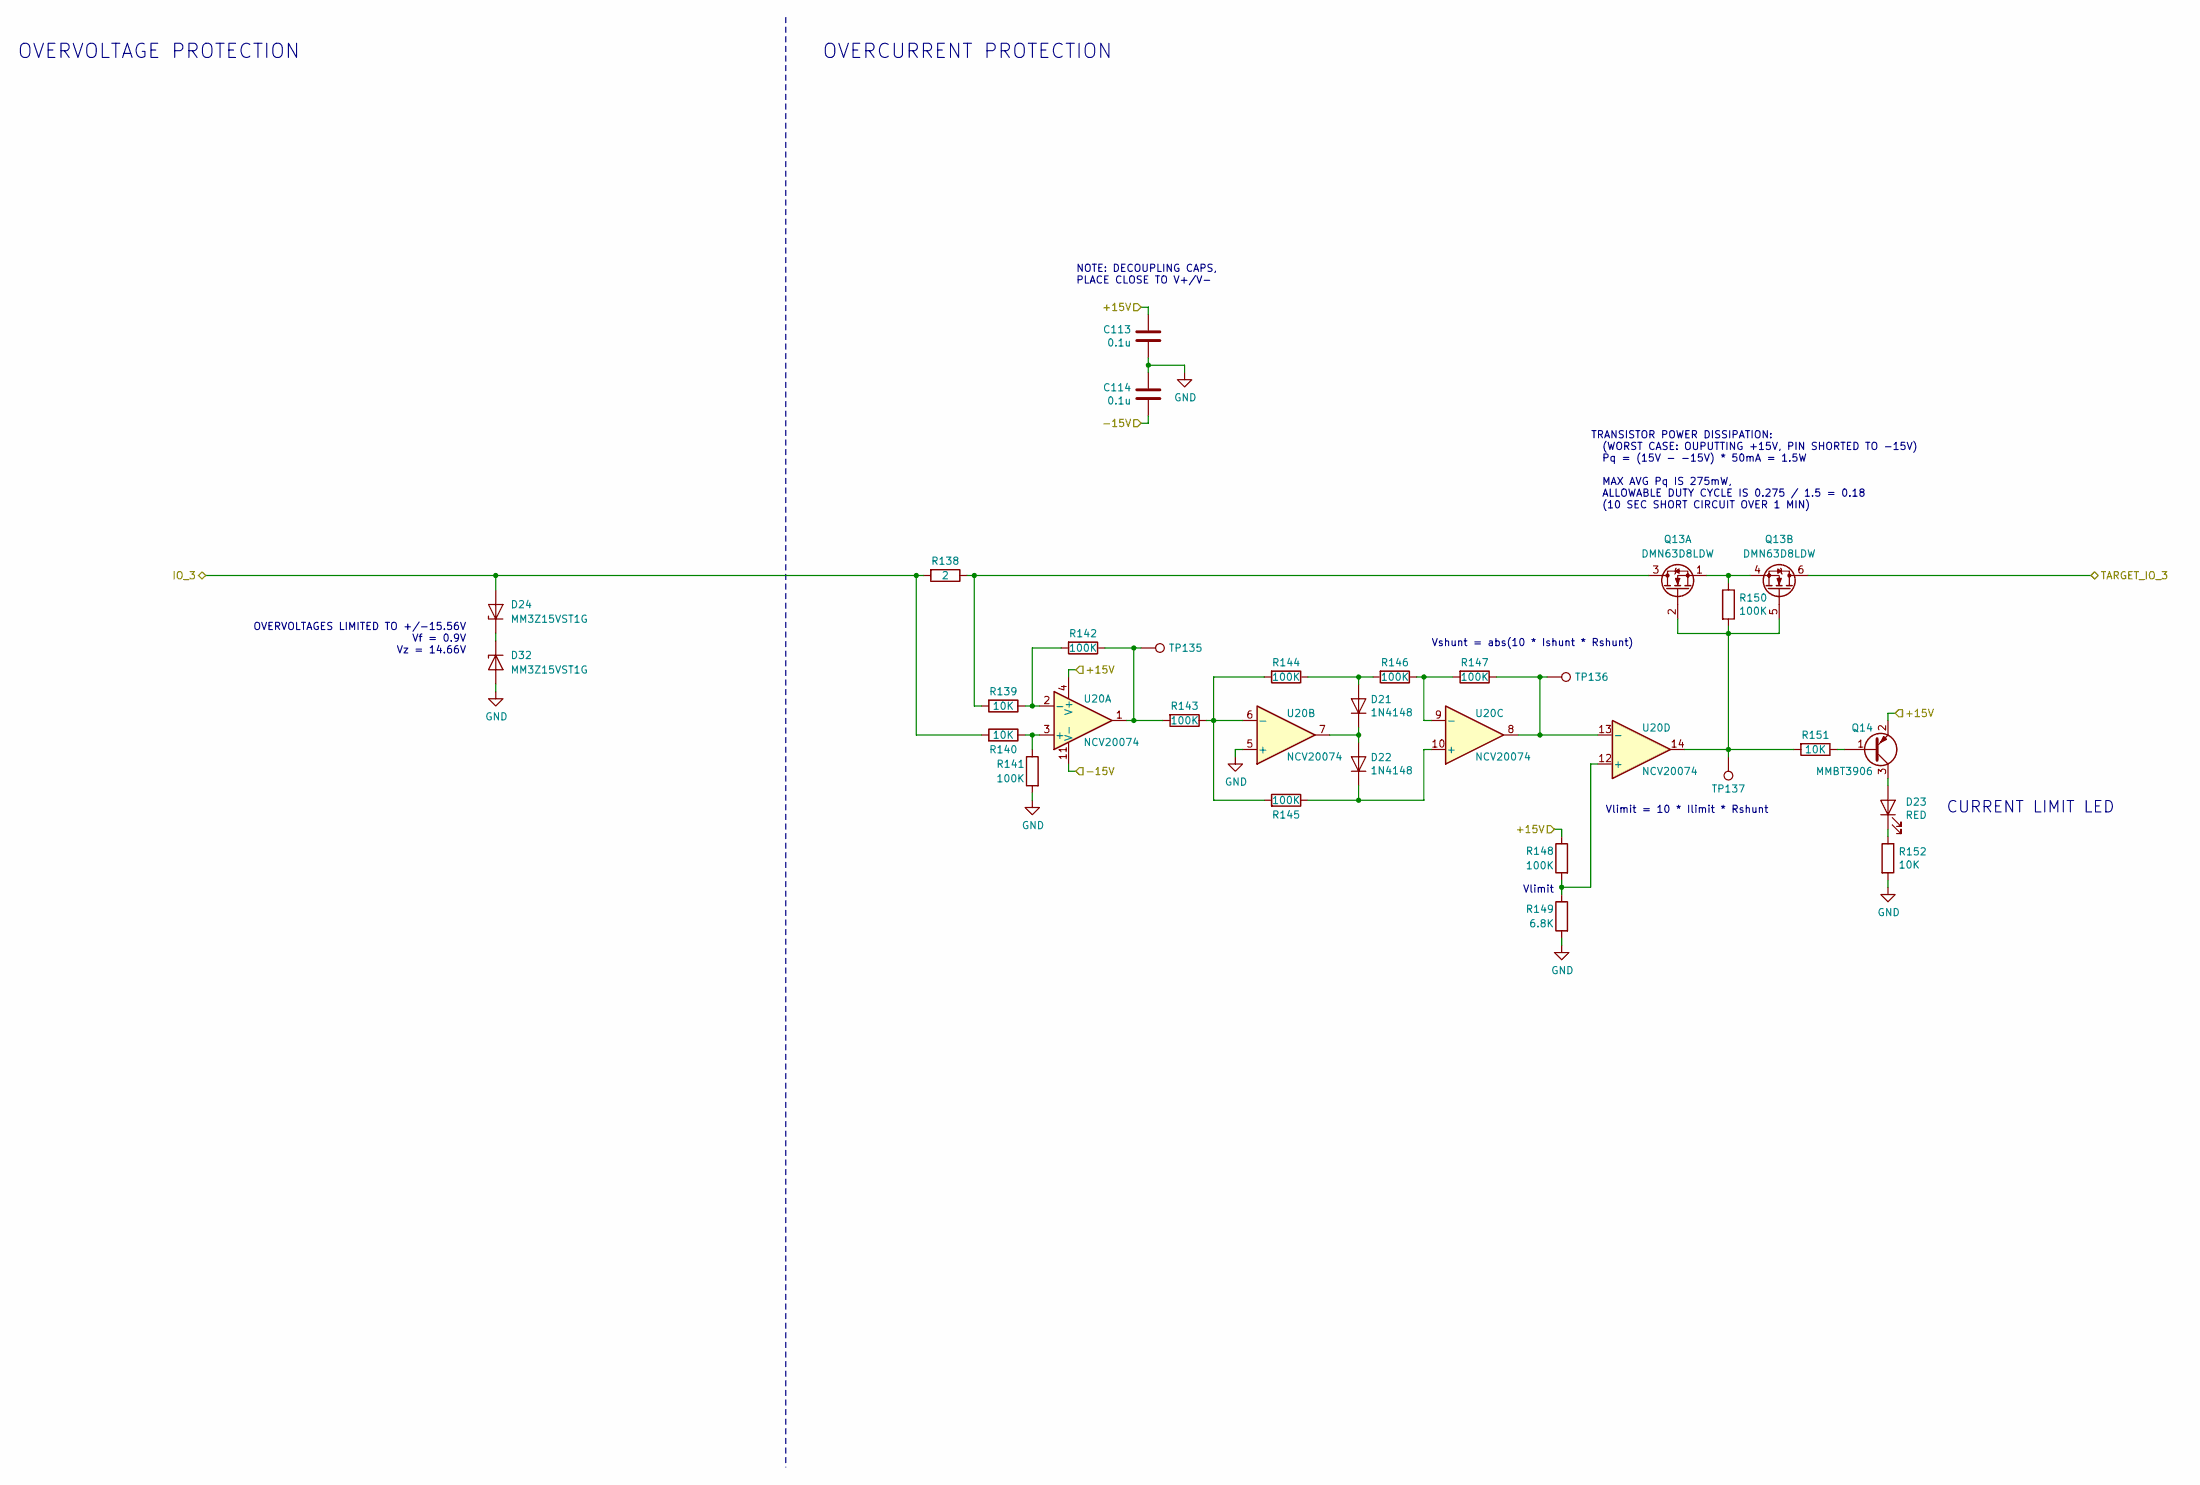
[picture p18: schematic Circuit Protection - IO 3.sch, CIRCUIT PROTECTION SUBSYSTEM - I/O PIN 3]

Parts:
C113, C114: 0.1u; C_0603_1608Metric
D21, D22: 1N4148; D_SOD-323
D23: RED; LED_0603_1608Metric
D24, D32: MM3Z15VST1G; D_SOD-323
Q13: DMN63D8LDW; SOT-363_SC-70-6
Q14: MMBT3906; SOT-323_SC-70
R138: 2; R_0603_1608Metric
R139, R140, R151, R152: 10K; R_0603_1608Metric
R141, R142, R143, R144, R145, R146, R147, R148, R150: 100K; R_0603_1608Metric
R149: 6.8K; R_0603_1608Metric
TP135, TP136, TP137: TestPoint; TestPoint_Pad_D1.0mm
U20: NCV20074; TSSOP-14_4.4x5mm_P0.65mm

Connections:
/+15V: C113.1, Q14.2 (E), R148.1, U20.4 (V+); also elsewhere on the board
/-15V: C114.2, U20.11 (V-); also elsewhere on the board
/Circuit Protection - I/O Pin 3/IO_3: D24.2 (A), R138.2, R140.2; also elsewhere on the board
/Circuit Protection - I/O Pin 3/TARGET_IO_3: Q13.6 (D); also elsewhere on the board
GND: C113.2, C114.1, D32.2 (A), R141.2, R149.2, R152.2, U20.5 (+); also elsewhere on the board
unnamed: D21.1 (K), D22.2 (A), U20.7
unnamed: D21.2 (A), R144.1, R146.2
unnamed: D22.1 (K), R145.1, U20.10 (+)
unnamed: D23.1 (K), R152.1
unnamed: D23.2 (A), Q14.3 (C)
unnamed: D24.1 (K), D32.1 (K)
unnamed: Q13.1 (S), Q13.4 (S), R150.1
unnamed: Q13.2 (G), Q13.5 (G), R150.2, R151.2, TP137.1, U20.14
unnamed: Q13.3 (D), R138.1, R139.2
unnamed: Q14.1 (B), R151.1
unnamed: R139.1, R142.2, U20.2 (-)
unnamed: R140.1, R141.1, U20.3 (+)
unnamed: R142.1, R143.2, TP135.1, U20.1
unnamed: R143.1, R144.2, R145.2, U20.6 (-)
unnamed: R146.1, R147.2, U20.9 (-)
unnamed: R147.1, TP136.1, U20.8, U20.13 (-)
unnamed: R148.2, R149.1, U20.12 (+)

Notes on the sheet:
OVERVOLTAGE PROTECTION
OVERCURRENT PROTECTION
Vshunt = abs(10 * Ishunt * Rshunt)
Vlimit = 10 * Ilimit * Rshunt
Vlimit
TRANSISTOR POWER DISSIPATION: (WORST CASE: OUPUTTING +15V, PIN SHORTED TO -15V) Pq = (15V - -15V) * 50mA = 1.5W MAX AVG Pq IS 275mW, ALLOWABLE DUTY CYCLE IS 0.275 / 1.5 = 0.18 (10 SEC SHORT CIRCUIT OVER 1 MIN)
CURRENT LIMIT LED
OVERVOLTAGES LIMITED TO +/-15.56V Vf = 0.9V Vz = 14.66V
NOTE: DECOUPLING CAPS, PLACE CLOSE TO V+/V-

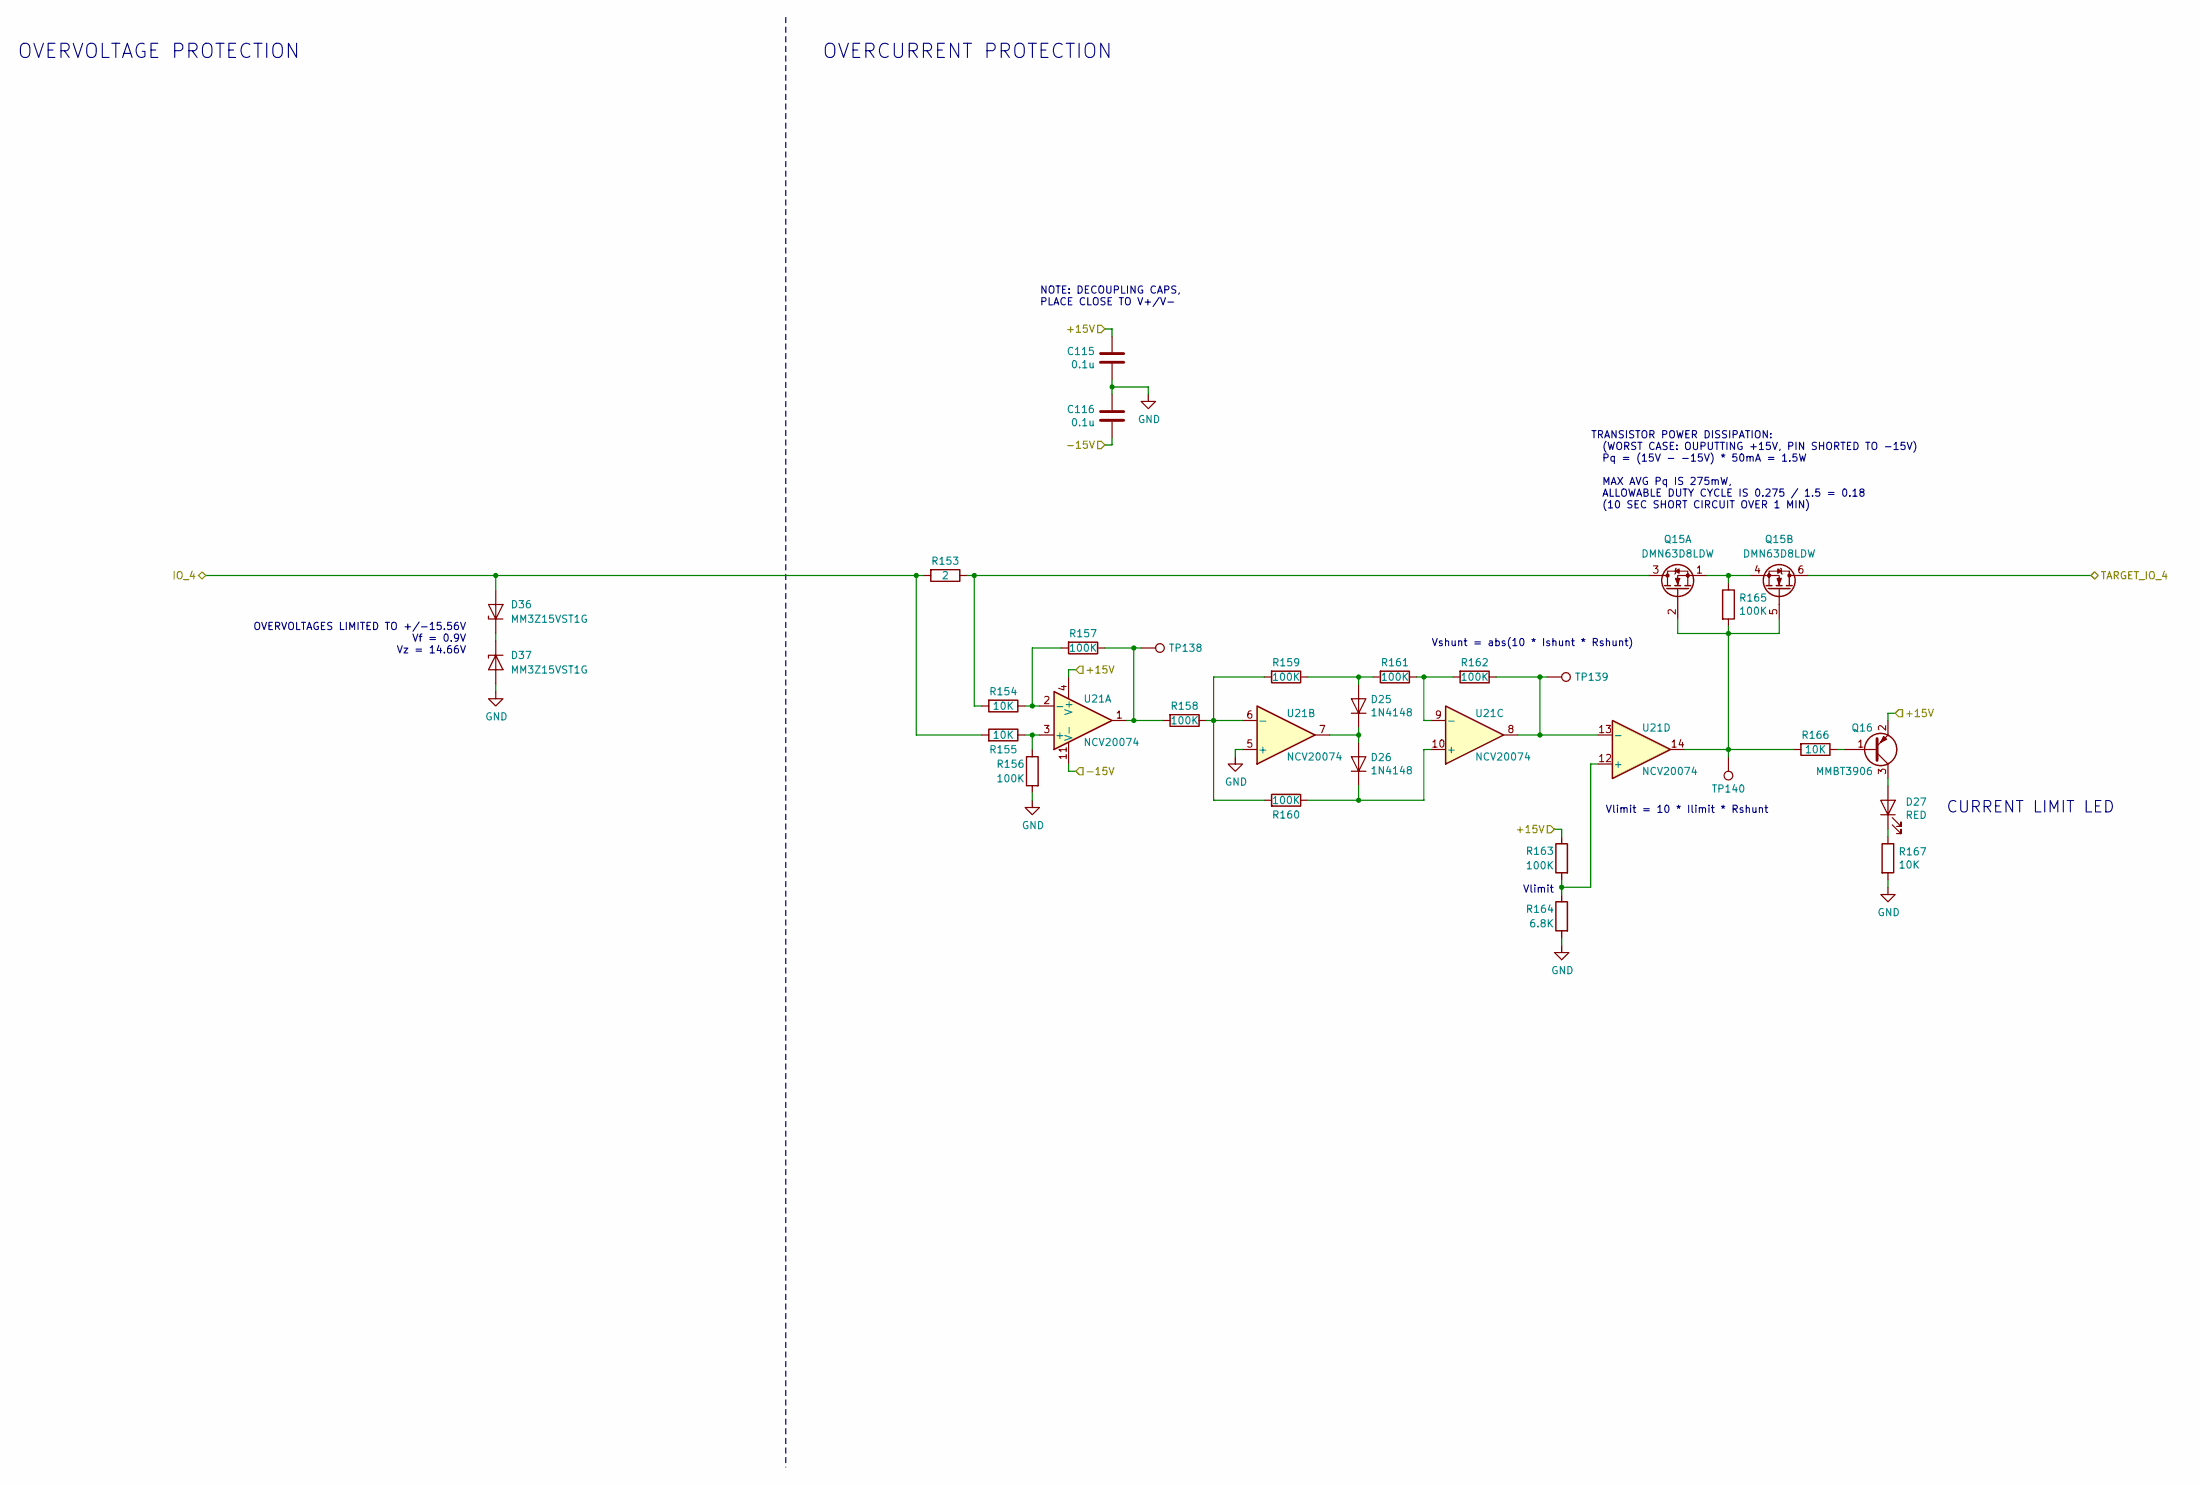
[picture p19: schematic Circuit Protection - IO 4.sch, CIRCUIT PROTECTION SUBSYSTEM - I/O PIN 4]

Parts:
C115, C116: 0.1u; C_0603_1608Metric
D25, D26: 1N4148; D_SOD-323
D27: RED; LED_0603_1608Metric
D36, D37: MM3Z15VST1G; D_SOD-323
Q15: DMN63D8LDW; SOT-363_SC-70-6
Q16: MMBT3906; SOT-323_SC-70
R153: 2; R_0603_1608Metric
R154, R155, R166, R167: 10K; R_0603_1608Metric
R156, R157, R158, R159, R160, R161, R162, R163, R165: 100K; R_0603_1608Metric
R164: 6.8K; R_0603_1608Metric
TP138, TP139, TP140: TestPoint; TestPoint_Pad_D1.0mm
U21: NCV20074; TSSOP-14_4.4x5mm_P0.65mm

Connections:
/+15V: C115.1, Q16.2 (E), R163.1, U21.4 (V+); also elsewhere on the board
/-15V: C116.2, U21.11 (V-); also elsewhere on the board
/Circuit Protection - I/O Pin 4/IO_4: D36.2 (A), R153.2, R155.2; also elsewhere on the board
/Circuit Protection - I/O Pin 4/TARGET_IO_4: Q15.6 (D); also elsewhere on the board
GND: C115.2, C116.1, D37.2 (A), R156.2, R164.2, R167.2, U21.5 (+); also elsewhere on the board
unnamed: D25.1 (K), D26.2 (A), U21.7
unnamed: D25.2 (A), R159.1, R161.2
unnamed: D26.1 (K), R160.1, U21.10 (+)
unnamed: D27.1 (K), R167.1
unnamed: D27.2 (A), Q16.3 (C)
unnamed: D36.1 (K), D37.1 (K)
unnamed: Q15.1 (S), Q15.4 (S), R165.1
unnamed: Q15.2 (G), Q15.5 (G), R165.2, R166.2, TP140.1, U21.14
unnamed: Q15.3 (D), R153.1, R154.2
unnamed: Q16.1 (B), R166.1
unnamed: R154.1, R157.2, U21.2 (-)
unnamed: R155.1, R156.1, U21.3 (+)
unnamed: R157.1, R158.2, TP138.1, U21.1
unnamed: R158.1, R159.2, R160.2, U21.6 (-)
unnamed: R161.1, R162.2, U21.9 (-)
unnamed: R162.1, TP139.1, U21.8, U21.13 (-)
unnamed: R163.2, R164.1, U21.12 (+)

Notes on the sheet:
OVERVOLTAGE PROTECTION
OVERCURRENT PROTECTION
Vshunt = abs(10 * Ishunt * Rshunt)
Vlimit = 10 * Ilimit * Rshunt
Vlimit
TRANSISTOR POWER DISSIPATION: (WORST CASE: OUPUTTING +15V, PIN SHORTED TO -15V) Pq = (15V - -15V) * 50mA = 1.5W MAX AVG Pq IS 275mW, ALLOWABLE DUTY CYCLE IS 0.275 / 1.5 = 0.18 (10 SEC SHORT CIRCUIT OVER 1 MIN)
CURRENT LIMIT LED
OVERVOLTAGES LIMITED TO +/-15.56V Vf = 0.9V Vz = 14.66V
NOTE: DECOUPLING CAPS, PLACE CLOSE TO V+/V-

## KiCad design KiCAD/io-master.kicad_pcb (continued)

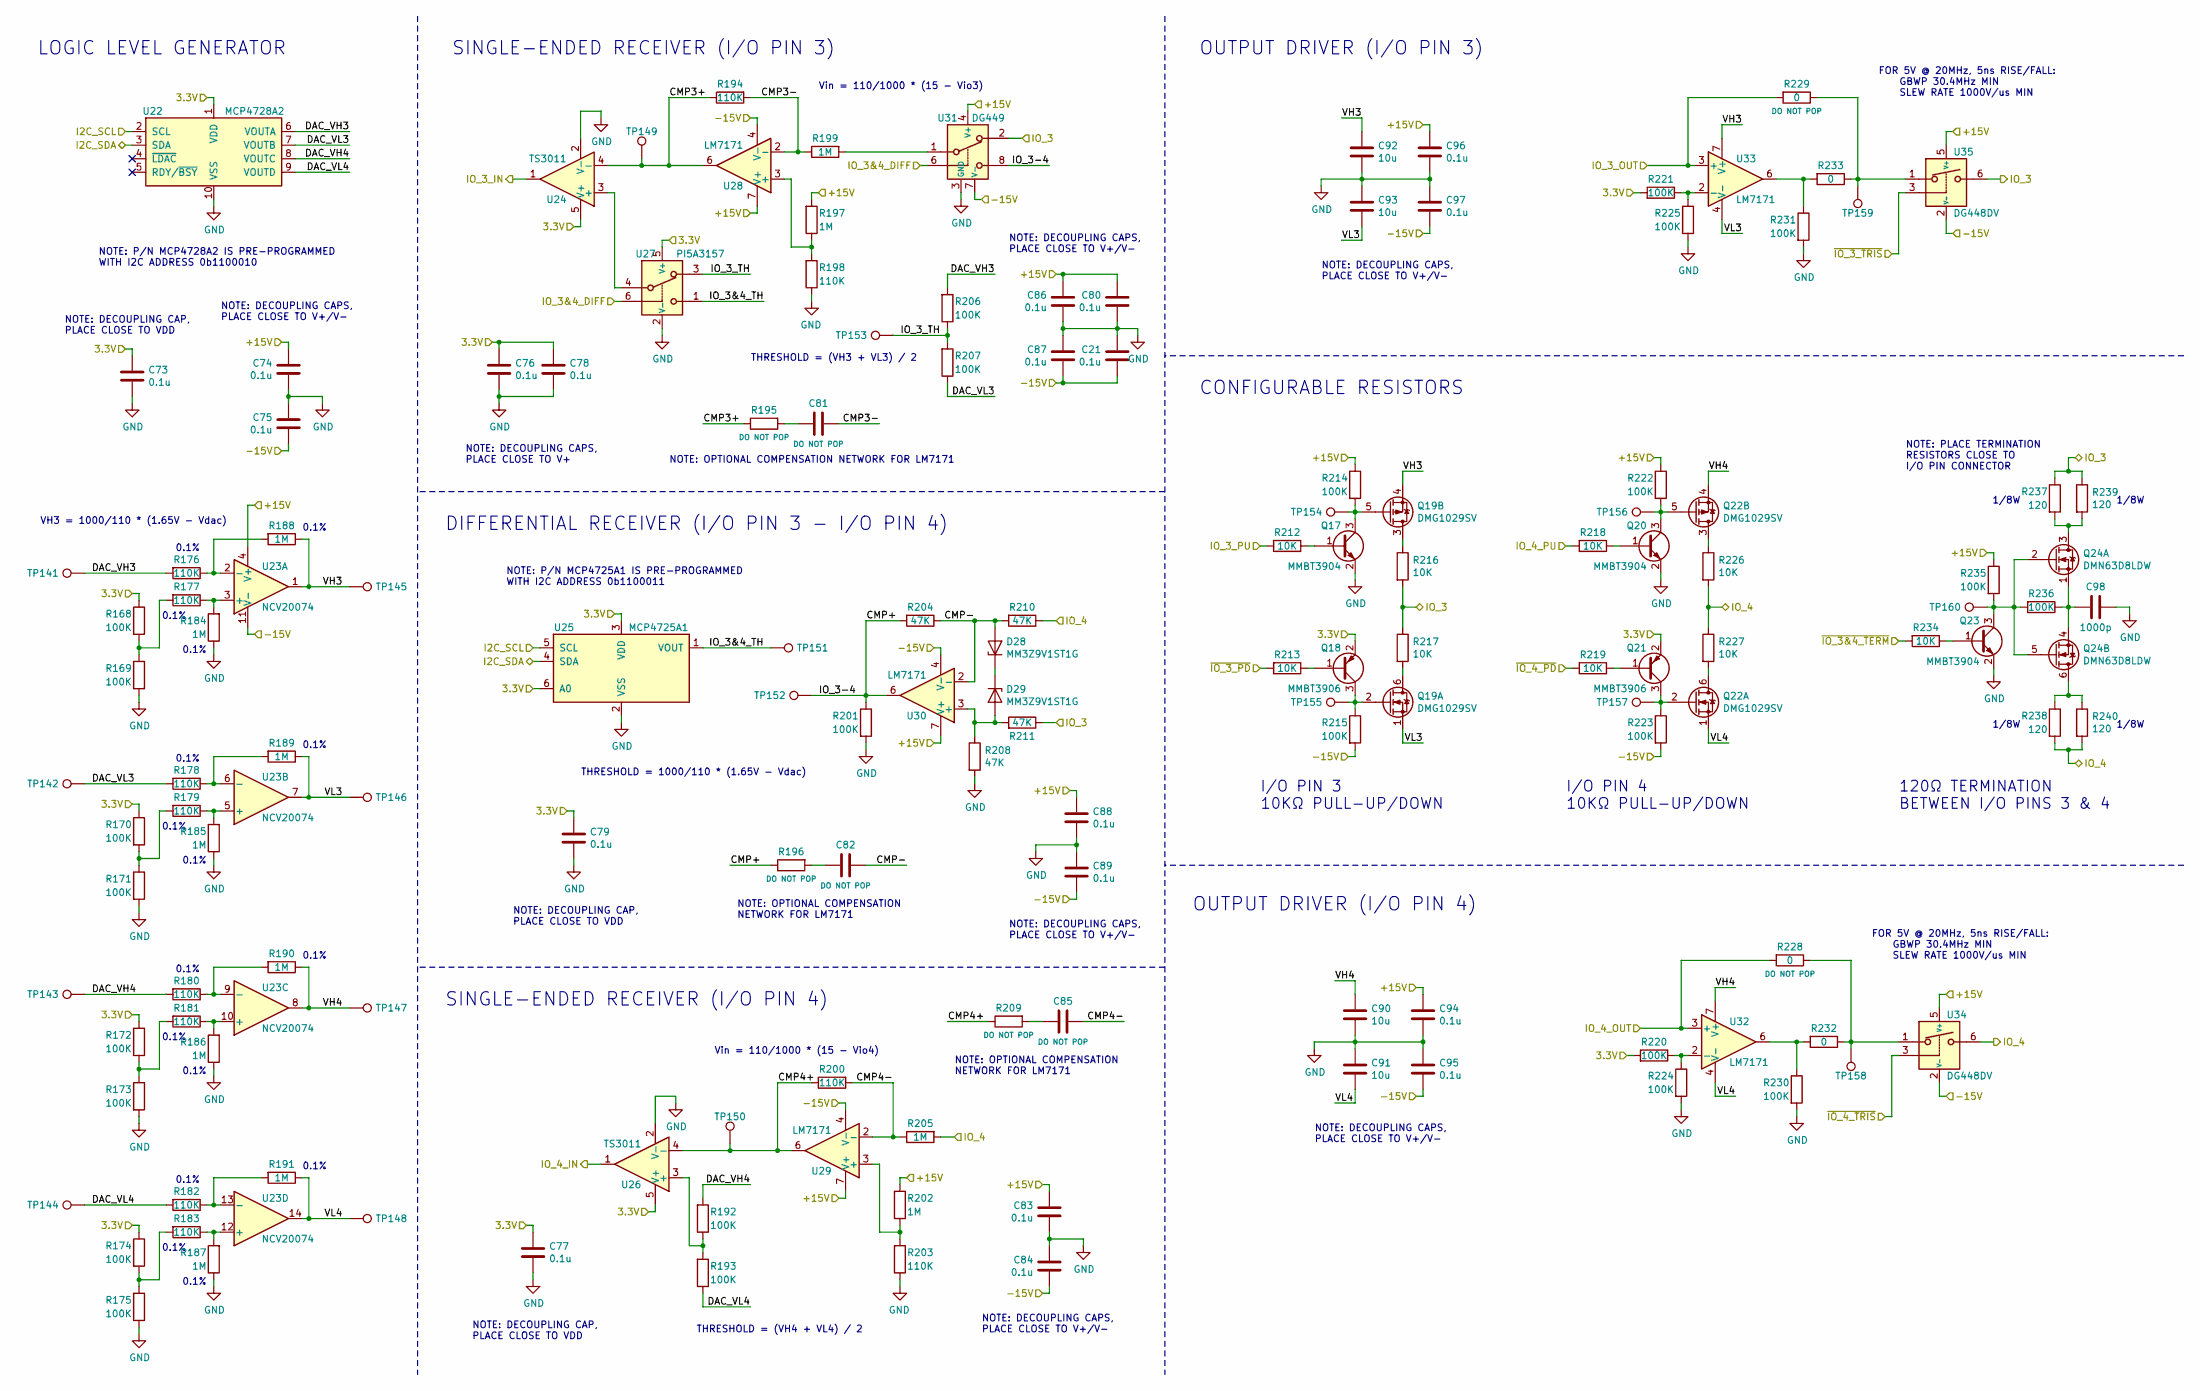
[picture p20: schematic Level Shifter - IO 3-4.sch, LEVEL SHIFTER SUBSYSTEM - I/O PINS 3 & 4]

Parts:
C21, C73, C74, C75, C76, C77, C78, C79, C80, C83, C84, C86, C87, C88, C89, C94, C95, C96, C97: 0.1u; C_0603_1608Metric
C81, C82, C85: C; C_0603_1608Metric
C90, C91, C92, C93: 10u; C_0805_2012Metric
C98: 1000p; C_0603_1608Metric
D28, D29: MM3Z9V1ST1G; D_SOD-323
Q17, Q20, Q23: MMBT3904; SOT-323_SC-70
Q18, Q21: MMBT3906; SOT-323_SC-70
Q19, Q22: DMG1029SV; SOT-563
Q24: DMN63D8LDW; SOT-363_SC-70-6
R168, R169, R170, R171, R172, R173, R174, R175, R192, R193, R201, R206, R207, R214, R215, R220, R221, R222, R223, R224, R225, R230, R231, R235, R236: 100K; R_0603_1608Metric
R176, R177, R178, R179, R180, R181, R182, R183, R194, R198, R200, R203: 110K; R_0603_1608Metric
R184, R185, R186, R187, R188, R189, R190, R191, R197, R199, R202, R205: 1M; R_0603_1608Metric
R195, R196, R209: R; R_0603_1608Metric
R204, R208, R210, R211: 47K; R_0603_1608Metric
R212, R213, R216, R217, R218, R219, R226, R227, R234: 10K; R_0603_1608Metric
R228, R229, R232, R233: 0; R_0603_1608Metric
R237, R238, R239, R240: 120; R_0805_2012Metric
TP141: DVH3; TestPoint_Pad_D1.0mm
TP142: DVL3; TestPoint_Pad_D1.0mm
TP143: DVH4; TestPoint_Pad_D1.0mm
TP144: DVL4; TestPoint_Pad_D1.0mm
TP145: VH3; TestPoint_Pad_D1.0mm
TP146: VL3; TestPoint_Pad_D1.0mm
TP147: VH4; TestPoint_Pad_D1.0mm
TP148: VL4; TestPoint_Pad_D1.0mm
TP149, TP150, TP154, TP155, TP156, TP157, TP158, TP159, TP160: TestPoint; TestPoint_Pad_D1.0mm
TP151: TH34; TestPoint_Pad_D1.0mm
TP152: 3-4; TestPoint_Pad_D1.0mm
TP153: TH3; TestPoint_Pad_D1.0mm
U22: MCP4728A2; MSOP-10_3x3mm_P0.5mm
U23: NCV20074; TSSOP-14_4.4x5mm_P0.65mm
U24, U26: TS3011; SOT-353_SC-70-5
U25: MCP4725A1; SOT-23-6
U27: PI5A3157; SOT-363_SC-70-6
U28, U29, U30, U32, U33: LM7171; SOIC-8_3.9x4.9mm_P1.27mm
U31: DG449; SOT-23-8
U34, U35: DG448DV; TSOP-6_1.65x3.05mm_P0.95mm

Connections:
/3.3V: C73.1, C76.1, C77.1, C78.1, C79.1, Q18.2 (E), Q21.2 (E), R168.1, R170.1, R172.1, R174.1, R220.2, R221.2, U22.1 (VDD), U24.5 (V+), U25.3 (VDD), U25.6 (A0), U26.5 (V+), U27.5 (V+); also elsewhere on the board
/+15V: C74.1, C80.1, C83.1, C86.1, C88.1, C94.1, C96.1, R197.2, R202.2, R214.1, R222.1, R235.1, U23.4 (V+), U28.7 (V+), U29.7 (V+), U30.7 (V+), U31.4 (V+), U34.5 (V+), U35.5 (V+); also elsewhere on the board
/-15V: C21.2, C75.2, C84.2, C87.2, C89.2, C95.2, C97.2, R215.2, R223.2, U23.11 (V-), U28.4 (V-), U29.4 (V-), U30.4 (V-), U31.7 (V-), U34.2 (V-), U35.2 (V-); also elsewhere on the board
/Circuit Protection - I/O Pin 3/IO_3: R211.1, R216.2, R217.1, R237.1, R239.1, U31.2, U35.6; also elsewhere on the board
/Circuit Protection - I/O Pin 4/IO_4: R205.2, R210.1, R226.2, R227.1, R238.2, R240.2, U34.6; also elsewhere on the board
/Level Shifter - I/O Pins 1&2/I2C_SCL: U22.2 (SCL), U25.5 (SCL); also elsewhere on the board
/Level Shifter - I/O Pins 1&2/I2C_SDA: U22.3 (SDA), U25.4 (SDA); also elsewhere on the board
/Level Shifter - I/O Pins 3&4/CMP3+: R194.1, R195.1, TP149.1, U24.4 (-), U28.6
/Level Shifter - I/O Pins 3&4/CMP3-: C81.1, R194.2, R199.1, U28.2 (-)
/Level Shifter - I/O Pins 3&4/CMP4+: R200.1, R209.1, TP150.1, U26.4 (-), U29.6
/Level Shifter - I/O Pins 3&4/CMP4-: C85.1, R200.2, R205.1, U29.2 (-)
/Level Shifter - I/O Pins 3&4/CMP+: R196.1, R201.1, R204.2, TP152.1, U30.6, U31.8
/Level Shifter - I/O Pins 3&4/CMP-: C82.1, D28.2 (A), R204.1, R210.2, U30.2 (-)
/Level Shifter - I/O Pins 3&4/DAC_VH3: R176.2, R206.2, TP141.1, U22.6 (VOUTA)
/Level Shifter - I/O Pins 3&4/DAC_VH4: R180.2, R192.2, TP143.1, U22.8 (VOUTC)
/Level Shifter - I/O Pins 3&4/DAC_VL3: R178.2, R207.1, TP142.1, U22.7 (VOUTB)
/Level Shifter - I/O Pins 3&4/DAC_VL4: R182.2, R193.1, TP144.1, U22.9 (VOUTD)
/Level Shifter - I/O Pins 3&4/IO_3&4_DIFF: U27.6, U31.6; also elsewhere on the board
/Level Shifter - I/O Pins 3&4/IO_3&4_TH: TP151.1, U25.1 (VOUT), U27.1
/Level Shifter - I/O Pins 3&4/IO_3_IN: U24.1; also elsewhere on the board
/Level Shifter - I/O Pins 3&4/IO_3_OUT: R229.2, U33.3 (+); also elsewhere on the board
/Level Shifter - I/O Pins 3&4/IO_3_PU: R212.2; also elsewhere on the board
/Level Shifter - I/O Pins 3&4/IO_3_TH: R206.1, R207.2, TP153.1, U27.3
/Level Shifter - I/O Pins 3&4/IO_4_IN: U26.1; also elsewhere on the board
/Level Shifter - I/O Pins 3&4/IO_4_OUT: R228.2, U32.3 (+); also elsewhere on the board
/Level Shifter - I/O Pins 3&4/IO_4_PU: R218.2; also elsewhere on the board
/Level Shifter - I/O Pins 3&4/VH3: C92.1, Q19.4 (S), R188.1, TP145.1, U23.1, U33.7 (V+)
/Level Shifter - I/O Pins 3&4/VH4: C90.1, Q22.4 (S), R190.1, TP147.1, U23.8, U32.7 (V+)
/Level Shifter - I/O Pins 3&4/VL3: C93.2, Q19.1 (S), R189.1, TP146.1, U23.7, U33.4 (V-)
/Level Shifter - I/O Pins 3&4/VL4: C91.2, Q22.1 (S), R191.1, TP148.1, U23.14, U32.4 (V-)
/Level Shifter - I/O Pins 3&4/~IO_3&4_TERM: R234.2; also elsewhere on the board
/Level Shifter - I/O Pins 3&4/~IO_3_PD: R213.2; also elsewhere on the board
/Level Shifter - I/O Pins 3&4/~IO_3_TRIS: U35.3; also elsewhere on the board
/Level Shifter - I/O Pins 3&4/~IO_4_PD: R219.2; also elsewhere on the board
/Level Shifter - I/O Pins 3&4/~IO_4_TRIS: U34.3; also elsewhere on the board
GND: C21.1, C73.2, C74.2, C75.1, C76.2, C77.2, C78.2, C79.2, C80.2, C83.2, C84.1, C86.2, C87.1, C88.2, C89.1, C90.2, C91.1, C92.2, C93.1, C94.2, C95.1, C96.2, C97.1, C98.1, Q17.2 (E), Q20.2 (E), Q23.2 (E), R169.2, R171.2, R173.2, R175.2, R184.1, R185.1, R186.1, R187.1, R198.1, R201.2, R203.1, R208.2, R224.2, R225.2, R230.2, R231.2, U22.10 (VSS), U24.2 (V-), U25.2 (VSS), U26.2 (V-), U27.2 (V-), U31.3 (GND); also elsewhere on the board
unnamed: C81.2, R195.2
unnamed: C82.2, R196.2
unnamed: C85.2, R209.2
unnamed: C98.2, Q24.1 (S), Q24.4 (S), R236.1
unnamed: D28.1 (K), D29.1 (K)
unnamed: D29.2 (A), R208.1, R211.2, U30.3 (+)
unnamed: Q17.1 (B), R212.1
unnamed: Q17.3 (C), Q19.5 (G), R214.2, TP154.1
unnamed: Q18.1 (B), R213.1
unnamed: Q18.3 (C), Q19.2 (G), R215.1, TP155.1
unnamed: Q19.3 (D), R216.1
unnamed: Q19.6 (D), R217.2
unnamed: Q20.1 (B), R218.1
unnamed: Q20.3 (C), Q22.5 (G), R222.2, TP156.1
unnamed: Q21.1 (B), R219.1
unnamed: Q21.3 (C), Q22.2 (G), R223.1, TP157.1
unnamed: Q22.3 (D), R226.1
unnamed: Q22.6 (D), R227.2
unnamed: Q23.1 (B), R234.1
unnamed: Q23.3 (C), Q24.2 (G), Q24.5 (G), R235.2, R236.2, TP160.1
unnamed: Q24.3 (D), R237.2, R239.2
unnamed: Q24.6 (D), R238.1, R240.1
unnamed: R168.2, R169.1, R177.2
unnamed: R170.2, R171.1, R179.2
unnamed: R172.2, R173.1, R181.2
unnamed: R174.2, R175.1, R183.2
unnamed: R176.1, R188.2, U23.2 (-)
unnamed: R177.1, R184.2, U23.3 (+)
unnamed: R178.1, R189.2, U23.6 (-)
unnamed: R179.1, R185.2, U23.5 (+)
unnamed: R180.1, R190.2, U23.9 (-)
unnamed: R181.1, R186.2, U23.10 (+)
unnamed: R182.1, R191.2, U23.13 (-)
unnamed: R183.1, R187.2, U23.12 (+)
unnamed: R192.1, R193.2, U26.3 (+)
unnamed: R197.1, R198.2, U28.3 (+)
unnamed: R199.2, U31.1
unnamed: R202.1, R203.2, U29.3 (+)
unnamed: R220.1, R224.1, U32.2 (-)
unnamed: R221.1, R225.1, U33.2 (-)
unnamed: R228.1, R232.1, TP158.1, U34.1
unnamed: R229.1, R233.1, TP159.1, U35.1
unnamed: R230.1, R232.2, U32.6
unnamed: R231.1, R233.2, U33.6
unnamed: U24.3 (+), U27.4

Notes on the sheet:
CONFIGURABLE RESISTORS
LOGIC LEVEL GENERATOR
OUTPUT DRIVER (I/O PIN 3)
OUTPUT DRIVER (I/O PIN 4)
DIFFERENTIAL RECEIVER (I/O PIN 3 - I/O PIN 4)
SINGLE-ENDED RECEIVER (I/O PIN 3)
SINGLE-ENDED RECEIVER (I/O PIN 4)
NOTE: DECOUPLING CAP, PLACE CLOSE TO VDD
VH3 = 1000/110 * (1.65V - Vdac)
NOTE: DECOUPLING CAPS, PLACE CLOSE TO V+/V-
NOTE: P/N MCP4728A2 IS PRE-PROGRAMMED WITH I2C ADDRESS 0b1100010
1/8W
NOTE: PLACE TERMINATION RESISTORS CLOSE TO I/O PIN CONNECTOR
FOR 5V @ 20MHz, 5ns RISE/FALL: GBWP 30.4MHz MIN SLEW RATE 1000V/us MIN
0.1%
NOTE: P/N MCP4725A1 IS PRE-PROGRAMMED WITH I2C ADDRESS 0b1100011
Vin = 110/1000 * (15 - Vio3)
THRESHOLD = (VH3 + VL3) / 2
Vin = 110/1000 * (15 - Vio4)
THRESHOLD = (VH4 + VL4) / 2
NOTE: DECOUPLING CAPS, PLACE CLOSE TO V+
THRESHOLD = 1000/110 * (1.65V - Vdac)
I/O PIN 3 10KΩ PULL-UP/DOWN
I/O PIN 4 10KΩ PULL-UP/DOWN
120Ω TERMINATION BETWEEN I/O PINS 3 & 4
NOTE: OPTIONAL COMPENSATION NETWORK FOR LM7171
NOTE: OPTIONAL COMPENSATION NETWORK FOR LM7171

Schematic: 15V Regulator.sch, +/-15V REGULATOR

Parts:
C99, C109, C110: C; C_1210_3225Metric
C100: 10u; C_0805_2012Metric
C101, C106: 1u; C_0603_1608Metric
C102, C103: C; C_0603_1608Metric
C104: 0.22u; C_0603_1608Metric
C105: 82p; C_0603_1608Metric
C107, C108: 22u; C_1210_3225Metric
D30, D31: NSR0530HT1G; D_SOD-323
L2: 10u; L_Abracon_ASPI-0418FS
L3: 15u; L_Taiyo-Yuden_NR-50xx
R241: 5.36K; R_0603_1608Metric
R242: 390K; R_0603_1608Metric
R243: 2.43M; R_0603_1608Metric
R244: 137K; R_0603_1608Metric
R245: 118K; R_0603_1608Metric
R246: 2.32M; R_0603_1608Metric
TP161: SS; TestPoint_Pad_D1.0mm
TP162: SLEW; TestPoint_Pad_D1.0mm
TP163: SEQ; TestPoint_Pad_D1.0mm
TP164: INBK; TestPoint_Pad_D1.0mm
TP165: SW2; TestPoint_Pad_D1.0mm
TP166: SW1; TestPoint_Pad_D1.0mm
TP167: FB1; TestPoint_Pad_D1.0mm
TP168: FB2; TestPoint_Pad_D1.0mm
TP169: +15V; TestPoint_Pad_D1.0mm
TP170: -15V; TestPoint_Pad_D1.0mm
U36: ADP5070AREZ; ETSSOP-20-1EP_4.4x6.5mm_P0.65mm_EP3x4.2mm

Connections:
/+15V: C107.1, C109.1, D30.1 (K), R243.1, TP169.1; also elsewhere on the board
/-15V: C108.2, C110.2, D31.2 (A), R246.2, TP170.1; also elsewhere on the board
/Vin: C99.1, C100.1, U36.9 (EN1), U36.11 (EN2), U36.17 (PVIN1), U36.18 (PVINSYS), U36.19 (PVIN2); also elsewhere on the board
GND: C99.2, C100.2, C101.2, C102.2, C103.2, C104.1, C105.1, C106.2, C107.2, C108.1, C109.2, C110.1, L3.2, R244.2, U36.1 (PGND), U36.4 (SYNC/FREQ), U36.15 (AGND), U36.21 (AGND); also elsewhere on the board
unnamed: C101.1, U36.16 (VREG)
unnamed: C102.1, R241.2, U36.12 (COMP2)
unnamed: C103.1, R242.2, U36.8 (COMP1)
unnamed: C104.2, R241.1
unnamed: C105.2, R242.1
unnamed: C106.1, R245.1, U36.14 (VREF)
unnamed: D30.2 (A), L2.2, TP166.1, U36.2 (SW1)
unnamed: D31.1 (K), L3.1, TP165.1, U36.20 (SW2)
unnamed: L2.1, TP164.1, U36.3 (INBK)
unnamed: R243.2, R244.1, TP167.1, U36.7 (FB1)
unnamed: R245.2, R246.1, TP168.1, U36.13 (FB2)
unnamed: TP161.1, U36.10 (SS)
unnamed: TP162.1, U36.6 (SLEW)
unnamed: TP163.1, U36.5 (SEQ)

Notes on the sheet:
+15V SUPPLY (500mA MAX)
-15V SUPPLY (500mA MAX)
INPUT (5-15V)
+/-15V REGULATOR
RECOMMENDED PCB LAYOUT

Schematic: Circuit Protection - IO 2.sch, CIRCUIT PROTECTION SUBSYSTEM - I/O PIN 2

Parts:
C117, C118: 0.1u; C_0603_1608Metric
D33, D34: 1N4148; D_SOD-323
D35: RED; LED_0603_1608Metric
D38, D39: MM3Z15VST1G; D_SOD-323
Q25: DMN63D8LDW; SOT-363_SC-70-6
Q26: MMBT3906; SOT-323_SC-70
R247: 2; R_0603_1608Metric
R248, R249, R260, R261: 10K; R_0603_1608Metric
R250, R251, R252, R253, R254, R255, R256, R257, R259: 100K; R_0603_1608Metric
R258: 6.8K; R_0603_1608Metric
TP171, TP172, TP173: TestPoint; TestPoint_Pad_D1.0mm
U37: NCV20074; TSSOP-14_4.4x5mm_P0.65mm

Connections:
/+15V: C117.1, Q26.2 (E), R257.1, U37.4 (V+); also elsewhere on the board
/-15V: C118.2, U37.11 (V-); also elsewhere on the board
/Circuit Protection - I/O Pin 2/IO_2: D38.2 (A), R247.2, R249.2; also elsewhere on the board
/Circuit Protection - I/O Pin 2/TARGET_IO_2: Q25.6 (D); also elsewhere on the board
GND: C117.2, C118.1, D39.2 (A), R250.2, R258.2, R261.2, U37.5 (+); also elsewhere on the board
unnamed: D33.1 (K), D34.2 (A), U37.7
unnamed: D33.2 (A), R253.1, R255.2
unnamed: D34.1 (K), R254.1, U37.10 (+)
unnamed: D35.1 (K), R261.1
unnamed: D35.2 (A), Q26.3 (C)
unnamed: D38.1 (K), D39.1 (K)
unnamed: Q25.1 (S), Q25.4 (S), R259.1
unnamed: Q25.2 (G), Q25.5 (G), R259.2, R260.2, TP173.1, U37.14
unnamed: Q25.3 (D), R247.1, R248.2
unnamed: Q26.1 (B), R260.1
unnamed: R248.1, R251.2, U37.2 (-)
unnamed: R249.1, R250.1, U37.3 (+)
unnamed: R251.1, R252.2, TP171.1, U37.1
unnamed: R252.1, R253.2, R254.2, U37.6 (-)
unnamed: R255.1, R256.2, U37.9 (-)
unnamed: R256.1, TP172.1, U37.8, U37.13 (-)
unnamed: R257.2, R258.1, U37.12 (+)

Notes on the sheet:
OVERVOLTAGE PROTECTION
OVERCURRENT PROTECTION
Vshunt = abs(10 * Ishunt * Rshunt)
Vlimit = 10 * Ilimit * Rshunt
Vlimit
TRANSISTOR POWER DISSIPATION: (WORST CASE: OUPUTTING +15V, PIN SHORTED TO -15V) Pq = (15V - -15V) * 50mA = 1.5W MAX AVG Pq IS 275mW, ALLOWABLE DUTY CYCLE IS 0.275 / 1.5 = 0.18 (10 SEC SHORT CIRCUIT OVER 1 MIN)
CURRENT LIMIT LED
OVERVOLTAGES LIMITED TO +/-15.56V Vf = 0.9V Vz = 14.66V
NOTE: DECOUPLING CAPS, PLACE CLOSE TO V+/V-

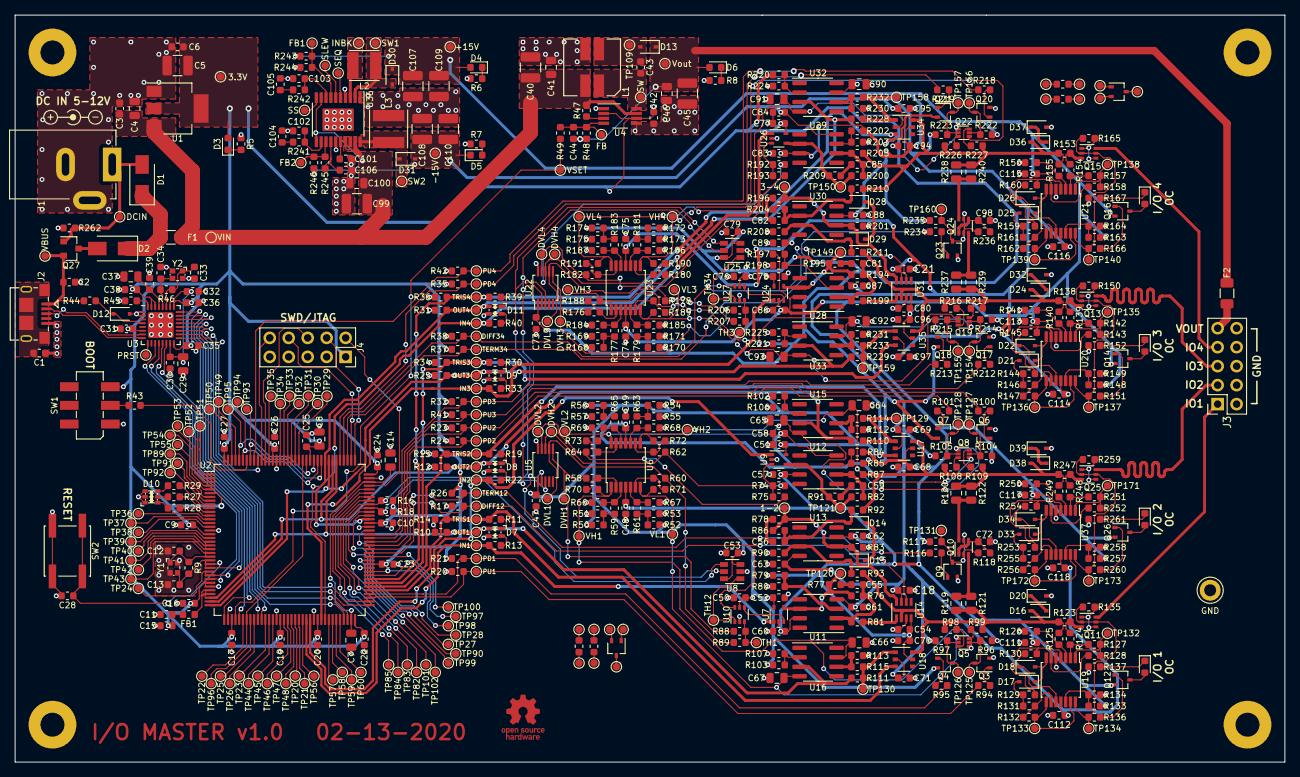
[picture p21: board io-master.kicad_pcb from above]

Board: 4 copper layers, 170.0 x 100.0 mm, 671 parts (0 on the bottom side), 377 nets.

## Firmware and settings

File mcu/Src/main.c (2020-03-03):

/**
  ******************************************************************************
  * @file           : (main.c
  * @brief          : Main program body
  ******************************************************************************
  * @attention
  *
  * <h2><center>&copy; Copyright (c) 2019 STMicroelectronics.
  * All rights reserved.</center></h2>
  *
  * This software component is licensed by ST under Ultimate Liberty license
  * SLA0044, the "License"; You may not use this file except in compliance with
  * the License. You may obtain a copy of the License at:
  *                             www.st.com/SLA0044
  *
  ******************************************************************************
  */

#include "main.h"
#include "iopin.h"
#include "data.h"
#include "core.h"
#include "clock.h"
#include "gpio.h"
#include "io_dma.h"
#include "timer.h"
#include "dac.h"
#include "uart.h"
#include "stm32h7xx_hal_dma.h"
#include "stm32h743xx.h"
#include "log.h"
#include <stdlib.h>

#if defined( __ICCARM__ )
  #define DMA_BUFFER \
      _Pragma("location=\".dma_buffer\"")
#else
  #define DMA_BUFFER \
      __attribute__((section(".dma_buffer")))
#endif

uint8_t DMABusyFlag = 0;



int main(void)
{
  HAL_Init();
  __HAL_RCC_SYSCFG_CLK_ENABLE();
  InitSystemClock();
  InitGPIO();
  InitDAC();
  InitI2CDAC();
  IOM_ERROR err = InitUART();
  if (err == IOM_ERROR_INVALID) {
    HAL_Delay(1000);
  }
  uint8_t* pData = malloc(1);
  UARTQueueRXData(pData, 1);


  //InitUSB();
  //InitTimers();
  //InitDMA();

  while (1) {
    HAL_GPIO_TogglePin(STATUS_B_GPIO_Port, STATUS_B_Pin);
    HAL_GPIO_TogglePin(STATUS_B_GPIO_Port, STATUS_B_Pin);
    HAL_Delay(1000);

  }


  while (1)
  {

    //If the output queue is not empty and the DMA is not busy
    uint32_t counter = __HAL_DMA_GET_COUNTER(htim8.hdma[TIM_DMA_ID_CC4]);
    if ((output_buf_queue_size > 0) && (counter == 0)) {
      if (DMABusyFlag != 0) {
        ResetDMA();
        DMABusyFlag = 0;
      }
      DMABusyFlag = 1;
      SendOutputData();
      //Send the front of the output queue over DMA
    }
  }
}

/************************ (C) COPYRIGHT STMicroelectronics *****END OF FILE****/

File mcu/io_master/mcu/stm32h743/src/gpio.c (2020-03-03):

#include "gpio.h"
#include <stdint.h>
#include <unistd.h>
#include "stm32h7xx_hal.h"
#include "stm32h743xx.h"
#include "mcu_conf.h"

IOM_ERROR InitGPIO(void) {

  GPIO_InitTypeDef GPIO_InitStruct = {0};


  //Enable GPIO Port Clocks
  __HAL_RCC_GPIOA_CLK_ENABLE();
  __HAL_RCC_GPIOB_CLK_ENABLE();
  __HAL_RCC_GPIOC_CLK_ENABLE();
  __HAL_RCC_GPIOD_CLK_ENABLE();
  __HAL_RCC_GPIOE_CLK_ENABLE();
  __HAL_RCC_GPIOF_CLK_ENABLE();
  __HAL_RCC_GPIOG_CLK_ENABLE();
  __HAL_RCC_GPIOH_CLK_ENABLE();

  //Determine what pins should be set to High (Active Low).
  //All other pins will be set to Low (Active High)
  const uint16_t GPIOA_SET_PINS = 0
  ;

  const uint16_t GPIOB_SET_PINS = 0
  | IO_1_PD_N_Pin
  #ifdef IOM_8_IO_PINS
  | IO_6_PD_N_Pin
  #endif
  | nRESET_Pin
  ;

  const uint16_t GPIOC_SET_PINS = 0
  | IO_3_4_TERM_N_Pin
  | IO_4_PD_N_Pin
  #ifdef IOM_8_IO_PINS
  | IO_5_6_TERM_N_Pin
  | IO_7_8_TERM_N_Pin
  | IO_7_PD_N_Pin
  | IO_8_PD_N_Pin
  #endif
  ;

  const uint16_t GPIOD_SET_PINS = 0
  | IO_1_TRIS_N_Pin
  | IO_2_TRIS_N_Pin
  | IO_3_TRIS_N_Pin
  | IO_4_TRIS_N_Pin
  #ifdef IOM_8_IO_PINS
  | IO_5_TRIS_N_Pin
  | IO_6_TRIS_N_Pin
  | IO_7_TRIS_N_Pin
  | IO_8_TRIS_N_Pin
  #endif
  ;

  const uint16_t GPIOE_SET_PINS = 0
  ;

  const uint16_t GPIOF_SET_PINS = 0
  ;

  const uint16_t GPIOG_SET_PINS = 0
  | IO_2_PD_N_Pin
  | IO_3_PD_N_Pin
  | IO_1_2_TERM_N_Pin
  #ifdef IOM_8_IO_PINS
  | IO_5_PD_N_Pin
  #endif
  ;

  const uint16_t GPIOH_SET_PINS = 0
  ;

//TODO determine if this pragma is the only way to avoid
// the overflow error for GPIOB set RESET pins
#pragma GCC diagnostic push
#pragma GCC diagnostic ignored "-Woverflow"
  //Write all of the pin states
  HAL_GPIO_WritePin(GPIOA, GPIOA_SET_PINS, GPIO_PIN_SET);
  HAL_GPIO_WritePin(GPIOA, ~GPIOA_SET_PINS, GPIO_PIN_RESET);

  HAL_GPIO_WritePin(GPIOB, GPIOB_SET_PINS, GPIO_PIN_SET);

  HAL_GPIO_WritePin(GPIOB, ~GPIOB_SET_PINS, GPIO_PIN_RESET);

  HAL_GPIO_WritePin(GPIOC, GPIOC_SET_PINS, GPIO_PIN_SET);
  HAL_GPIO_WritePin(GPIOC, ~GPIOC_SET_PINS, GPIO_PIN_RESET);

  HAL_GPIO_WritePin(GPIOD, GPIOD_SET_PINS, GPIO_PIN_SET);
  HAL_GPIO_WritePin(GPIOD, ~GPIOD_SET_PINS, GPIO_PIN_RESET);

  HAL_GPIO_WritePin(GPIOE, GPIOE_SET_PINS, GPIO_PIN_SET);
  HAL_GPIO_WritePin(GPIOE, ~GPIOE_SET_PINS, GPIO_PIN_RESET);

  HAL_GPIO_WritePin(GPIOF, GPIOF_SET_PINS, GPIO_PIN_SET);
  HAL_GPIO_WritePin(GPIOF, ~GPIOF_SET_PINS, GPIO_PIN_RESET);

  HAL_GPIO_WritePin(GPIOG, GPIOG_SET_PINS, GPIO_PIN_SET);
  HAL_GPIO_WritePin(GPIOG, ~GPIOG_SET_PINS, GPIO_PIN_RESET);

  HAL_GPIO_WritePin(GPIOH, GPIOH_SET_PINS, GPIO_PIN_SET);
  HAL_GPIO_WritePin(GPIOH, ~GPIOH_SET_PINS, GPIO_PIN_RESET);
#pragma GCC diagnostic pop

  //Default input pin configuration (Clock and I/O In/Out Pins)
  const uint16_t GPIOA_INPUT_PINS = 0
  | IO_1_CLK_Pin
  | IO_2_CLK_Pin
  | IO_3_CLK_Pin
  #ifdef IOM_8_IO_PINS
  | IO_8_CLK_Pin
  #endif
  ;

  const uint16_t GPIOB_INPUT_PINS = 0
  #ifdef IOM_8_IO_PINS
  | IO_5_CLK_Pin
  | IO_6_CLK_Pin
  | IO_7_CLK_Pin
  #endif
  ;

  const uint16_t GPIOC_INPUT_PINS = 0
  | IO_4_CLK_Pin
  ;

  const uint16_t GPIOD_INPUT_PINS = 0
  | IO_1_OUT_Pin
  | IO_2_OUT_Pin
  | IO_3_OUT_Pin
  | IO_4_OUT_Pin
  #ifdef IOM_8_IO_PINS
  | IO_5_OUT_Pin
  | IO_6_OUT_Pin
  | IO_7_OUT_Pin
  | IO_8_OUT_Pin
  #endif
  ;

  const uint16_t GPIOE_INPUT_PINS = 0
  | IO_1_IN_Pin
  | IO_2_IN_Pin
  | IO_3_IN_Pin
  | IO_4_IN_Pin
  #ifdef IOM_8_IO_PINS
  | IO_5_IN_Pin
  | IO_6_IN_Pin
  | IO_7_IN_Pin
  | IO_8_IN_Pin
  #endif
  ;
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

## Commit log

2019-10-30 Add hardware v0 basic schematic
    [24V Regulator.sch, 3.3V Regulator.sch, Adjustable Regulator.sch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]
2019-10-30 LED usb test
2019-10-31 Add +/-24V regulator design
    [24V Regulator.sch]
2019-11-06 Add 24V regulator demo board
    [24_regulator_demo-B_Cu.gbr, 24_regulator_demo-B_Mask.gbr, 24_regulator_demo-Edge_Cuts.gbr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]
2019-11-07 Add device config demo board
    [device-config-demo-B_Cu.gbr, device-config-demo-B_Mask.gbr, device-config-demo-Edge_Cuts.gbr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]
2019-11-07 Clean up 24v regulator demo board
    [BOM.xlsx]
2019-11-07 Clean up device config demo board
    [BOM.xlsx, device-config-demo.sch]
2019-11-07 Add level shifter demo board
    [level-shifter-demo-B_Cu.gbr, level-shifter-demo-B_Mask.gbr, level-shifter-demo-Edge_Cuts.gbr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]
2019-11-07 Update KiCAD symbol library
    [device-config-demo.sch, level-shifter-demo.sch]
2019-11-07 Remove unnecessary footprint position file
2019-11-07 Add level shifter demo board BOM
    [BOM.xlsx]
2019-11-11 Update device config demo board fab drawing
    [device-config-demo.kicad_pcb]
2019-11-12 Add support for DMA on GPIOF (working)
2019-11-14 add support to control i2c for power rails
2020-02-04 Clean up files
    [24V Regulator.sch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]
2020-02-04 Add v1 schematic design
    [15V Regulator.sch, Adjustable Regulator.sch, Circuit Protection - IO 1.sch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]
2020-02-05 Add power changeover circuit, fix minor issues
    [15V Regulator.sch, Adjustable Regulator.sch, Circuit Protection - IO 1.sch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]
2020-02-05 Replace switches U14 and U31 with higher voltage part
    [Level Shifter - IO 1-2.sch, Level Shifter - IO 3-4.sch]
2020-02-05 Change barrel jack to cheaper part, add footprint
    [15V Regulator.sch, Adjustable Regulator.sch, Circuit Protection - IO 1.sch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]
2020-02-05 Add custom footprints for crystals, leds, inductors, etc.
2020-02-07 Assign footprints, fix minor schematic issues
    [15V Regulator.sch, Adjustable Regulator.sch, Circuit Protection - IO 1.sch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]
2020-02-07 Add PTC fuses on Vin and Vout
    [15V Regulator.sch, Adjustable Regulator.sch, Circuit Protection - IO 1.sch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]
2020-02-08 Remove extra caps C18 and C21 on VDDA pin
    [Microcontroller.sch]
2020-02-10 Add C18 and C21 0.1u decoupling caps, fix minor issues
    [15V Regulator.sch, Adjustable Regulator.sch, Circuit Protection - IO 1.sch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]
2020-02-10 Add 2x5 pin header footprint w/ alternate numbering
2020-02-13 Update microcontroller pin assignments
    [15V Regulator.sch, Adjustable Regulator.sch, Circuit Protection - IO 1.sch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]
2020-02-13 Add v1.0 PCB layout
    [io-master-B_Cu.gbr, io-master-B_Mask.gbr, io-master-Edge_Cuts.gbr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]
2020-02-20 Remove some of the auto gen templating comments as code generation is no longer needed
    [io_dma.c, main.c]
2020-02-20 Move pin definitions for mcu_conf.h
2020-02-20 organize mcu_conf.h pin definitions
2020-02-20 Add init functions for DMA and TIM8
2020-02-22 Clean device initialization header files, organize GPIO pin initialization
2020-02-26 Add I2C Intiialization
2020-02-27 Add initialization for UART interface
2020-02-27 Add support for UART and logging
2020-02-27 Fix issues with GPIO outputs causing dev board to freeze. Blinking LED test on STATUS_R output
    [gpio.c, main.c]
2020-02-29 Add queueing system for UART TX
2020-03-01 Add UART RX command and parsing command structure
2020-03-03 Clean up command code, confirm pin state configuration works for IO 1
2020-03-03 Update clocks and interfaces for real board
2020-03-03 Finish up DAC config code for actual board
2020-04-25 Add v1.0 BOM
